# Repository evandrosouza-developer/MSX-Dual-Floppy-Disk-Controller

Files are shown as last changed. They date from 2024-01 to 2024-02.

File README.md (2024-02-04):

<div align="center">

**MSX Dual Disk Drive Controller**

**HB720**

***Based on Memory Mapped I/O Registers***

***Compatible with MSX1 class computers AND MSX2/MSX-DOS2.X***

</div>

**EPCOM/SHARP HB-3600**

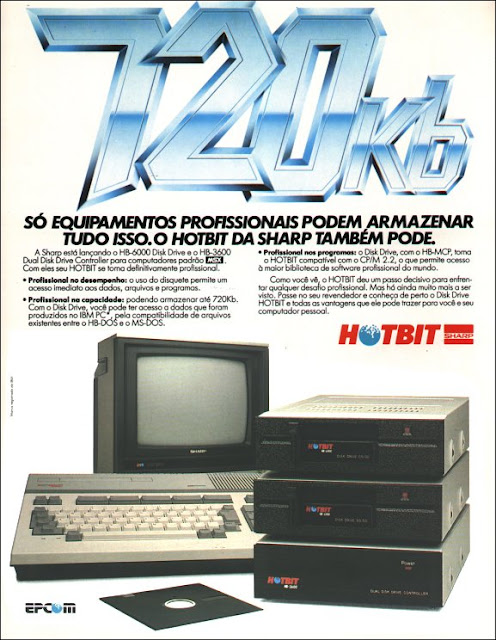
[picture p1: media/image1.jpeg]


**SONY HBD-50**

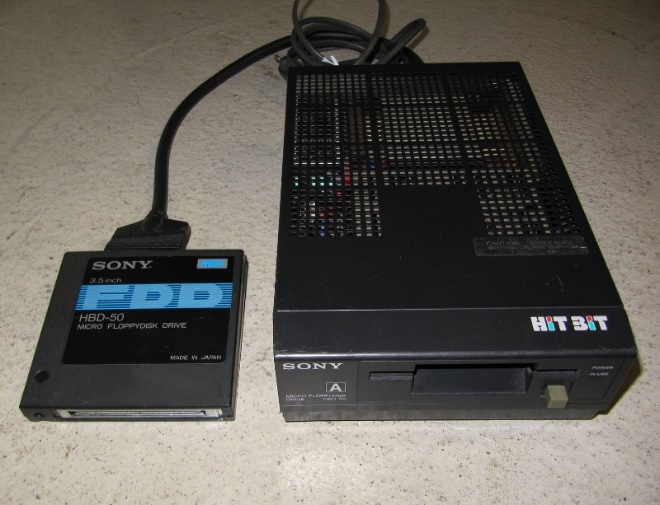
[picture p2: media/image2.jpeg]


***Based on MSXHans, 2001 PDF***

***By Evandro Souza 2024, January.***
  
---

## **THEORY OF OPERATION**

## **2-1. Cartridge Board**

## **2-1-1. MSX-DOS 1.X Version => Compatible with all MSX machines**

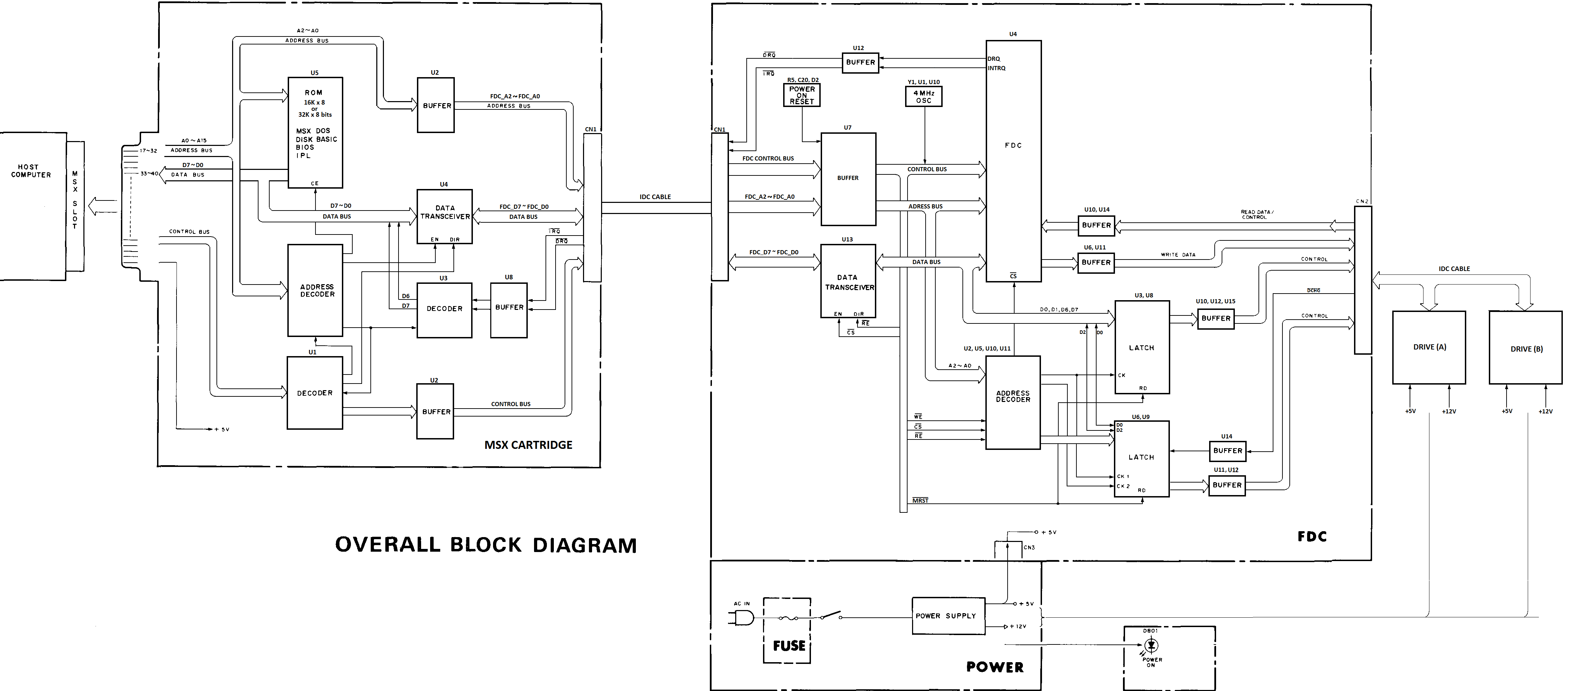
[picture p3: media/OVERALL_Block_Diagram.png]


**2-1-1-1. Memory Map**

This board cartridge uses the MSX computer cartridge slot. 16K ROM addresses 4000H through 7FFFH on the memory map have been allocated to the HB720 cartridge.

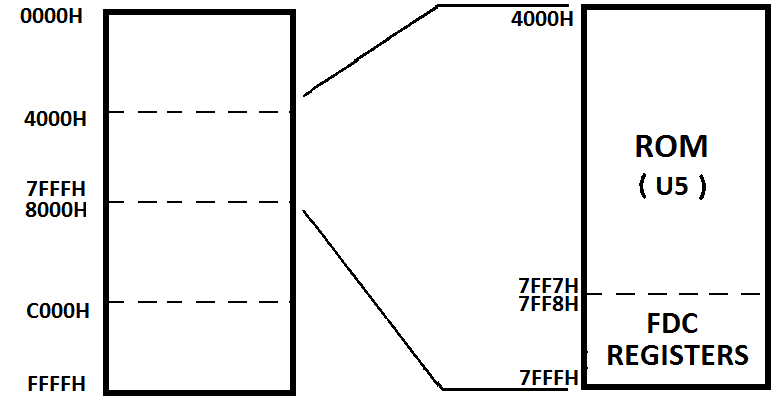
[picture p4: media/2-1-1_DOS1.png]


**2-1-1-2. Selection by HB720 Cartridge**

When the HB720 cartridge has been inserted into the MSX computer cartridge slot, 4000H-7FFFH address space will be selected by the cartridge connector signal CS1. In addition, U1 will AND signal SLTSL and the U2 (address decoder) output that has been inverted by U8, and will provide an output to U5 (ROM) pin CE for selection. All this signals are valid as 0, so the used logic port is an OR.

**2-1-1-3. Selection by FDC Controller**

Individual registers of the FDC board have been allocated to the memory space for addresses 7FF8H-7FFFH, and are selected by address signals A0 through A2 and signal FDC_CS.

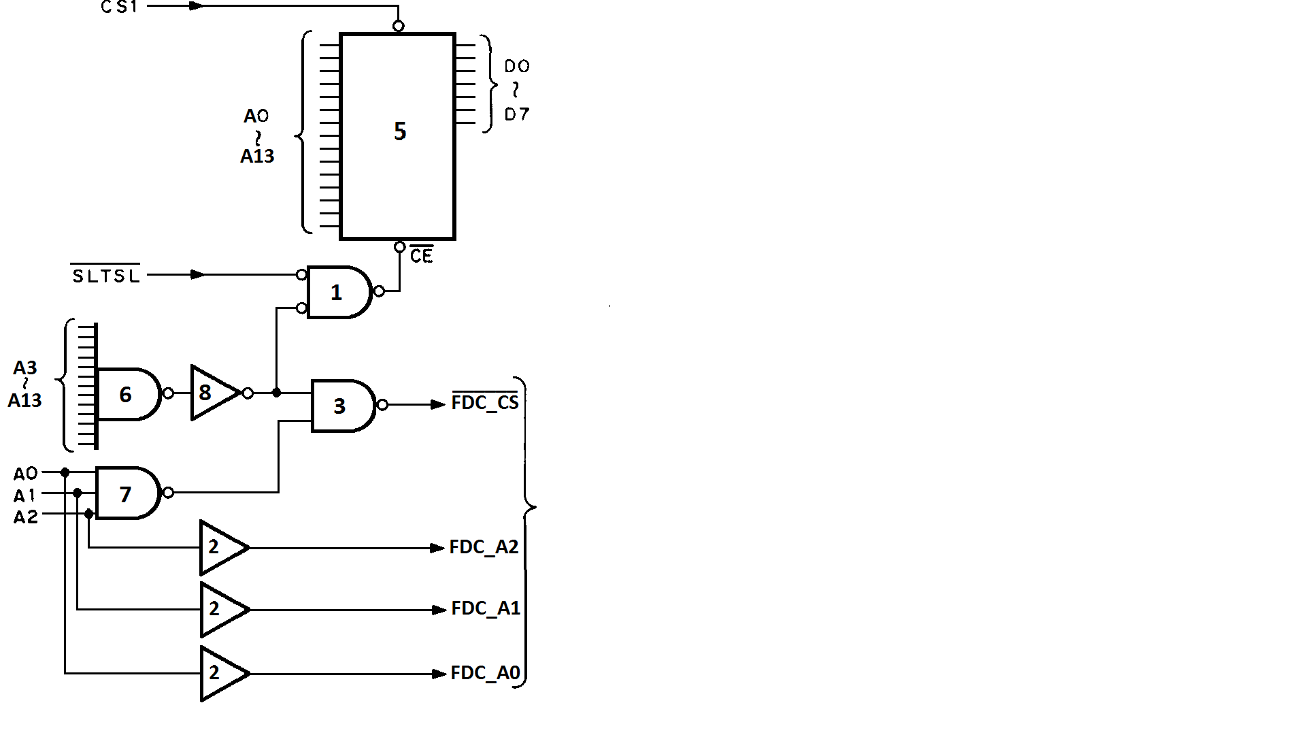
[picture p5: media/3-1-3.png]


**2-1-1-4. Memory Map of Control Ports in detail**

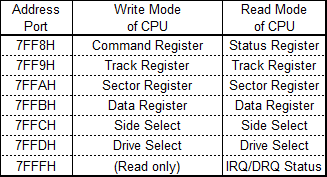
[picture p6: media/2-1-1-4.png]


---

## **2-1-2. MSX-DOS 2.X Version => Compatible with MSX 2.0 and up with Memory Mapper**

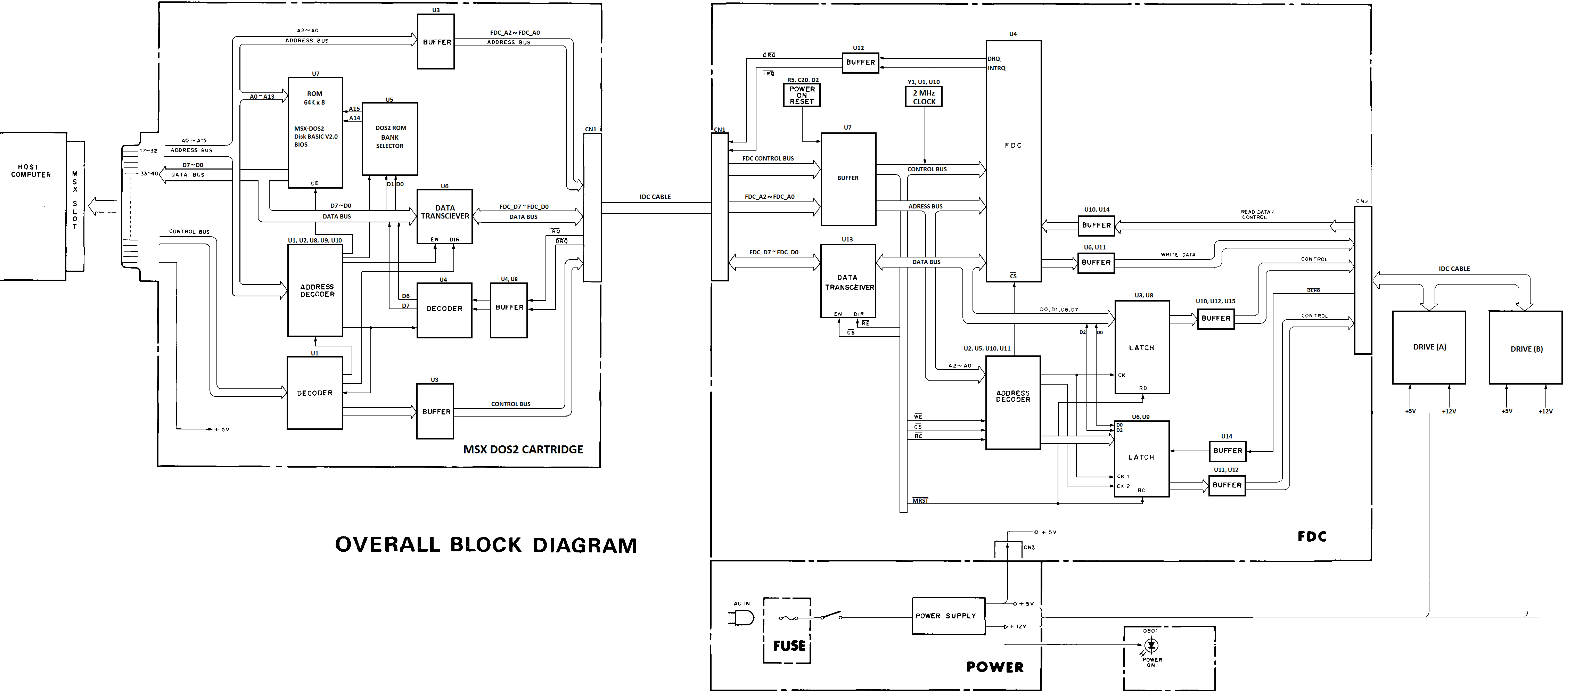
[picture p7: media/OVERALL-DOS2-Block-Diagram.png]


**2-1-2-1. Memory Map**

This board cartridge uses the MSX computer cartridge slot. The 64KB ROM is mapped into banks onto Z80 address space 4000H-7FFFH through U5 (ROM bank selector hardware that sends the A14 and A15 - the high order - bits to U7 ROM) will be selected by the cartridge connector signal CS1. In addition, U1 will AND signal SLTSL and the U2 (address decoder) output that has been inverted by U8, and will provide an output to U7 (ROM) pin CE for selection of the ROM. All this signals are valid as 0 (low), so the used logic port is an OR.

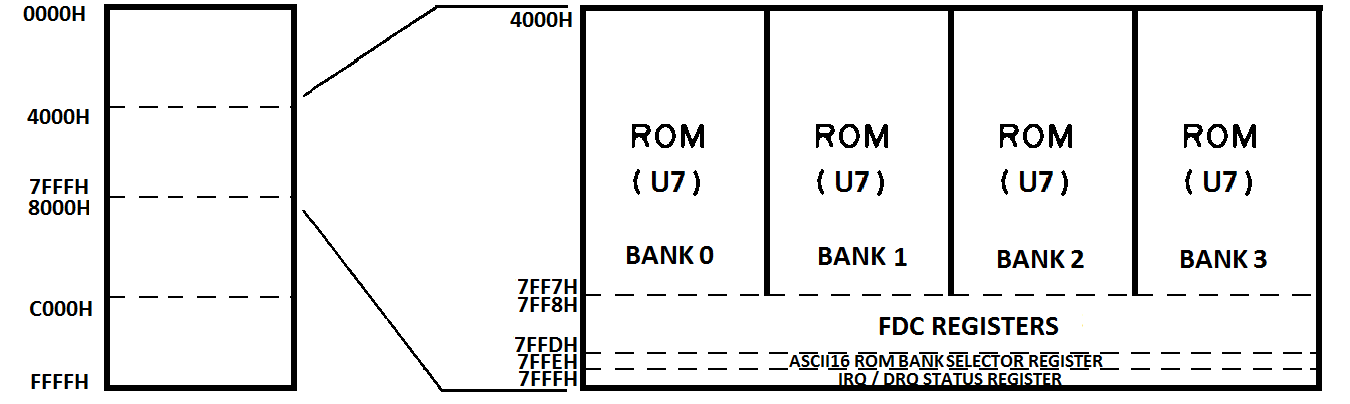
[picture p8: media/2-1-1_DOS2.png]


**2-1-2-2. Selection by HB720 Cartridge**

When the HB720 cartridge has been inserted into the MSX computer cartridge slot, addresses 4000H through 7FFFH will be selected by the cartridge connector signal CS1. U1 will AND signal SLTSL and the U2 (address decoder) output that has been inverted by U8, and will provide an output to U7 (ROM) pin CE for selection of the ROM.

**2-1-2-3. Selection by FDC Controller**

Individual registers of the FDC board have been allocated to the memory space for addresses 7FF8H through 7FFFH, and are selected by address signals A0 through A2 and signal FDC_CS.

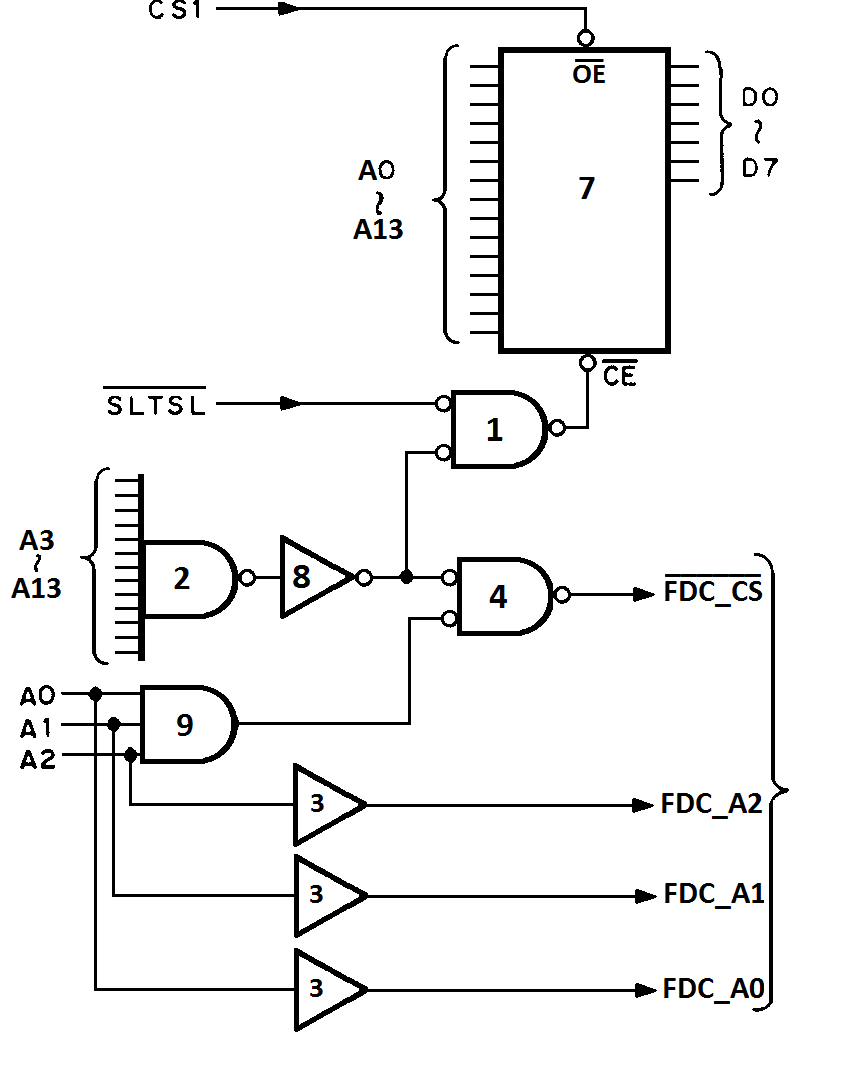
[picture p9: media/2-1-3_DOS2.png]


**2-1-2-4. Memory Map of Control Ports in detail**

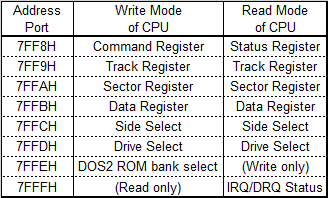
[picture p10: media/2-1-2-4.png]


## **2-2. FDC BOARD - THE COMMON PART**

**2-2-1. Selection of Individual FDC chip Registers**

Individual registers of the FDC (U4) have been allocated to addresses 7FF8H through 7FFBH, and are selected by address signals AO through A2 and signal CS.

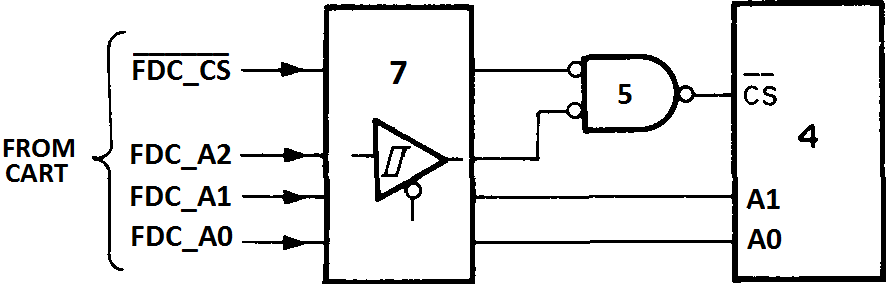
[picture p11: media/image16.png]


CR (COMMAND REGISTER)

DR (DATA REGISTER)

DSR (DATA SHIFT REGISTER)

SCR (SECTOR REGISTER)

TR (TRACK REGISTER)

STR (STATUS REGISTER)

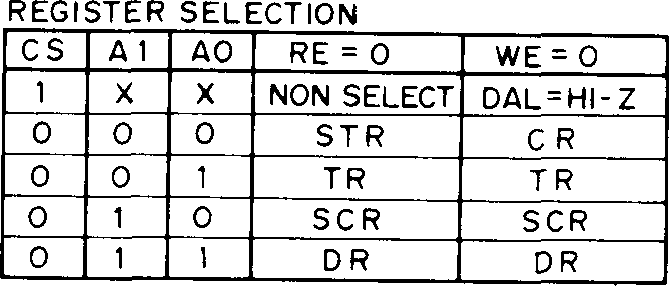
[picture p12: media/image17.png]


0    (LOW LEVEL)

1    (HIGH LEVEL)

HI-Z (HIGH IMPEDANCE)

**2-2-2. Operation of Individual Registers**

-   Command Register (CR) - 7FF8H

This is an 8-bit write register, where the commands that correspond to the WD2793-02 operation will be written from the processor.

With the exception of a forced interrupt command, the command writing operation takes place after completion of the previous WD2793-02 command.

-   Status Register (STR) - 7FF8H

This is an 8-bit read register. This register indicates the WD2793-02 internal status, the command execution processed status, and the disk drive status. The significance of individual bits will vary depending on whether the command is being executed or the command execution has already been concluded.

-   Track Register (TR) - 7FF9H

This is an 8-bit read/write register. The low-high transition of MR (master reset) will set TR at FFH. When TR00 becomes low, TR will be made 00H.

The track number at which the head is located will usually be set in this register. At WD2793-02, this value may either be updated or not, depending on the command. In the case of a read data command or a write data command, the contents of this register will be compared with an ID field track number read of the disk, and when they coincide with each other, the read or write operation will duly be carried out.

-   Sector Register (SCR) - 7FFAH

This is an 8-bit read/write register. In the case of a read data command or a write data command, the contents of this register will be compared with an ID field track number read of the disk, and when they coincide with each other, the read or write operation will duly be carried out.

When under a read address command, the ID field track number will be retained intact.

-   Data Register (DR) - 7FFBH

This is a read/write register. In a disk reading mode, the data read of the disk will be loaded into this register. In a disk writing mode, the data that has been written earlier into this register will be written into the disk. In a seek mode, the target track address will be written this register.

-   Side Select - 7FFCH



At \"0\", side 0 will be selected, and at \"1\", side 1 will be selected

-   Drive Select - 7FFDH

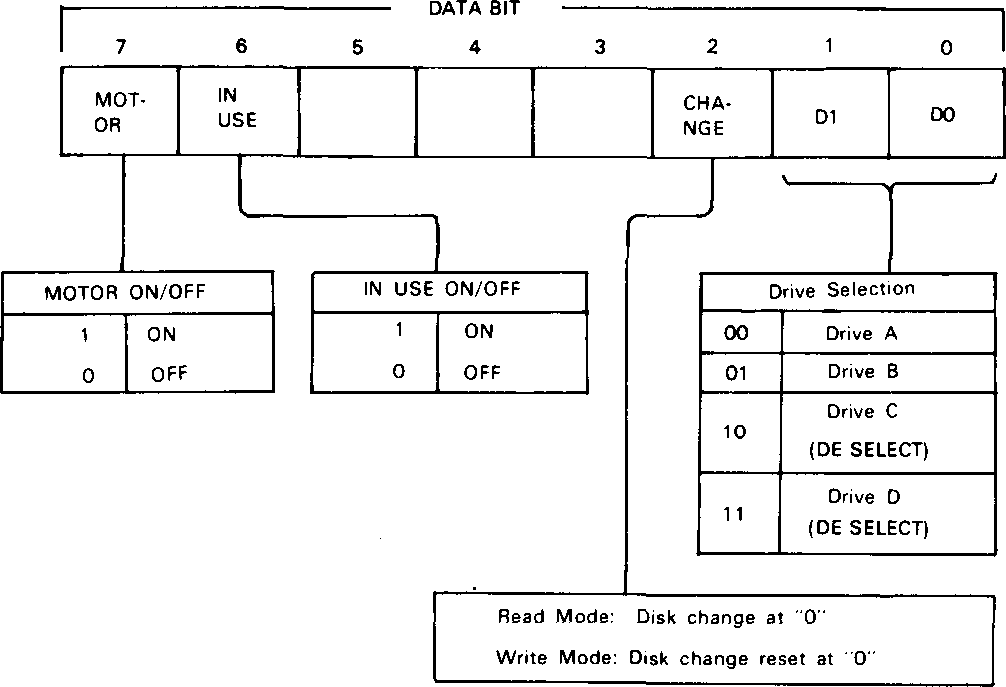
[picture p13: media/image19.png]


-   ASCII16 - DOS2 ROM Bank Selector - 7FFEH (Only DOS 2.X Model)

This is a write only register - and returns a dummy value if read.

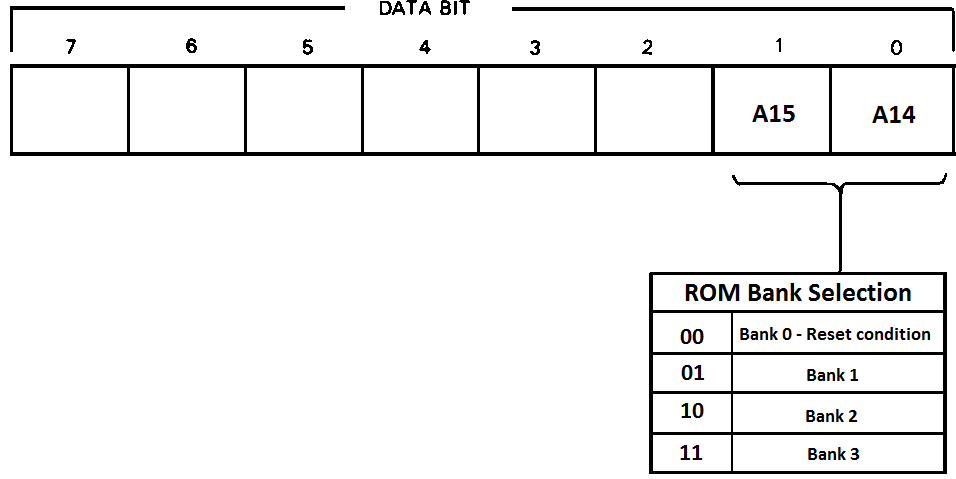
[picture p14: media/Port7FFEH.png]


-   IRQ/DRQ Status - 7FFFH



IRQ will be made \"0\" when the completion of a command has been > either concluded or terminated during process.
DRQ will be made \"0\" when the data write/read are being requested.

---

## **HB720 Boards**

**SCHEMATIC DIAGRAM AND PRINTED CIRCUIT BOARD**

I shared here a full set of Gerber files of the three boards, to allow direct order the PCB's to manufacturers. They are all inside gerber directory.

**CARTRIDGE BOARD DOS1.X VERSION:**

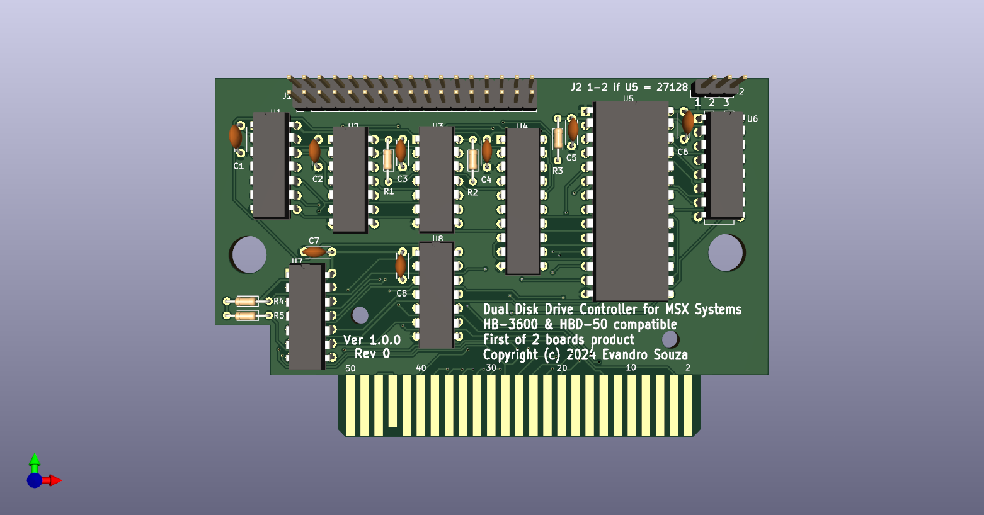
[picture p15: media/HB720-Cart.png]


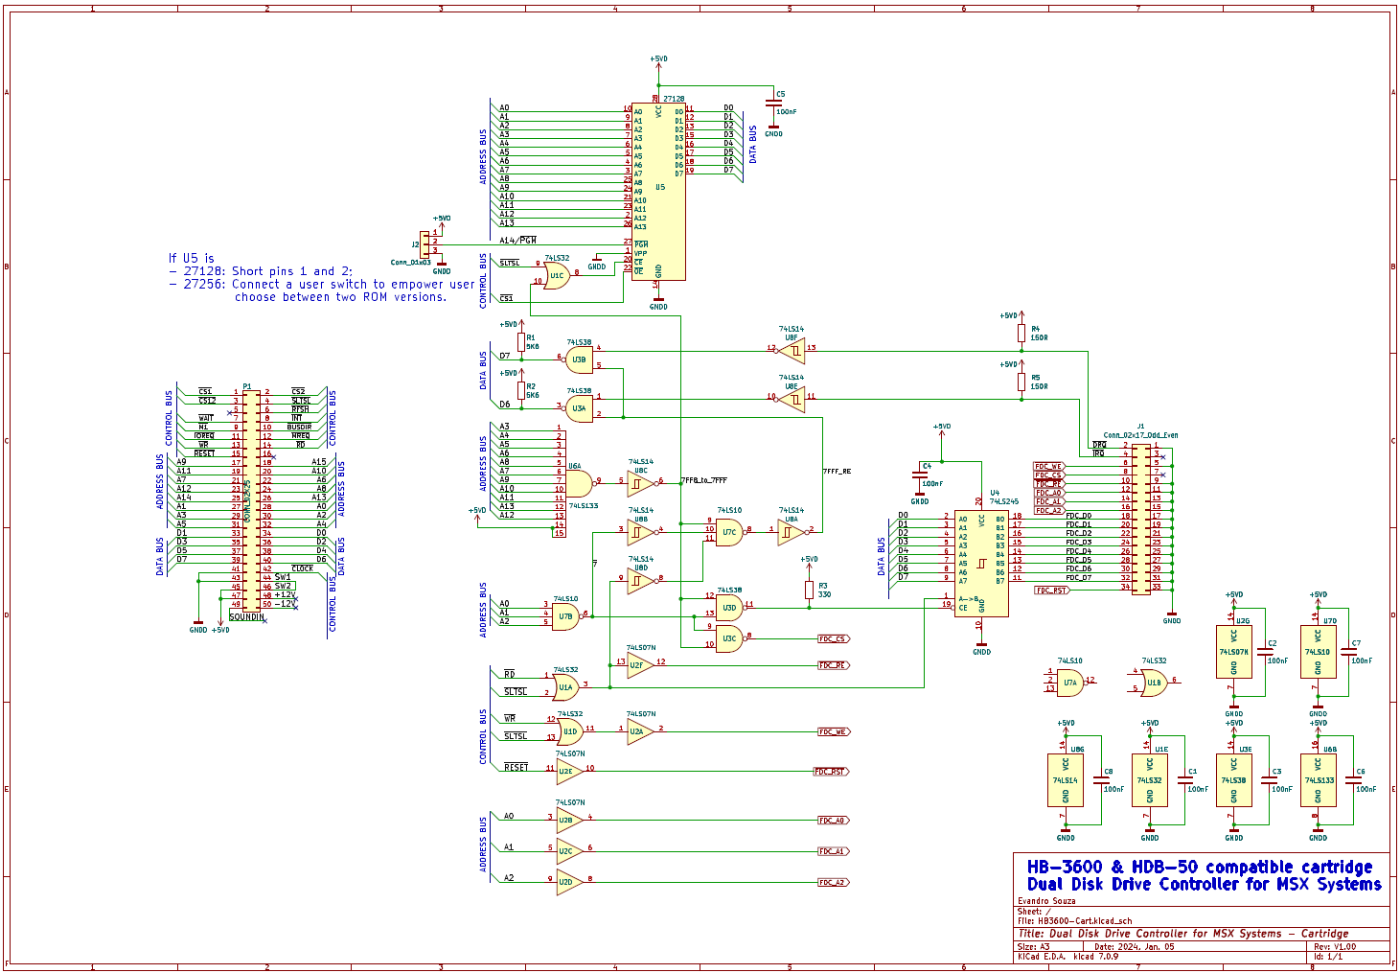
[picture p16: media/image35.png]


**CARTRIDGE BOARD DOS2.X VERSION:**

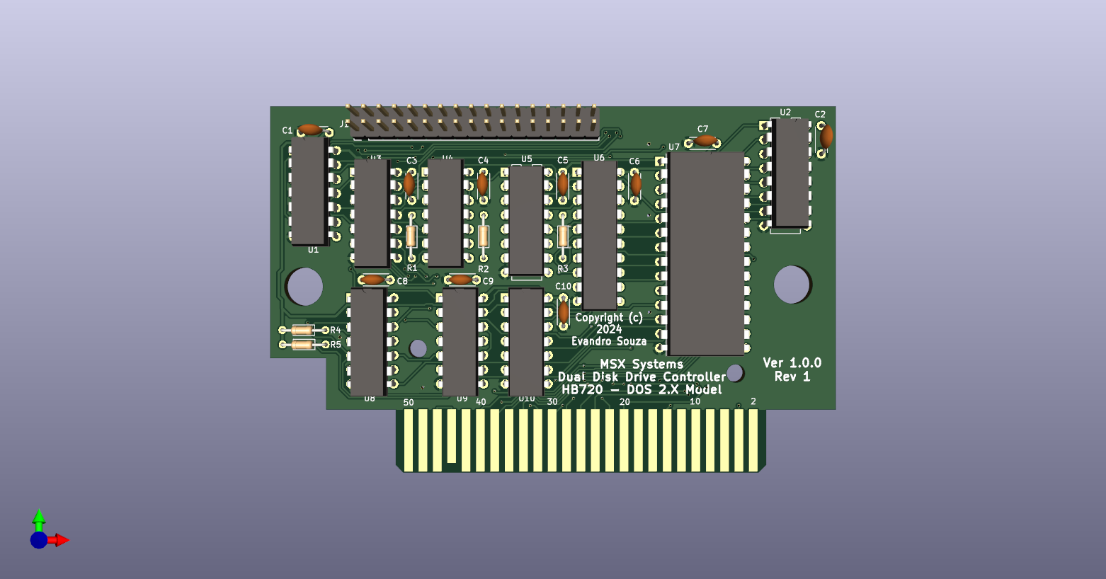
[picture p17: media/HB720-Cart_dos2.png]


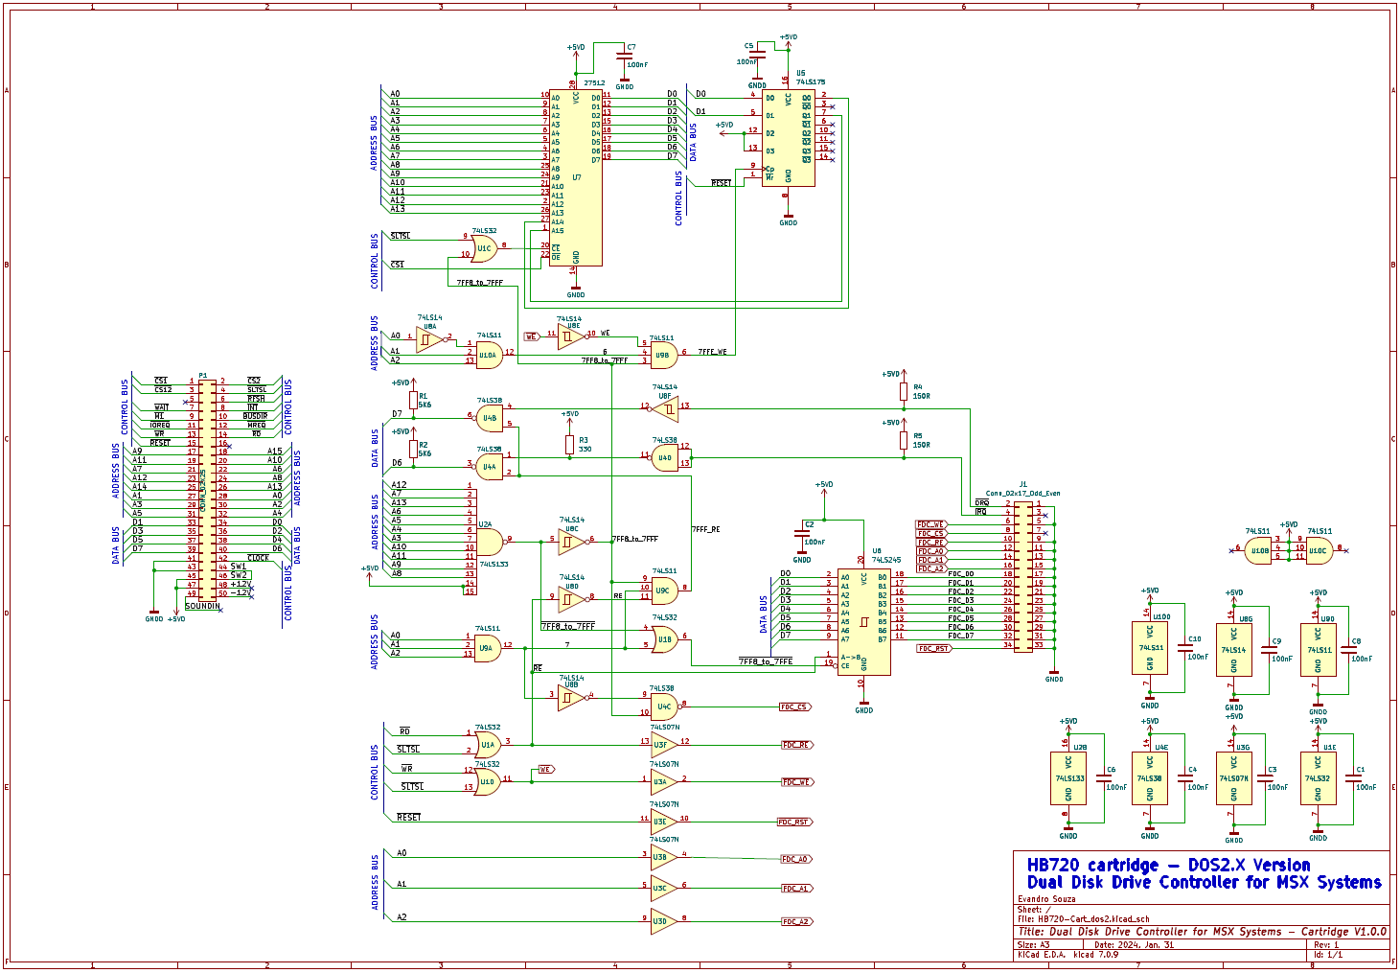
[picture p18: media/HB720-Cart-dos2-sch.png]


**FDC Board - THE COMMON PART:**

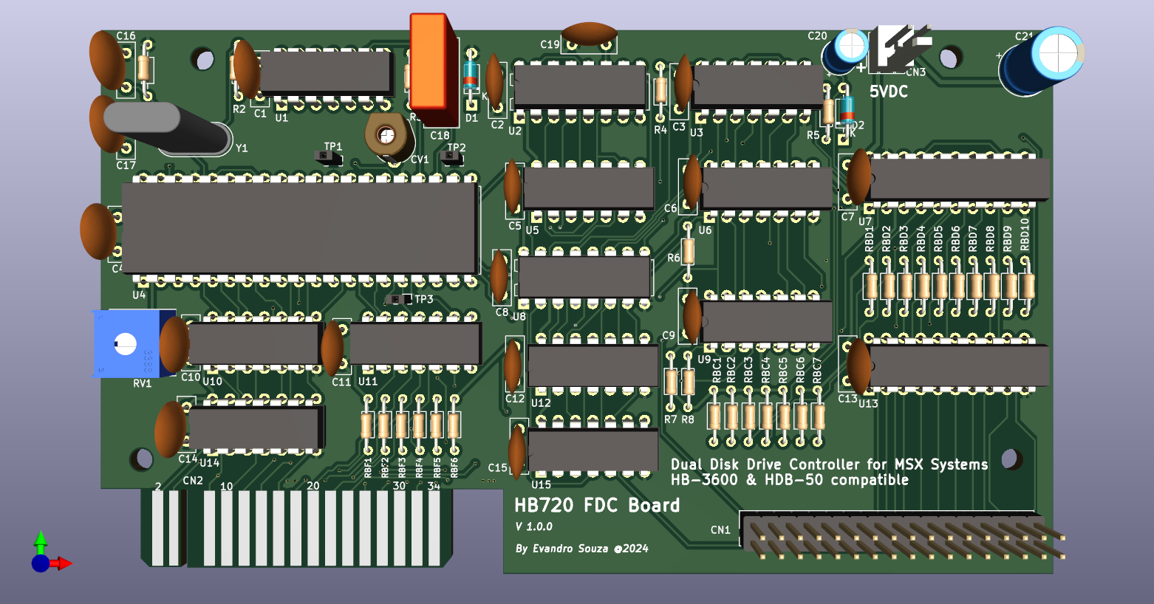
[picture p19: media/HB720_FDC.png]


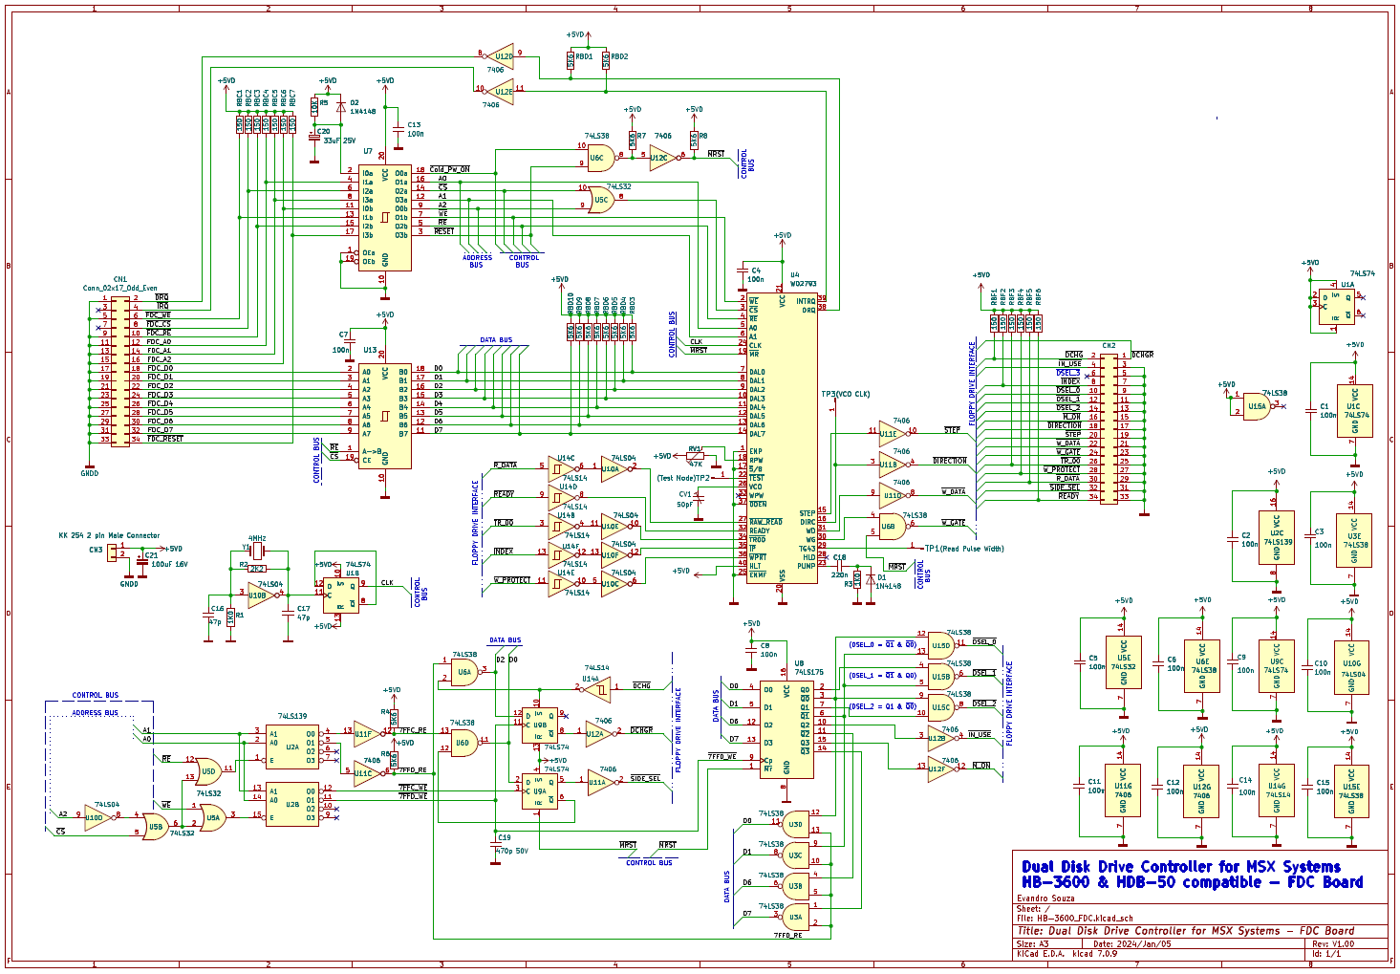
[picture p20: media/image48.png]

---
** PIN ASSIGNMENT OF THE CONNECTORS**
>
> **Pin Assignment of the Connectors**
>
> HB720 CARTRIDGE TO FDC: IDC 34 pins connector (BOTH SIDES)
>

  ```
  ---------------------------------------------------------------------------------
  Pin   Signal       Pin   Signal         Pin   Signal       Pin No. Signal
  No.                No.                  No.                        
  ----- ------------ ----- -------------- ----- ------------ ------- --------------
  1     GNDD         10    FDC_RE         19    GNDD         28      FDC_D5
        (RETURN)                                (RETURN)             

  2     DRQ          11    GNDD (RETURN)  20    FDC_D1       29      GNDD (RETURN)

  3     N.C.         12    FDC_A0         21    GNDD         30      FDC_D6
                                                (RETURN)             

  4     IRQ          13    GNDD (RETURN)  22    FDC_D2       31      GNDD (RETURN)

  5     GNDD         14    FDC_A1         23    GNDD         32      FDC_D7
        (RETURN)                                (RETURN)             

  6     FDC_WE       15    GNDD (RETURN)  24    FDC_D3       33      GNDD (RETURN)

  7     N.C.         16    FDC_A2         25    GNDD         34      RESET
                                                (RETURN)             

  8     FDC_CS       17    GNDD (RETURN)  26    FDC_D4       None    NONE

  9     GNDD         18    FDC_D0         27    GNDD          None   NONE
        (RETURN)                                (RETURN)             
  ---------------------------------------------------------------------------------
  ```

> HB720 FDC TO EXT FLOPPPY DRIVE -- Edge card connector (34 pins)

-   The pinout are the same for 5 ¼" and 3 ½" drives and the cable may
    have both options:

    -   To use with 5 ¼", the connector is a card edge;

    -   To use with 3 ½" the connector is a 34 pin female IDC.
```
  ---------------------------------------------------------------------------------
  Pin   Signal         Pin   Signal       Pin   Signal      Pin    Signal
  No.                  No.                No.               No.    
  ----- -------------- ----- ------------ ----- ----------- ------ ----------------
  1     DISK CHANGE    10    DRIVE SELECT 19    GNDD        28     WRITE PROTECT
        RESET                0                  (RETURN)           

  2     DISK CHANGE    11    GNDD         20    STEP        29     GNDD (RETURN)
                             (RETURN)                              

  3     GNDD (RETURN)  12    DRIVE SELECT 21    GNDD        30     READ DATA
                             1                  (RETURN)           

  4     IN USE         13    GNDD         22    WRITE DATA  31     GNDD (RETURN)
                             (RETURN)                              

  5     GNDD (RETURN)  14    DRIVE SELECT 23    GNDD        32     (HEAD SELECT)
                             2                  (RETURN)           

  6     DRIVE SELECT 3 15    GNDD         24    WRITE GATE  33     GNDD (RETURN)
                             (RETURN)                              

  7     GNDD (RETURN)  16    MOTOR ON     25    GNDD        34     READY
                                                (RETURN)           

  8     INDEX          17    GNDD         26    TRACK 00    None   NONE
                             (RETURN)                              

  9     GNDD (RETURN)  18    DIRECTION    27    GNDD        None   NONE
                                                (RETURN)           
  ---------------------------------------------------------------------------------

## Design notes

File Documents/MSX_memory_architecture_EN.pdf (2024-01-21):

# MSX Memory Architecture

MSX Memory Architecture

Index

5.4. Page2/Page3 slot detection | 83
5.5. Page0/Page3 slot switching | 89
6. Other supplementary matters | 98
6.1. EXPTBL when using version upgrade adapter | 98
6.2. Do not write the expansion slot selection register unconditionally.........99
Appendix | 104
Appendix 1. Various sources used by the sample program | 104

### 1. Introduction

This book is a summary of the ROM/RAM of the MSX. I decided to write this book because there are many different ROM/RAMs in the MSX and I have not seen any material describing them all in one place.

For the MSX alone, there is a wide range of memory space switching between basic and expansion slots, mapper segment switching using memory mapper-compatible RAM, and Panasonic-specific megarom bank switching for MSX2+ and later Panasonic machines. In addition to this, the mega-ROMs installed in the cartridge slots (ASCII-8K, ASCII-16K, Konami-8K, Konami-SCC, Konami-SCC-
I) and Panamusement cartridges are also described. I have tried to cover all the major ones. Minor items are omitted because they are already difficult to obtain or there is no information to control them.

I hope this will be helpful for those who are going to create software for MSX.

Please note that there are some differences from the Zilog mnemonic. ZMA is a free software distributed at the following site:

ZMA distribution site

https://github.com/hra1129/zma

### 1.1. Terminology

MSX memory (slot, memory mapper, megarom) is managed by dividing the physical ROM and RAM address space into 16KB or 8KB units. In the Z80 memory space, these "16KB or 8KB areas" appear and are accessed. The address range in the Z80 memory space where the "16KB unit or 8KB unit area" appears, as well as the name of the "16KB unit or 8KB unit area" itself, is somewhat ambiguous, and may be described with a unique name depending on the document referred to. For example, we have confirmed that there are some documents that describe the "16 KB unit or 8 KB unit area" as a segment and others that describe it as a bank. In Document A, both the "16 KB unit area" of the memory mapper and the "16 KB unit or 8 KB unit area" of the megarom were described as segments. On the other hand, in Document B, the "16 KB unit area" of the memory mapper is a segment and the "16 KB unit or 8 KB unit area" of the megarom is a bank. In Document C, both the "16 KB unit area" of the memory mapper and the "16 KB unit or 8 KB unit area" of the megarom are described as banks. As such, they are not uniquely named.

In order to avoid misunderstandings, the following names are used consistently in this document. When referring to other materials, it may help to avoid confusion if you consider the possibility of other names being used.

Category | Overview | Notation
Slot | Address area in 16 KB units where the specified slot appears | PageN
Slot | Register that specifies the basic slot # appearing in Page0-3 of the memory space visible from the Z80 | Basic slot selection register
Slot | Register to specify the expansion slot # that appears in Page0-3 of the basic slot that is being eyed. | Expansion slot selection register
Memory Mapper | Memory mapper switching unit (16KB) | Segment#N
MegaROM | An address area in which the address of the slot in which the megarom is installed is divided into 8 KB or 16 KB units. | BANKN
MegaROM | A portion of the ROM that appears in the above bank | BANK#N

For example, if it says, "Make BANK#23 appear in BANK0," it is talking about megarom. If it says, "Make Segment#31 appear in Page1," it is talking about a memory mapper.

### 2. Slot

The Z80, the CPU of the MSX, has 64KB of memory space, but if you make the ROMs for the BIOS, internal software, etc. visible at the same time, it quickly becomes too small. Therefore, the MSX introduced the concept of slots, which allows up to 256KB of space to be handled. This "slot concept" is called the basic slot.

One basic slot can be further expanded into "four slots". These four expanded slots are called expansion slots. If all the basic slots are expanded, a total of 1MB of space can be handled. Considering the time when the first MSX was released, it was able to handle a vast amount of space, which was advanced for its time. The details are described below.

### 2.1. Basic Slot

As shown in Figure 2-1, the 64KB space is divided into 16KB areas called Pages.

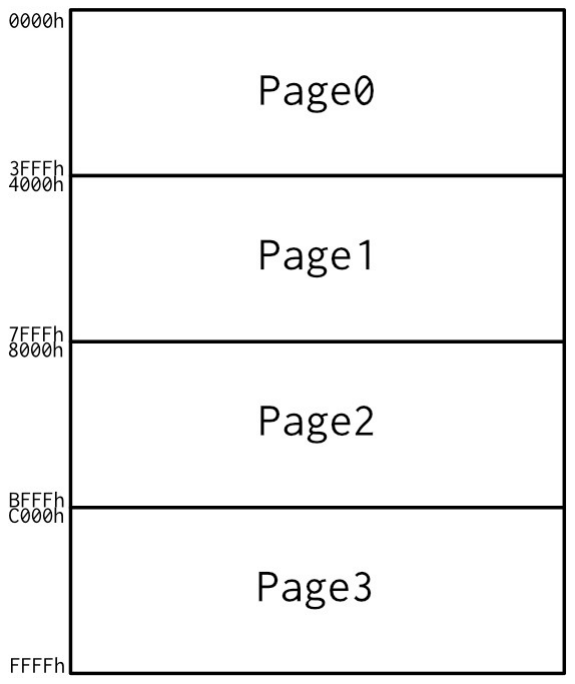
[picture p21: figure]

Figure 2-1: Page area classification visible in the Z80 memory space

Four basic slots exist for each of these pages, and the basic slot selection register is used to select which basic slot should appear for each page. The image is shown in Figure 2-2.

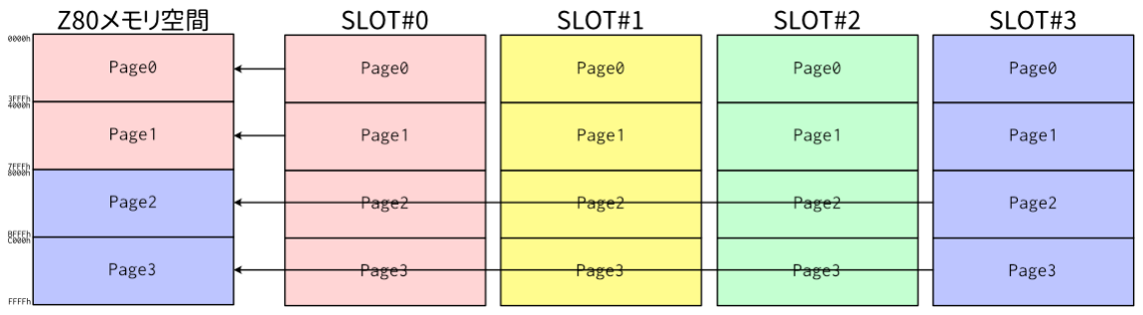
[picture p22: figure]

Figure 2-2: Basic slot selection

Figure 2-2: The arrow in the slot selection register corresponds to the basic slot selection register. This basic slot selection register is connected as a register that can be read and written to A8h in I/O space. The 8-bit value that can be written to I/O A8h corresponds to, as shown in Figure 2-3, slot # where bit1 and bit0 appear in Page0, slot # where bit 3 and bit2 appear in Page1, slot # where bit 5 and bit4 appear in Page2, and slot # where bit 7 and bit6 appear in Page3.

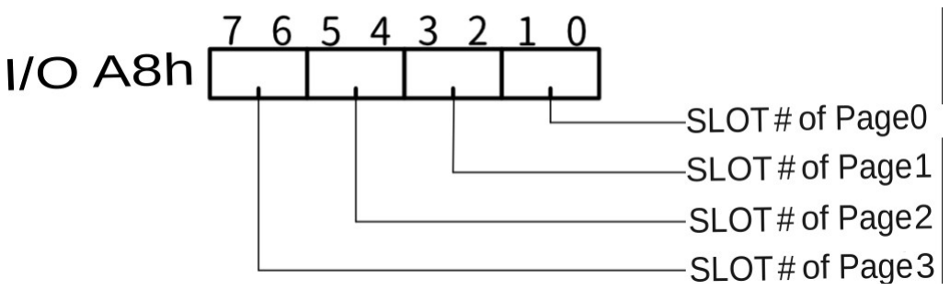
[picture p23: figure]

Figure 2-3: Basic Slot Select Register (I/O A8h)

The basic slot selection register can also be read from MSX-BASIC; Figure 2-4 shows an image of the register read by the FS-A1GT.

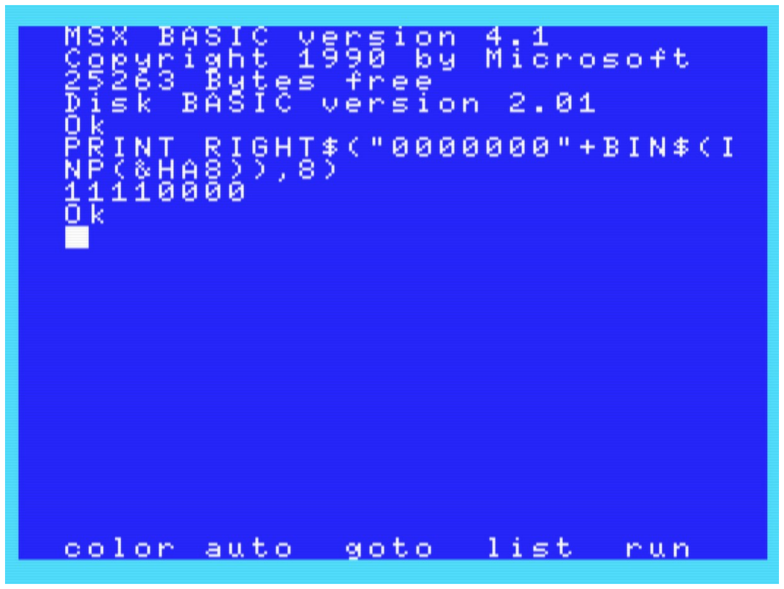
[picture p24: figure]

Figure 2-4: Reading the Basic Slot Selection Register from MSX-BASIC on FS-A1GT

This means that Page0 is "00" and therefore SLOT#0, Page1 is also "00" and therefore SLOT#0, Page2 is "11" and therefore SLOT#3, Page3 is also "11" and therefore SLOT#3.

In general, SLOT#1 will appear as cartridge slot 1, and SLOT#2 will appear as cartridge slot 2. In some cases, the slot # on the program does not match the cartridge slot # stamped on the main unit, or even SLOT#3 appears outside as a cartridge slot.

Although MSX-BASIC can write to A8h using the OUT instruction, switching to another slot may cause MSX-BASIC to run out of control because MSX-BASIC itself resides on MAIN-ROM appearing on Page0 and Page1, BASIC programs are stored in RAM appearing on Page2 and Page3, and MSX-BASIC and BIOS work areas are stored in RAM appearing on Page3. BASIC and BIOS work areas are stored in RAM appearing on Page3, switching to another slot may cause MSX-BASIC to run out of control.

The slot switching is also related to the expansion slot, see also 2.2. Expansion slots.

### 2.2. Expansion slots

2.1. Basic Slot: I explained that each Page selects one of the four slots to appear in the Z80 memory space. Expansion slots refer to a mechanism that further expands this one basic slot to four.

Base slots are not necessarily expanded. Cartridge slots are generally basic slots. Peripheral devices called expansion slot units can be installed in the cartridge slots to increase the number to four, but this expansion slot unit uses the expansion slot mechanism described in this section.

Slots hidden inside the main unit (SLOT#0 and SLOT#3) may be expanded. (It does not mean that something as large as an expansion slot unit is included in the main unit, and it means that the internal logic is equivalent.)

The expansion slot selection register determines which of the four expansion slots is connected to Page 0-3 of the expanded slots. It resides at FFFFh of that slot. The expansion slot selection register is mapped onto memory instead of I/O.

This image is shown in Figure 2-5.

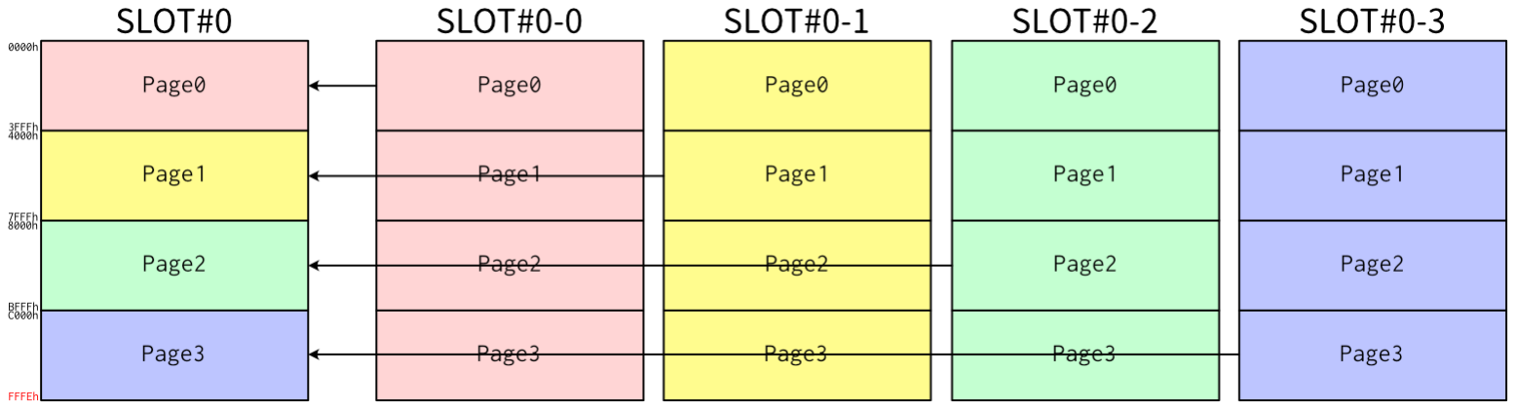
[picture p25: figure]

Figure 2-5: Image of expansion slot

Figure 2-5 shows an example where the basic slot SLOT#0 is expanded. SLOT#0-0, SLOT#0-1, SLOT#0-2, SLOT#0-3 exist as expansion slots of SLOT#0. The concept is almost the same as the basic slot, but the point to note

is that Page3 is up to FFFEh. The expansion slot selection register is connected to FFFFh of SLOT#0, and FFFFh of expansion slots SLOT#0-X cannot be accessed.

A bitmap of the Expansion Slot Select Register FFFFh is shown in Figure 2-6.

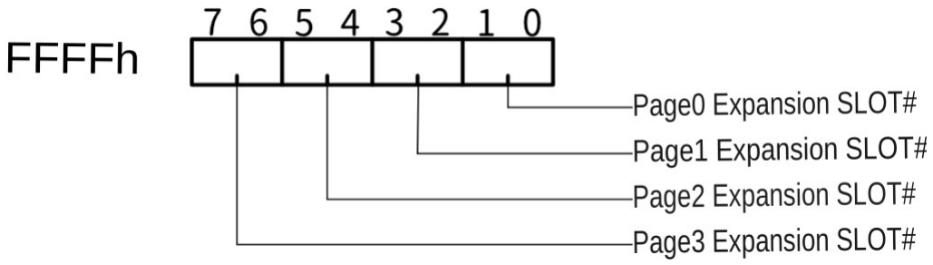
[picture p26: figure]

Figure 2-6:Expansion slot selection register

The value to write is similar to the basic slot selection register. However, when it is read, the value in which all bits are inverted can be read. This seems to be so for the purpose of determining whether this base slot has been expanded.

If SLOT#1 is not extended and a 64KB-RAM cartridge is installed, writing value A to FFFFh and reading it will read value A as is. On the other hand, if SLOT#1 is expanded, even if a 64KB-RAM cartridge is installed in SLOT#1-0, if the value A is written to FFFFh of SLOT#1, it will not be written to the expansion slot selection register, and reading from FFFFh returns the inverse of the expansion slot selection register. In other words, since the value A was written, all bits of the value A are read out. The BIOS checks for the presence of an expansion slot by taking advantage of the inverted value read in the case of this expansion slot selection register.

The results of the investigation are stored in EXPTBL (FCC1h to FCC4h) shown in Figure 2-7.

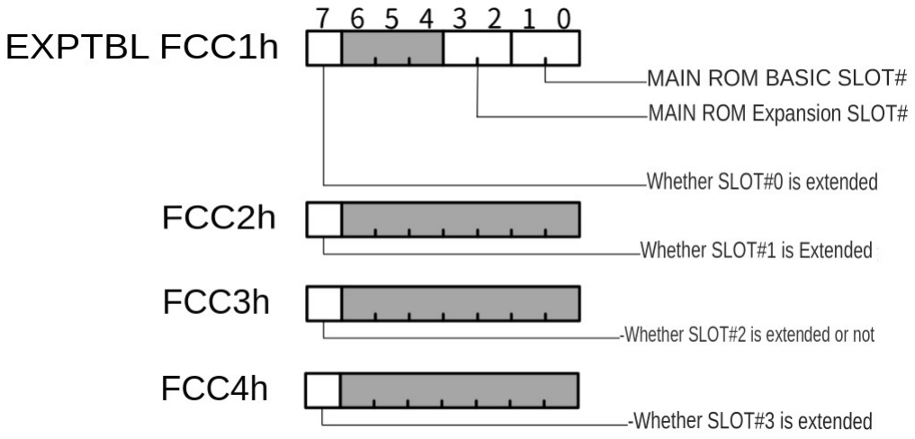
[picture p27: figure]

Figure 2-7. EXPTBL

The contents of EXPTBL are written by the BIOS according to the bit arrangement shown in Figure 2-7 immediately after starting MSX. The MAIN-ROM slot # stored in FCC1h is usually a value that indicates his SLOT#0 or SLOT#0-0, but don't make a decision, read this value and use the MAIN-ROM It is safe to use it as a slot. (For example, when using the MSX version upgrade adapter, the slot value other than SLOT#0 is stored.)

An expansion slot selection register exists for each basic slot to which an expansion slot is connected. For example, if SLOT#0 and SLOT#3 are extended, FFFFh of SLOT#0 contains the expansion slot selection register for slot 0, and FFFFh of SLOT#3 contains the expansion slot selection register for slot 3. I'm here. As some of you may have noticed by reading this, in order to switch the expansion slot, you must switch Page3 to that slot and make the expansion slot selection register appear at his FFFFh in the Z80 memory space. . On the other hand, Page3 usually has stack memory and BIOS work area, so if you switch carelessly, it will run out of control. Therefore, the BIOS provides slot switching routines for easy and safe switching. The next section describes such
2.3. slot-related BIOS routines.

### 2.3. Slot-related BIOS routines

Slot-related BIOS routines are described separately here.

RDSLT (000Ch)

Reads the specified address 1 byte of the specified slot.

Input:

A register: Value indicating "specified slot".

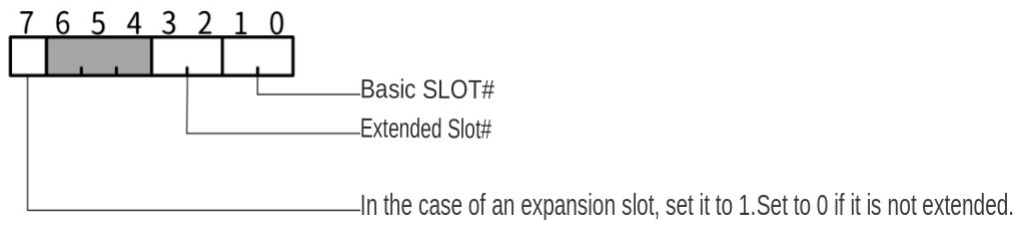
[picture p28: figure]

HL Register: A value that indicates a "designated address".

Output:

A Register: read value.

Detailed:

Calling this routine will destroy the AF, BC and DE registers.

The value of the A register specified before calling specifies whether or not there is an extension slot in bit7. In short, specify bit7 of the value stored in (FCC1h + target basic slot #) as it is. And set the target basic slot # to bit1, bit0. Specify the expansion slot # to bit3, bit2. SLOT#3-2 would be 10001011. 8Bh in hexadecimal notation.

BIOS switches the page corresponding to the upper 2 bits of the HL register to the slot indicated by the A register, then LD A,(HL) and restores the slot.

Use it as follows:

LD | HL, 0x1234
LD | A, 0x8B
CALL | 0x000C
RET
This will read the 1-byte value at address 1234h of SLOT#3-2 and return it to the A register.

WRSLT (0014h)

Writes 1 byte of the specified value to the specified address in the specified slot.

Input:

A register: Value indicating "specified slot".

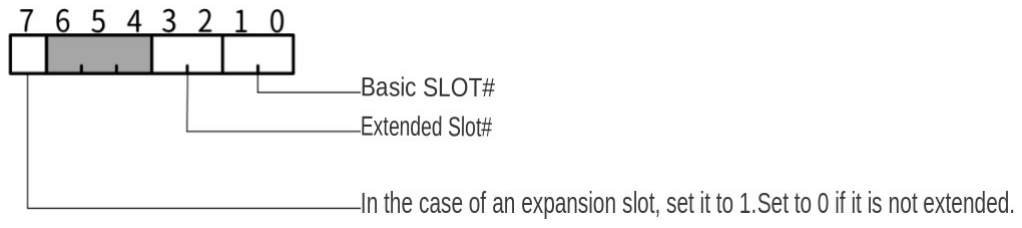
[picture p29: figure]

HL Register: value indicating "specified address".

E Register: A value that indicates a "specified value".

Output:

none

Detailed:

Calling this routine destroys the AF, BC, and D registers.

The method of specifying the slot is the same as RDSLT, so please refer to the explanation there.

The BIOS switches the page corresponding to the upper 2 bits of the HL register to the slot indicated by the A register, then LD (HL),E and then returns the slot.

Use it as follows.

LD | HL, 0x1234
LD | A, 0x8B
LD | E, 0xAB
CALL | 0x0014
RET
With this, ABh is written to 1234h address of SLOT#3-2.

CALSLT (001Ch)

Makes a subroutine call to the specified address of the specified slot (called an inter-slot call).

input:

IY register: Stores the value indicating the "specified slot" in the upper 8 bits. Lower 8 bits are ignored.

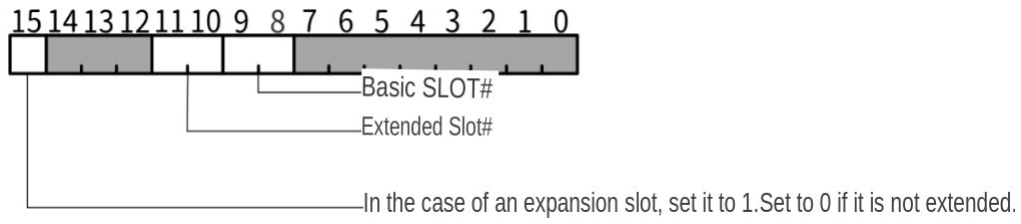
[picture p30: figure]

IX Register: A value that indicates the "specified address (subroutine address)".

Other registers: parameters of the subroutine to call.

output:

By subroutine you call.

detailed:

This routine calls the "specified address (subroutine address)" after switching the page corresponding to the "specified address (subroutine address)" to the "specified slot". Next, it returns the Page corresponding to the "specified address (subroutine address)" to the original slot.

The registers destroyed when calling this routine depend on the subroutine it calls.

For example, when the MSX-DOS application is started, Page0-3 are all in RAM, but you can use it when you want to call the BIOS routine of MAIN-ROM. Page0 during MSX-DOS operation is RAM, but slot-related subroutine calls exist at the same addresses as the BIOS and are available.

You can call BIOS routine CHGMOD (005Fh) to switch SCREEN mode from MSX-DOS application with code like below.

LD | A, 1 | ; switch to SCREEN1
LD | IY, [0xFCC1 - 1] | ; MAIN-ROM Slot to upper 8bit of IY
LD | IX, 0x005F
CALL | 0x001C

ENASLT (0024h)

Disables interrupts and switches the specified Page to the specified slot. Returns with interrupts disabled.

Input:

A register：A value that indicates "specified slot".

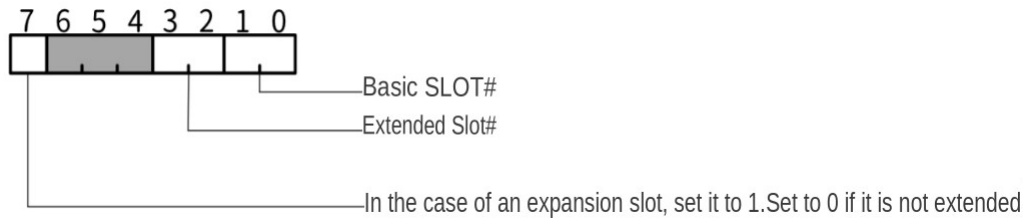
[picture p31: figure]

H Register: Specify the target page with the upper 2 bits.

Output：

none

Detailed：

All registers are destroyed.

If you use an inter-slot call, you can use the subroutine call of another slot, but each time you switch the slot and return again, and so on. It becomes very inefficient in cases where subroutine calls, reads, and writes are frequently performed on the same slot. Therefore, you can reduce the frequency of slot switching by using ENASLT to switch slots, perform the necessary subroutine calls, reading and writing, and then return to the slot with ENASLT.

Slot switching is a process that requires a certain amount of load, so in cases where other slots are called in places that require processing speed, such as the main loop of the game, ENASLT's minimum You should consider switching limits.

ENASLT returns with interrupts disabled. This is a protective measure to avoid a runaway problem due to the interrupt handler routine changing to a different slot configuration than expected. If countermeasures are taken in the interrupt processing itself, EI can be performed immediately after returning from ENASLT.

Of course, when the program that calls ENASLT is in Page1, if you switch the Page1 slot, when you return from ENASLT, it will return to another code and run out of control, so please keep that in mind when using it.

Also, please do not switch Page 3. The body of the slot switching routine is often located on Page3's RAM, and the stack memory is also located on Page3.

By doing the following, the first 8KB of the ROM cartridge installed in SLOT#1 can be copied to Page2 from MSX-DOS.

LD | A, [0xFCC2] | ; Get extension of SLOT#1
AND | A, 0x80
OR | A, 0x01 | ; SLOT#1 or SLOT#1-0
LD | H, 0x40 | ; Page1
CALL | 0x0024 | ; Switch to Page1 of SLOT#1 or SLOT#1-0
LD | DE, 0x8000
LD | HL, 0x4000
LD | BC, 0x2000
LDIR | | ; Copy to Page1 the beginning of 8192byte of
0x8000
LD | A, [0xF342] | ; Get slot with page1 of RAM
LD | H, 0x40 | ; Page1
CALL | 0x0024 | ; switch to page1 of SLOT#1 or SLOT#1-0
EI | | ; interrupt enable

*Some devices have registers mapped onto memory addresses. In such devices, reading the register part may cause some functions to work. For example, some cartridges with an SD card slot have SPI communication functions mapped as registers in memory. Please note that SPI reception will work if read.

CALLF (0030h)

Interslot call.

Input：

Store the value indicating the slot # and the address value immediately after the code calling 0030h.

The value indicating the slot # is the same as the value specified in the A register of CALSLT.

Output：

Depends on caller.

Detailed：

Destruction registers are caller dependent.

The functionality is the same as CALSLT, but IY and IX are not used to specify the slot and address. Also, 0030h can be CALL 0030h, but you can use RST 30h, which is more efficient. Specifically, call it as follows.

LD | A, 1 | ; SCREEN1
RST | 0x30
DB | 0x80 | ; MAIN-ROM SLOT#??
DW | 0x005F | ; CHGMOD
L1:

The return address from the call at 0x0030 is location L1.

In the case of MSX, it is necessary to consider the possibility that the slot # will change, so in general, I think it is better to rewrite the slot # of DB 0x80 with a program that runs on RAM.

LD | A, [0xFCC1] | ; MAIN-ROM SLOT#
LD | [CALL_SLOT_NUM], A
LD | A, 1 | ; SCREEN1
RST | 0x30
CALL_SLOT_NUM:
DB | 0x80
DW | 0x005F | ; CHGMOD
L1:

### 2.4. Relationship between basic slots and expansion slots

There are four basic slots, SLOT#0, SLOT#1, SLOT#2, and SLOT#3, and expansion slots can be added independently to each of them. If an expansion slot is connected to SLOT#0, SLOT#0 increases to four: SLOT#0-0, SLOT#0-1, SLOT#0-2, SLOT#0-3. In this way, since each basic slot has an expansion slot, EXPTBL indicates whether SLOT#0 is expanded, FCC1h indicates whether SLOT#1 is expanded, FCC2h indicates whether SLOT#2 is expanded, and so on. There are four FCC3h and FCC4h that indicate whether or not there is an extension for SLOT#3. Some models have no expansion for all basic slots, and some have expansion for all built-in slots other than the cartridge slot. Of course, there are also intermediate models. Therefore, when switching slots, it is safe to check EXPTBL and switch using the BIOS.

As an example, the slot configuration of FS-A1GT is shown in Figure 2-8.

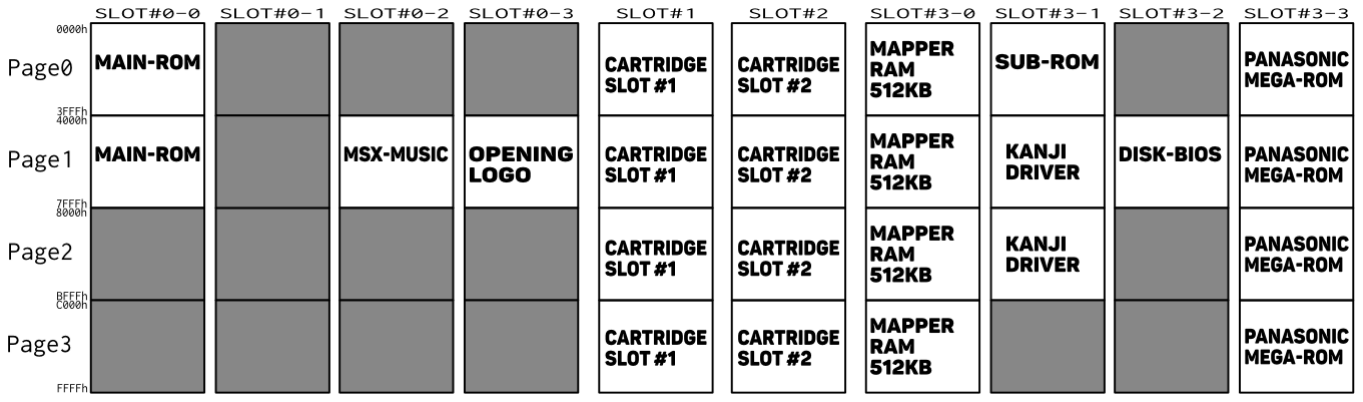
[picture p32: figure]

Figure 2-8. FS-A1GT slot configuration

SLOT#0, SLOT#3 are extended. SLOT#1 and SLOT#2 are exposed as cartridge slots. Therefore, the following three slot selection registers exist in the main unit.

Basic slot selection register I/O A8h

SLOT#0 expansion slot selection register SLOT#0 - FFFFh

SLOT#3 Expansion slot selection register SLOT#3 - FFFFh

The configuration of SLOT#0 is set by the SLOT#0 expansion slot selection register to set "which SLOT#0 expansion slot appears".

The configuration of SLOT#3 sets "which SLOT#3 expansion slot appears" by the SLOT#3 expansion slot selection register,

Furthermore, what appears in the Z80 memory space is determined by the basic slot selection register.

The memory space of MSX is based on the concept of this slot, but there are cases where the memory device connected to each slot has its own expansion. Note that they work independently of slots. From the next chapter, we will pick up and explain particularly major ones among the mechanism of memory space expansion independent of slots.

As an aside, I will briefly explain the contents of each slot that appears in Figure 2-8. MAIN-ROM is the first program to be executed after the power is turned on, and contains BIOS and MSX-BASIC. MSX-MUSIC is a ROM containing MSX-MUSIC and MSX-MIDI processing such as FM-BIOS and CALL MUSIC of MSX-BASIC. OPENING LOGO is a program that displays the MSX logo at startup. MAPPER RAM is a memory mapper compatible RAM described later. SUB-ROM is BIOS ROM added from MSX2. KANJI DRIVER is a ROM that supports CALL KANJI of MSX-BASIC. DISK-BIOS is ROM containing DISK-BASIC and MSX-DOS/DOS2. PANASONIC MEGA-ROM is equipped with MSX-JE, built-in word processing software, built-in software called A1 cockpit, MSX-View, 12-dot kanji ROM for MSX-View, dictionary SRAM for MSX-JE, RAM, MAIN-ROM, etc. Almost all the memory you have can be seen from here.

## 3. Memory mapper compatible RAM

The RAM installed in the MSX main unit is roughly divided into two types: memory mapper compatible RAM and non-compatible RAM. Almost all MSX1 and some MSX2 internal RAMs are non-compatible RAMs, and some MSX2s and MSX2+ RAMs are memory mapper compatible RAMs.

A memory mapper is a RAM partitioned in units of 16KB, and it refers to a mechanism that allows this to appear in any area of Page 0 to 3 (memory can be mapped). RAM that does not support memory mapper is simply connected to RAM, so for example, RAM connected to Page 0 can appear in Page 0 by slot switching, but cannot appear in Pages 1 to 3.

The memory mapper compatible RAM is separated in units of 16KB and is numbered consecutively starting from 0. For example, a 64KB memory mapper compatible RAM has 4 segments, Segment#0 to 3, and a 256KB memory mapper compatible RAM has 16 segments, Segment#0 to 15. At least 64KB (4 segments) exist.

The memory mapper supported RAM has four registers: Page0 mapper segment selection register, Page1 mapper segment selection register, Page2 mapper segment selection register, and Page3 mapper segment selection register. This is a register that specifies the segment # that appears on each Page. The initial value of this register as hardware (value immediately after power-on) is undefined. If the BIOS is compatible with memory mapper compatible RAM after MSX2, it will be initialized to Page0 mapper segment selection register = 3, Page1 mapper segment selection register = 2, Page2 mapper segment selection register = 1, Page3 mapper segment selection register = 0 at startup. be converted. On the other hand, MSX1 is not initialized. For memory mapper-supported RAMs configured with a combination of general-purpose parts, the initial value of all mapper segment selection registers is often 0. In some cases, the memory mapper compatible RAM built into the recently marketed combo cartridge has the same value as the BIOS that supports the memory mapper compatible RAM as the initial value of the hardware. However, it is dangerous to expect such initial values.

The mapper segment selection register is connected to I/O FCh, FDh, FEh, and FFh. The reason will be described later, but it is write-only and cannot be read. The Page0 mapper segment selection register is FCh, the Page3 mapper segment selection register is FFh, and so on. In other words, one mapper segment selection register is 8bit, so the maximum capacity is 256 segments from 0 to 255. 16KB x 256 = 4096KB = 4MB. An image of 128KB is shown in Figure 3-1.

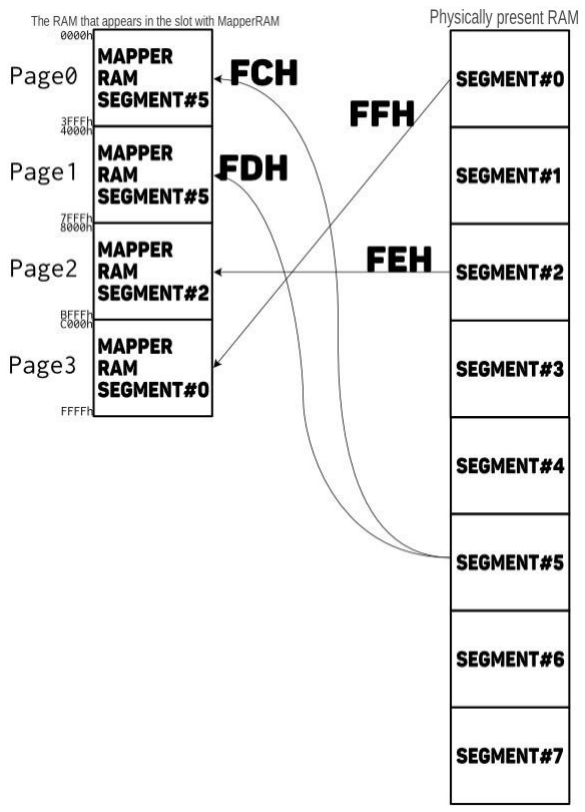
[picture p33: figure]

Figure 3-1. Image of slot appearance RAM of 128KB (8 segments)

The left side in Figure 3-1 corresponds to the slot in which memory mapper compatible RAM is installed. Pages 0 to 3 are all RAM. The right side is the actual installed RAM. Since 128KB = 16KB 8, there are 8 segments of RAM, ✕

which are numbered sequentially from Segment#0 to 7. The left side and the right side are connected by four lines, but this is an image of the mapper segment selection register. Figure 3-1 specifies I/O FCh = 5, FDh = 5, FEh = 2, FFh = 0. In this way, the same segment can appear on different Pages at the same time. Segment#6 can be changed to Page0 at one time, and Segment#6 to Page1 at the next timing. The large-capacity RAM that appears in the 64KB space realized by this is connected to a normal slot, so the memory mapper is connected to the slot that is part of the basic slot and expansion slot.

There is also a cartridge version of memory mapper compatible RAM. You can add RAM by using the cartridge version. Interestingly, the I/O address of the mapper segment selection register is the same for both the built-in memory mapper RAM and the cartridge type memory mapper RAM.

There are cartridge-type memory mapper-compatible RAMs, and there are also built-in memory mapper-compatible RAMs, but they can coexist. If multiple memory mapper-enabled RAMs are present, writing to the memory mapper's mapper segment selection register switches segments in all connected memory mapper-enabled RAMs in the same manner. For example, if SLOT#1 is equipped with a cartridge-type 4MB RAM compatible with memory mapper, and SLOT#3-0 of the main unit is equipped with a 512KB RAM compatible with memory mapper, it will look like Figure 3-2. image.

Figure 3-2. Memory mapper
compatible RAM in two slots, SLOT#1 and SLOT#3-0

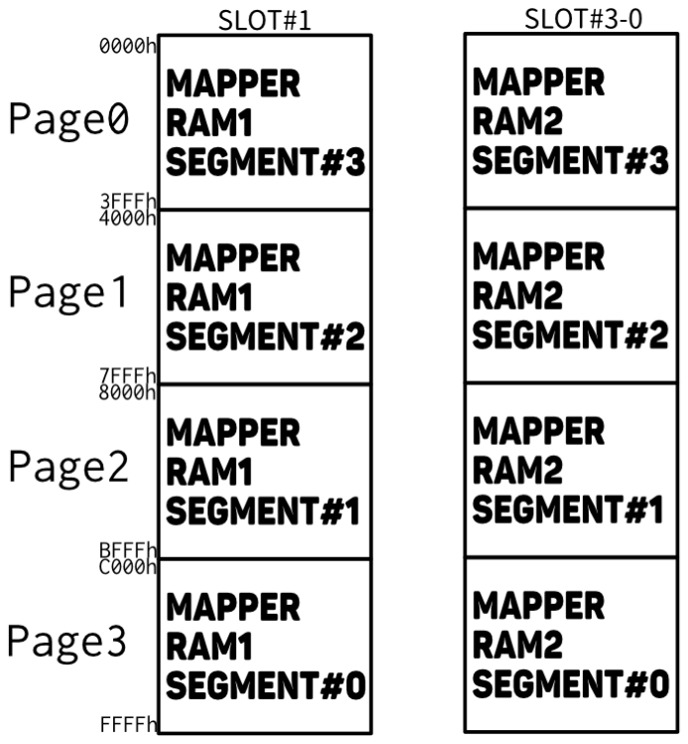
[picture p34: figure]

SLOT#1 contains a 4MB Memory Mapper-enabled RAM cartridge, which we'll call MAPPER RAM1 for purposes of explanation. Similarly, SLOT#3-0 is connected to a 512KB memory mapper compatible RAM inside the main unit,

which is called MAPPER RAM2. Since each is an independent device, for example, SLOT#1 segments cannot appear in SLOT#3-0. 4MB = 256 segments of RAM are available in SLOT#1 and 512KB = 32 segments of RAM are available in SLOT#3-0.

Here, if 15 is written to I/O FCh, the state will be as shown in Figure 3-3

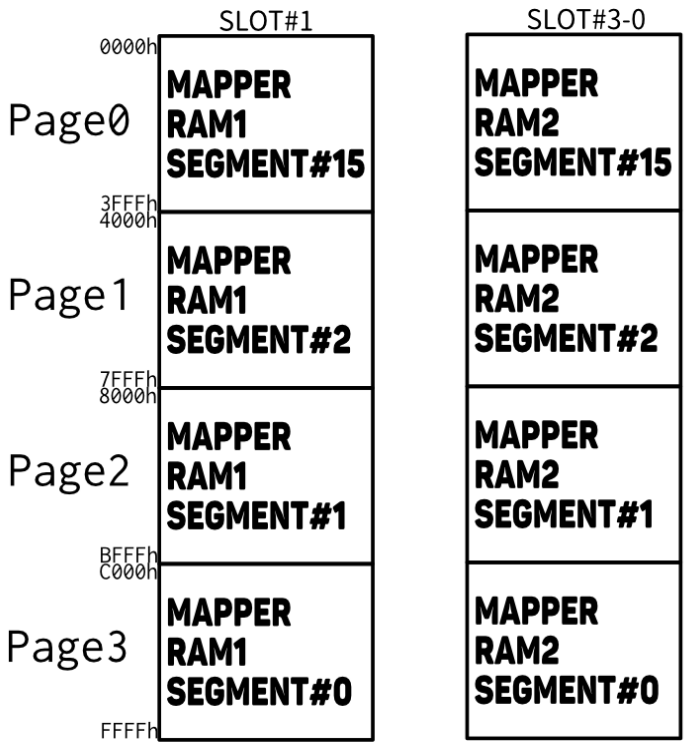
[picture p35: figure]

Figure 3-3. Change Segment of Page0 to 15

Regardless of whether SLOT#1 and SLOT#3-0 appear in the Z80 memory space, both Page0 segments of MAPPER RAM1 and MAPPER RAM2 are switched to Segment#15. So what happens if we write 32 to the I/O FCh? It should look like Figure 3-4.

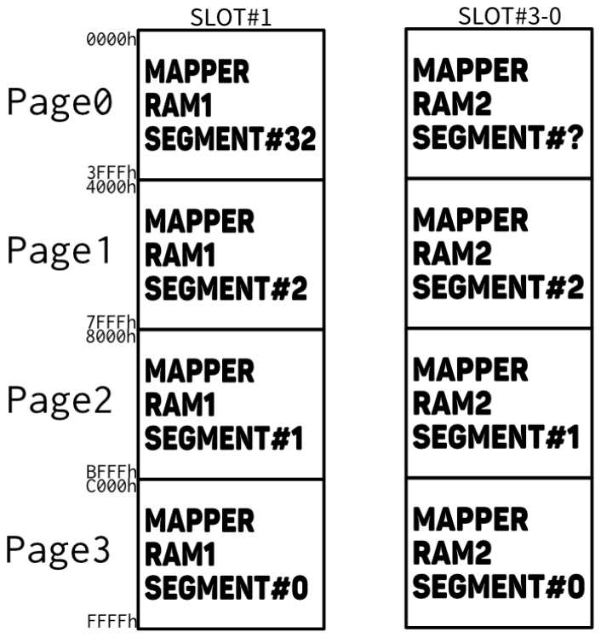
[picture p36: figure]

Figure 3-4. Change Segment # of Page0 to 32

MAPPER RAM1 has 256 segments (0 to 255), but MAPPER RAM2 has only 32 segments (0 to 31). I tried writing the value corresponding to Segment#32 to the mapper segment selection register 0xFC, but MAPPER RAM1 is simply switched to Segment#32. Since MAPPER RAM2 does not have Segment#32, its operation is undefined. In general, the high-order bit of segment # is ignored or ignored, so it often behaves like Segment#32 = Segment#0.

There is a 768KB memory mapper compatible RAM called MEM-768, but the capacity is incomplete. 768KB = 16KB x 48, so there are 48 segments, but if 48 is written to FCh of I/O, how many segments will appear? . Thanks to the cooperation of the person who owns it (*1), I was able to confirm it. The mapper segment selection register is equipped with 6bits, and the upper 2bits are decoded. The MEM-768 has three 256KB RAMs, and one of these three is selected according to the decoding result of the upper 2 bits. Since there are 2 bits, there are 4 combinations, but the value corresponding to 3 seems to be unconnected. Therefore, if you specify Segment #48 to #63, it will be in a state where nothing is connected, it cannot be written, and it seems that FFh is returned when reading. However, just because MEM-768 is designed that way, if you specify a segment # that does not exist, it is safe to interpret that what will appear is undefined.

(*1) Takashi Kobayashi ran the test program and confirmed it.

This address is basically write-only because multiple memory mapper-enabled RAMs are connected to I/O FCh, FDh, FEh, and FFh. Reading is strictly prohibited. Depending on the combination of hardware, the value of the mapper segment selection register may be returned from multiple memory mapper compatible RAMs, causing bus contention and physically destroying the MSX itself. We are unconfirmed whether there is a model that is really broken.

By using memory mapper compatible RAM, it is possible to achieve a large capacity of 4MB per slot, so there is a demand for "multiple applications to use memory separately". To do so, it is necessary to manage a mapper segment selection register that all memory mapper-enabled RAMs switch in tandem. The memory mapper support routine that is installed in the extended BIOS when MSX-DOS2 is installed is provided as a management mechanism. The next section describes how to use the memory mapper support routines.

### 3.1. Memory Mapper Support Routines

In addition to the BIOS installed in the MAIN-ROM and SUB-ROM, MSX has a mechanism called extended BIOS. A device module that is retrofitted in a cartridge or the like exposes the BIOS routines for its control.

Memory mapper support routines are provided using this extended BIOS mechanism. However, the memory mapper compatible RAM is simply RAM, and does not have a "mechanism to set the memory mapper support routine". This is installed in MSX-DOS2 and its successor, Nextor. However, you don't need to check for the presence of MSX-DOS2 or Nextor to check for the presence of memory mapper support routines. Extended BIOS has a common procedure for various routines registered, and the memory mapper support routine follows that rule.

Primary mapper and secondary mapper

Before I explain how to use it, I will explain the types of memory mappers.

If only one slot of memory mapper-enabled RAM exists, it becomes the primary mapper. In that case there is no secondary mapper.

If there are two or more memory mapper-compatible RAM slots, one will be the primary mapper and the rest will be secondary mappers.

In MSX2/2+, the RAM that supports the memory mapper with the largest capacity becomes the primary mapper. In MSXturboR, the memory mapper compatible RAM in SLOT#3-0 built into the main unit becomes the primary mapper. Up to MSX2/2+, there was only a difference in capacity between the built-in cartridge and the expansion cartridge, so it was a specification that the one with the largest capacity was selected as the primary mapper so as to minimize the trouble of switching slots. If multiple memory mapper compatible RAMs with the largest capacity are installed, the memory mapper compatible RAM installed in the slot with the smaller number becomes the primary mapper. In the case of MSXturboR, the built-in RAM can be accessed at high speed for R800, while the expansion cartridge operates at compatible speed with MSX2/2+, so the built-in RAM is largely faster. I'm here. Because of that, I think turboR was changed to use the built-in RAM as the primary mapper.

The memory mapper support routine has a memory mapper supported RAM information table, and there is a routine that returns this table address. By referring to this table, the application can easily know the slot # and number of segments of each memory mapper compatible RAM. At the top of this information table is always the primary mapper information. Secondary mappers are lined up after the second one. The primary mapper is slightly easier to access.

Next, the 64KB RAM space exposed while MSX-DOS2/Nextor is running is called TPA, and this TPA is also allocated to the primary mapper.

Only this primary mapper can be specified as the transfer source/transfer destination buffer when performing file read/write access with the DOS functions of MSX-DOS2/Nextor. I think the big difference between primaries and secondaries is that specifying a region for the secondary mapper doesn't work. Note that if you want to read the contents of a file to a secondary mapper, you will need to load it into the primary mapper first and then block transfer it to the secondary mapper.

As you can see, there is no small difference between the primary mapper and the secondary mapper. Especially in his FS-A1ST, there is less free space because the internal RAM is always primary in turboR and the BIOS occupies some segments in R800-DRAM mode. If there is no problem with the secondary mapper, I think that the environment that can be handled will increase if you actively use the secondary mapper.

Using mapper support routines

According to extended BIOS rules, first check if extended BIOS exists. Next, check to see if the mapper support routines exist. Then, copy the obtained jump table to somewhere on RAM, and then use the entry in the jump table by calling. The first procedure is tedious, but once you have the jump table, the rest is a simple and very fast routine. Below is a detailed explanation of how to use it.

First of all, it is necessary to confirm whether the extended BIOS mechanism itself exists. Specifically, if you read the contents of HOKVLD (FB20h) and bit0 is 0, the extended BIOS itself does not exist. If 1, extended BIOS is present.

Next, check if there is a mapper support routine in the extended BIOS. Set the A register to 0 for judgment, the D register to 4, which indicates the device number of the mapper support routine, and the E register to the function number 1, then call the extended BIOS entry EXTBIO (FFCAh). The A register remains 0 if no mapper support routine exists. If the A register has changed to something other than 0, the mapper support routines are present.

Next, specify 0 in the A register, device number 4 in the D register, function number 2 in the E register, and call EXTBIO. Then, the address of the mapper support routine jump table in the system work area is returned to the HL register. This is a 48-byte area and is a table in which 16 JP xxxx are arranged. If you copy it to a fixed address so that it is easy to use, it will be easier to call.

An example of the mapper support routine confirmation process is shown below.

hokvld := 0xFB20
extbio := 0xFFCA

mmap_init::
ld | a, [hokvld]
and | a, 1
ret | z | ; Error if extended BIOS does not exist
(Zf=1)

; get MapperSupportRoutine's table
xor | a, a
ld | de, 0x0401 ; D=Device ID, E=01h
call | extbio
or | a, a
ret | z | ; The mapper support routines
| | ; Error if not present (Zf=1)
ld | [mmap_table_ptr], hl
; get jump table

xor | a, a
ld | de, 0x0402 ; D=Device ID, E=02h
call | extbio
push | bc
ld | de, mapper_jump_table
ld | bc, 16 * 3
ldir
pop | bc
xor | a, a | ; A=0
inc | a | ; A=1, Zf=0
ret | | ; Successful completion (Zf=0)
mmap_table_ptr::
dw | 0 | ;Address of memory mapper information
table

Calling mmap_init will return A register = 0, Z flag = 1 if the mapper support routine does not exist. If the mapper support routine exists, A register = 1, Z flag = 0 will be returned.

The mapper_jump_table must be placed in RAM and has the following configuration.

mapper_jump_table::
mapper_all_seg:: | ; +00h
db | 0xc9, 0xc9, 0xc9
mapper_fre_seg:: | ; +03h
db | 0xc9, 0xc9, 0xc9
mapper_rd_seg:: | ; +06h
db | 0xc9, 0xc9, 0xc9
mapper_wr_seg:: | ; +09h
db | 0xc9, 0xc9, 0xc9
mapper_cal_seg:: | ; +0Ch
db | 0xc9, 0xc9, 0xc9
mapper_calls:: | ; +0Fh
db | 0xc9, 0xc9, 0xc9
mapper_put_ph:: | ; +12h
db | 0xc9, 0xc9, 0xc9
mapper_get_ph:: | ; +15h
db | 0xc9, 0xc9, 0xc9
mapper_put_p0:: | ; +18h
db | 0xc9, 0xc9, 0xc9
mapper_get_p0:: | ; +1Bh
db | 0xc9, 0xc9, 0xc9
mapper_put_p1:: | ; +1Eh
db | 0xc9, 0xc9, 0xc9
mapper_get_p1:: | ; +21h
db | 0xc9, 0xc9, 0xc9
mapper_put_p2:: | ; +24h
db | 0xc9, 0xc9, 0xc9
mapper_get_p2:: | ; +27h
db | 0xc9, 0xc9, 0xc9
mapper_put_p3:: | ; +2Ah
db | 0xc9, 0xc9, 0xc9
mapper_get_p3:: | ; +2Dh

db | 0xc9, 0xc9, 0xc9

A 48-byte area filled with C9h. C9h is the opcode for RET. If mmap_init is called and A=1 is returned, JP xxxx will be written here. It is a call entry for each function of the mapper support routine.

Each entry in the mapper support routine is named, eg +00h would be named ALL_SEG for him. In the above example, mapper_all_seg is used so that the name is less likely to overlap with others. Just add mapper_ to the beginning and make it lower case. We have labeled 16 entries with this rule. If you want to use ALL_SEG, you can use it by CALL mapper_all_seg.

Now that we are ready to call each entry, we will explain each entry in turn.

ALL_SEG

I think the name stands for allocate segment. It becomes a routine that attempts to allocate one segment.

Input：

A register

0: Secure one segment as a user segment

1: Secure one segment as a system segment

B register

0: Secure from primary mapper

0 Other than: Secure from multiple mappers (see details)

Output：

Cy flag: 0 = successful, 1 = no free segments

A register: allocated mapper memory segment #

B register: allocated mapper memory slot # (0 if called with B=0)

Detail：

The values to be set in the B register are as follows.

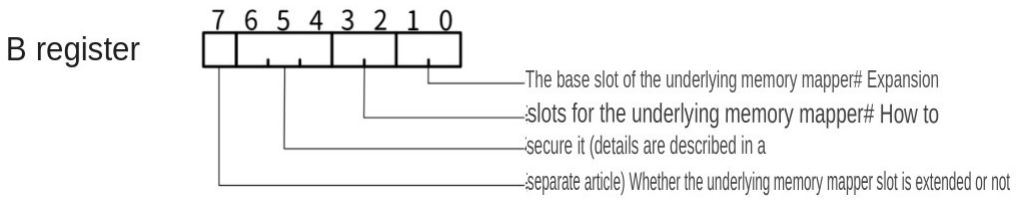
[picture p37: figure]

ENASLT Specify the reference memory mapper slot with the same bitmap as the slot # specification method used in etc. The vacant bits 6, 5 and 4 specify how to reserve for that criterion.

B register: The meanings of the values specified bits 6,5,4are as follows:

000 Allocated from the base memory mapper.

001 Allocate from a memory mapper other than the reference memory mapper.

010 First, try to allocate from the reference memory mapper, and if there is no free space, allocate from other memory mappers.

011 First, attempt to allocate from a memory mapper other than the reference memory mapper, and if there is no free space, allocate from the reference memory mapper.

1?? undefined (do not specify)

The difference between the user segment and the system segment is that the user segment is a segment that is automatically released when the program ends. Normal memory usage uses user segments. System segments are not freed when the program terminates. Use the system segment only in cases such as resident programs that need to be maintained even after termination.

Also, user segments are assigned in ascending order of segment #. System segments are allocated in descending order of segment #. For example, if segments #4, 5, and 6 are free, allocating a user segment will allocate segment #4, and allocating a system segment will allocate segment #6.

The slot # of the secondary memory mapper can be found from the memory mapper information table.

About this Memory mapper information table section.

FRE_SEG

Free the specified segment.

Input：

A register: Segment # to free

B register: memory mapper slot # of the segment to free

Output：

Cy flag： 0 = free successfully, 1 = free unsuccessful

Detail：

The value specified in the B register is not the value of the B register given as input when calling ALL_SEG . Note that you must specify the value of the B register obtained as a result of calling ALL_SEG .

It fails only when specifying a segment that is not secured by anyone. Note that this will free the segment. For example, in MSXturboR, part of the ROM area such as BIOS is copied to the internal RAM, but on the primary memory mapper, that area is reserved as a system segment. Doing so protects the BIOS copy from other applications, but it also frees it.

RD_SEG

Intersegment read. A: Reads and returns the value of the address indicated by HL。

Input：

A register： Segment # to be read

HL register: In-segment address (higher 2 bits are invalid)

Output：

A register: read data

Other registers are preserved.

Detail：

Returns with interrupts disabled.

Since the Page2 segment is switched internally, the stack memory must be placed outside of Page2.

You must have previously switched to the slot of the memory mapper targeting Page2. This routine reads and returns the value at address HL in segment A of the memory mapper appearing on Page2. Therefore, it is necessary to switch to the slot of the memory mapper from which you want to read Page2.

This function is effective when you want to read from a random address that also includes a segment, but if you want to read continuously from the same segment, it is faster to use direct paging (PUT_P2), which will be described later.

Since processing speed is emphasized, error checks such as whether the specified segment has been secured are not performed. Therefore, there is no return value to indicate an error. The segment specified by the A register is assumed to be under its own control.

WR_SEG

It's an intersegment light. A: Write E to the address indicated by HL.

Input：

A register： Segment # to be read

HL register： In-segment address (upper 2 bits are invalid)

E register： Value to write

Output：

A register： Destroyed.

Other registers are preserved.

Detail：

Returns with interrupts disabled.

Since the Page2 segment is switched internally, the stack memory must be placed outside of Page2.

It is necessary to switch to the slot of the memory mapper that targets Page2 in advance. This routine writes the value of the E register to address HL in segment A of the memory mapper appearing on Page2. Therefore, you need to switch to the memory mapper slot where you want to write Page2.

This function is effective when you want to write from a random address that also includes a segment, but if you want to write continuously from the same segment, it is faster to use direct paging (PUT_P2), which will be described later.

Since processing speed is emphasized, error checks such as whether the specified segment has been secured are not performed. Therefore, there is no return value to indicate an error. The segment specified by the A register is assumed to be under its own control.

CAL_SEG

It's an intersegment call. A routine that calls a subroutine in a specified segment with an interface similar to the inter-slot call CALSLT in the BIOS.

Input：

IY register: segment number specified in upper 8 bits (lower 8 bits are ignored)

IX register: Address of subroutine to call

AF, BC, DE, HL registers: parameters passed to subroutines to call

Output：

AF, BC, DE, HL, IY registers: return values from the called subroutine

Other registers: Destroyed.

Detail：

This routine switches the page corresponding to the address of the subroutine to call to the specified segment and calls the address of the subroutine to call. It then returns the Page corresponding to the address of the subroutine to call to the original segment.

This routine does not switch slots. Segment switching only. It is assumed that the Page corresponding to the upper 2 bits of the IX register has already been switched to the slot of the memory mapper that has the target subroutine.

Since slot switching is a process that requires a relatively heavy load, it seems that slot switching is not included in this routine, assuming that the calling side will minimize it. Memory mapper segment switching is much faster than slot switching, so that process is included.

Of course, Page0 has entries for interrupt routines, and Page3 has BIOS work and so on. There is also stack memory somewhere. Pay close attention to these and perform slot switching in advance before using.

Since the inter-segment call itself exists on Page3, Page3's inter-segment call cannot be used. If Page3 is specified (the high-order 2bits of IX are 11), segment switching will not be performed and it will simply be called.

The back registers (AF', BC', DE', HL') are used in the inter-segment call routine. Please note that they cannot be used for subroutine calls that use these as inputs.

CALLS

It's an intersegment call. A routine that calls a subroutine in a specified segment with an interface similar to the inter-slot call CALLF in the BIOS.

Input：

It is a mechanism that embeds parameters in the code as shown below without using registers.

CALL | CALLS
DB | segment #
DW | subroutine address

AF, BC, DE, HL specifies the input parameters to the routine to be called.

Output：

AF, BC, DE, HL, IX, IYRegisters: Return values from called subroutines

Other registers: Destroyed.

Detail：

This routine does not switch slots. Segment switching only. It is assumed that the Page corresponding to the subroutine address has already been switched to the memory mapper slot containing the desired subroutine.

Since slot switching is a process that requires a relatively heavy load, it seems that slot switching is not included in this routine, assuming that the calling side will minimize it. Memory mapper segment switching is much faster than slot switching, so that process is included.

Of course, Page0 has entries for interrupt routines, and Page3 has BIOS work and so on. There is also stack memory somewhere. Pay close attention to these and perform slot switching in advance before using.

Since the inter-segment call itself exists on Page3, Page3's inter-segment call cannot be used. Even if you specify the address of Page3 as the subroutine address, the segment will not be switched and it will simply be called.

The back registers (AF', BC', DE', HL') are used in the inter-segment call routine. Please note that they cannot be used for subroutine calls that use these as inputs.

PUT_PH

Direct paging. Changes the mapper segment of the specified Page to the specified segment.

Input：

H register： Specify the target page number with the upper 2 bits.

A register： Specify the desired segment #.

Output：

None.

All registers are preserved.

Detailed：

Writes to the mapper segment selection register corresponding to the specified page. The specified page of all memory mappers is switched to the specified segment.

This routine only writes to the mapper segment selection register and stores the written value in the work area, and returns immediately. Compared to slot switching routines, it is considerably faster, so it can be used for frequent switching.

It is assumed that the caller of this routine will set the correspondence between the allocated segment number and the corresponding memory mapper slot number without contradiction. Please note that there is no mechanism to check if there is a contradiction because speed is prioritized.

The specified segment # will be the segment # obtained by securing with ALL_SEG. ALL_SEG also returns the corresponding slot #, but note that slot switching is the responsibility of the caller of this routine. The input does not have a value to select which slot among the possible multiple memory mappers, because it switches to all memory mappers indiscriminately. This area is quite peculiar, but as explained earlier, since the I/O addresses are the same, I think you can understand that it is not possible to switch segments for multiple memory mappers individually.

Note that the Page3 segment cannot be switched. If 0b11xxxxxx (where x is optional) is specified in the H register, return without doing anything.

GET_PH

Direct paging. Get the mapper segment # of the specified Page.

Input：

H register： Specify the target page number with the upper 2 bits.

Output：

A register： Retrieved segment #.

All registers are preserved.

Detailed：

It is assumed that the specified page has been switched to the desired memory mapper slot.

This routine reads and returns the "segment # specified last for the specified page" stored in the work area. We will be back instantly. Compared to slot switching routines, it is considerably faster, so it can be used for frequent switching.

It is assumed that the caller of this routine will set the correspondence between the allocated segment number and the corresponding memory mapper slot number without contradiction. Please note that there is no mechanism to check if there is a contradiction because speed is prioritized.

PUT_P0

Direct paging. Change Page0's mapper segment to the specified segment.

Input：

A register： Specify the desired segment #.

Output：

None.

All registers are preserved.

Detailed：

Please think that the target page of PUT_PH is fixed to Page0. If you use it normally, the target page is often statically determined during coding. Please think that is prepared. There is also the advantage that you do not need to destroy the H register just to specify the Page.

GET_P0

Direct paging. Get mapper segment # of Page0.

Input:

None

Output:

A register: Retrieved segment #.

All registers are preserved.

Detailed：

Please assume that the target Page of GET_PH is fixed to Page0. If you use it normally, the target page is often statically determined during coding. Please think that is prepared. There is also the advantage that you do not need to destroy the H register just to specify the Page.

PUT_P1

Direct paging. Change Page1's mapper segment to the specified segment.

Input:

A register: Specify the desired segment #.

Output:

None.

All registers are preserved.

Detailed：

Please think that the target page of PUT_PH is fixed to Page1. If you use it normally, the target page is often statically determined during coding. Please think that is prepared. There is also the advantage that you do not need to destroy the H register just to specify the Page.

GET_P1

Direct paging. Get mapper segment # of Page1.

Input:

None

Output:

A register: Retrieved segment #.

All registers are preserved.

Detailed：

Please assume that the Page targeted by GET_PH is fixed to Page1. If you use it normally, the target page is often statically determined during coding. Please think that is prepared. There is also the advantage that you do not need to destroy the H register just to specify the Page.

PUT_P2

Direct paging. Change Page2's mapper segment to the specified segment.

Input:

A register: Specify the desired segment #.

Output:

None.

All registers are preserved.

Detailed：

Please think that the target page of PUT_PH is fixed to Page2. If you use it normally, the target page is often statically determined during coding. Please think that is prepared. There is also the advantage that you do not need to destroy the H register just to specify the Page.

GET_P2

Direct paging. Get mapper segment # of Page2.

Input:

None

Output:

A register: Retrieved segment #.

All registers are preserved.

Detailed：

Please assume that the Page targeted by GET_PH is fixed to Page2. If you use it normally, the target page is often statically determined during coding. Please think that is prepared. There is also the advantage that you do not need to destroy the H register just to specify the Page.

PUT_P3

Do nothing.

Input:

A register: Specify the desired segment #.

Output:

None.

All registers are preserved.

Detailed：

Please think that the target page of PUT_PH is fixed to Page3. If you use it normally, the target page is often determined statically during coding. Please think that is prepared. There is also the advantage that you do not need to destroy the H register just to specify the Page.

As a matter of fact, Page3 is where the mapper support routine exists, so it cannot be switched. Therefore, it should be noted that this routine returns without doing anything.

GET_P3

Direct paging. Get mapper segment # of Page3.

Input:

None

Output:

A register: Retrieved segment #.

All registers are preserved.

Detailed：

Please assume that the Page targeted by GET_PH is fixed to Page3. If you use it normally, the target page is often determined statically during coding. Please think that is prepared. There is also the advantage that you do not need to destroy the H register just to specify the Page.

Page3 cannot change Segment# with PUT_P3 or PUT_PH due to BIOS work. So GET_P3 always returns 0 in his A register, indicating Segment#0.

Memory mapper information table

When the above initialization sample program (Using mapper support routines) is executed, the address of the memory mapper information table is stored in mmap_table_ptr upon successful initialization.

Information about the memory mapper-compatible RAM currently installed in the MSX system is stored here, and it has an array structure with one entry for each memory mapper-compatible RAM. One entry has the following structure.

Offset
address

Meaning

+0 | Memory mapper enabled RAM slots#

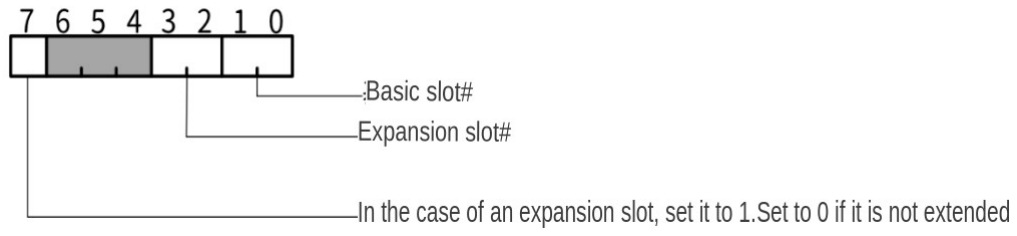
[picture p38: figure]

+1 | Total number of segments (4-255). (8-255 for primary mapper)
+2 | Total number of unused segments
+3 | Total number of segments allocated as system segments (minimum 6 for primary mapper)
+4 | Total number of segments assigned as user segments
+5～+7 | Reserved area

The memory mapper-enabled RAM slot # contains a slot # that can be used for slot control routines in the BIOS, such as ENASLT. In the memory mapper support routine ALL_SEG, the primary mapper can be used with B=0 without specifying the slot #, but in order to actually use the allocated segment, it is necessary to switch to that slot with ENASLT etc. For the slot # that is required at that time, use the value of this "RAM slot # for memory mapper".

The total number of segments value will be at least 8 for the primary mapper. 8 segments x 16 KB = 128 KB, which matches the requirement specification of MSX-DOS2 "minimum 128 KB required".

The total number of segments allocated as system segments will be at least 6 for the primary mapper. This is because MSX-DOS2 itself reserves his 4 segments for his TPA and 2 segments for his DOS2 work area. In the case of MSXturboR, the BIOS copy area for DRAM mode is also this system segment, so the total number of segments already allocated as system segments is 10.

This 8-byte structure is lined up as many times as the number of memory mapper compatible RAMs, and then 0 is stored as a terminator. MSX becomes a MAIN-ROM slot if SLOT#0 is not expanded. Therefore, SLOT#0 does not exist in any model of memory mapper compatible RAM. Taking advantage of this, the memory mapper support routines often treat the value “0” specially where slot

# is specified. The first byte of the memory mapper information table indicates the slot # of the memory mapper compatible RAM, but if 0 is entered here, it indicates the end of the memory mapper information table, which may be arranged continuously. It is treated as a terminator.

The mapper segment selection register has 256 ways from 0 to 255, 16KB x 256 segments = 4096KB, but the maximum total number of segments is 255. Only up to 4080KB can be used because it only supports up to segments.

As an example, the values in the memory mapper information table when a 4MB memory mapper compatible RAM cartridge is installed in SLOT#2 of the FS-A1GT are shown below.

Memory mapper | Offset address | meaning | value
primary | +0 | Memory mapper enabled RAM slots # | 83h (SLOT#3-0)
| +1 | Total number of segments | 32 segment
| +2 | Total number of unused segments | 22 segment
| +3 | Total number of segments allocated as system segments | 10 segment
| +4 | Total number of segments assigned as user segments | 0 segment
| +5～+7 | Reserved area | all 0
Secondary １ | +8 | Memory mapper enabled RAM slots# | 02h (SLOT#2)
| +9 | Total number of segments | 255 segment
| +10 | Total number of unused segments | 255 segment
| +11 | Total number of segments allocated as system segments | 0 segment
| +12 | Total number of segments assigned as user segments | 0 segment
| +13～+15 | Reserved area | all 0
Terminator | +16 | Memory mapper enabled RAM slots# | 0

Figure 3-5 shows a screen that was actually checked using the tool.

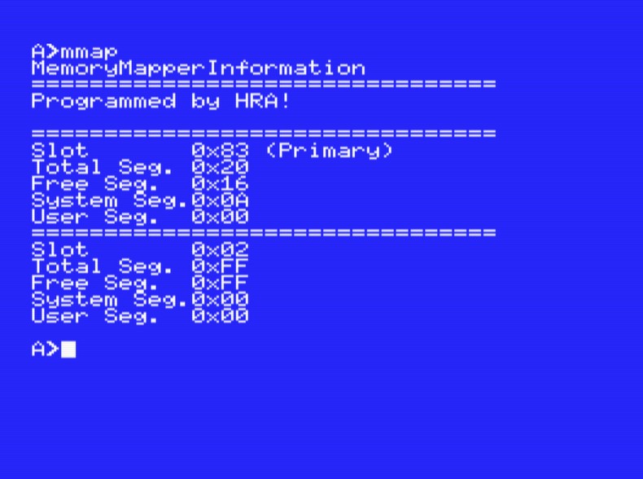
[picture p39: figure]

Figure 3-5. Memory mapper information table dump tool display

Below is the source code of the memory mapper information table dump tool used in Figure 3-5.

Because another source that includes is not an essential part of the

explanation in this section, (Appendix 1. Various sources used by the sample program) I'll post it on.

mmap.asm

; ============================================================================= ; Memory Mapper Program to dump information
; =============================================================================
include | "msxbios.asm"
include | "msxdos1.asm"
include | "msxdos2.asm"
org | 0x100

entry::
; Initialize
ld | sp, [TPA_BOTTOM]
call | mmap_init

; startup message
ld | de, msg_entry
call | puts

; mapper check
ld | ix, [mmap_table_ptr]
xor | a, a
mapper_check_loop::
call | dump_one
jr | c, exit_loop
ld | de, 8
add | ix, de
jr | mapper_check_loop
exit_loop::
ld | b, 0
ld | c, D2F_TERM
jp | bdos

; =============================================================================

; | Dump a mapper information
; | input)
; | ix .... target mapper table
; | a ..... 0: primary mapper, others: not primary mapper
; | break)
; | a ..... a + 1
; =============================================================================
scope | dump_one
dump_one::
; end check
ld | b, [ix + 0]
inc | b
dec | b
scf
ret | z
push | af
ld | de, msg_separator
call | puts
ld | a, [ix + 0] | ; slot number
call | dec2hex
pop | af
push | af
ld | de, msg_primary_mapper_mark
or | a, a
call | z, puts
ld | de, msg_crlf
call | puts
ld | de, msg_total
call | puts
ld | a, [ix + 1] | ; total segments
call | dec2hex
ld | de, msg_crlf
call | puts
ld | de, msg_free
call | puts
ld | a, [ix + 2] | ; free segments
call | dec2hex
ld | de, msg_crlf
call | puts
ld | de, msg_system
call | puts
ld | a, [ix + 3] | ; system segments
call | dec2hex
ld | de, msg_crlf
call | puts
ld | de, msg_user
call | puts
ld | a, [ix + 4] | ; user segments
call | dec2hex
ld | de, msg_crlf
call | puts
pop | af
or | a, a | ; Cy = 0
inc | a
ret
endscope

; =============================================================================
; | Dump A register value by hex
; | input)
; | a ..... target number
; =============================================================================
scope | dec2hex
dec2hex::

ld | b, a
rrca
rrca
rrca
rrca
and | a, 0x0F
add | a, '0'
cp | a, '9' + 1
jr | c, skip1
add | a, 'A' - '0' - 10
skip1:
ld | [hex2byte], a
ld | a, b
and | a, 0x0F
add | a, '0'
cp | a, '9' + 1
jr | c, skip2
add | a, 'A' - '0' - 10
skip2:
ld | [hex2byte + 1], a
ld | de, hex2byte
call | puts
ret
hex2byte::
ds | "00"
db | 0
endscope

; =============================================================================
; | Data area
; ============================================================================= msg_total::
ds | "Total Seg. 0x"
db | 0
msg_free::
ds | "Free Seg. | 0x"
db | 0
msg_system::
ds | "System Seg.0x"
db | 0
msg_user::
ds | "User Seg. | 0x"
db | 0
msg_not_enough_memory::
ds | "Not enough memory!!"
msg_crlf::
db | 0x0D, 0x0A, 0
msg_separator::
ds | "================================"
db | 0x0D, 0x0A
msg_slot::
ds | "SLOT | 0x"
db | 0
msg_primary_mapper_mark::
ds | " (Primary)"
db | 0
msg_entry::
ds | "MemoryMapperInformation"
db | 0x0D, 0x0A
ds | "================================"
db | 0x0D, 0x0A
ds | "Programmed by HRA!"
db | 0x0D, 0x0A
db | 0x0D, 0x0A, 0
include | "stdio.asm"
include | "memmapper.asm"

### 4. Mega ROM

A mega-ROM is a ROM that exceeds 1 Mbit. Since the memory space of Z80 is only 64KB=0.5Mbit, a bank switching mechanism is provided to handle 1Mbit or more.

The part or part group that implements the bank switching mechanism is called a mega ROM controller, or megacon for short. The MSX standard does not specify this content, and there are various types.

ASCII has released several megacon that can be used with MSX, and many software uses this. There are two types of ASCII megacon when roughly classified from the software point of view. There are two types, ASCII-8K type and ASCII-16K type. The types of megacon ICs are LZ93A13 (32pin), M60002-0125SP (42pin), BS6101 (42pin), NEOS MR6401 (28pin), BS6202 (42pin), IREM TAM-S1 (28pin), etc.[*] However, since this document focuses on software control, we will explain two types: ASCII-8K type and ASCII-16K type. No mention of IC differences.

In addition, Konami has its own megacon. This manual describes the three types of SCC-less version, SCC, and SCC-I.

The MSX game cartridge has already become a valuable commodity, so if you were to make your own mega ROM cartridge, it would be more realistic to create a new mega computer using programmable logic devices such as CPLDs and FPGAs. It is possible to create a megacon with your own specifications, and I think it would be good to design such a megacon for copy protection. However, at the stage of developing software such as games to be written to the cartridge, by developing compatible with ASCII or his Konami mega-computer used in conventional commercial products, there is an advantage that you can easily check the operation on the MSX emulator. there is. I think it would be advantageous in terms of development efficiency to make modifications according to the original specification megacon as needed after the software is assembled. Of course, I think that it is possible to make a cartridge with a megacon that is compatible with the conventional megacon.

For that reason, I think it is meaningful to know how to control the megacon, so I would like to explain each type of megacon in this chapter.

Panasonic's MSX2+ and later bodies have their own megacon. I don't think there is anyone who dares to make this compatible, but I would like to explain this megacon as it may be a reference when investigating the behavior of FS-A1GT. There are FS-A1FX/WX/WSX/ST/GT, but there seems to be subtle differences with revisions in this megacon. This document mainly describes the FS-A1GT megacon.

[*] information source: https://gigamix.hatenablog.com/entry/rom/

### 4.1. ASCII-8K type

The ASCII-8K type divides the ROM into 8KB units and assigns consecutive numbers. This is a method to access by making this appear in BANK0 (4000h-5FFFh), BANK1 (6000h-7FFFh), BANK2 (8000h-9FFFh), BANK3 (A000h-BFFFh). The Nth consecutive number assigned is written as BANK#N here.

Page 1 and Page 2 form 4 BANKs, with 2 BANKs inside the Page explained in the slot section. These four are called BANK0 to BANK3 in order from the smallest value address. By making several BANKs (this is the actual ROM) in the mega ROM appear in this BANK0 to BANK3 (this is the address range) while switching, it is possible to access the entire ROM. .

For example, 1Mbit ASCII-8K type mega-ROM is 1[Mbit] = 128[KB] = 8[KB] ✕ 16[BANK], so there are 16 BANKs, so the configuration is as shown in Figure 4.1-1. will be:

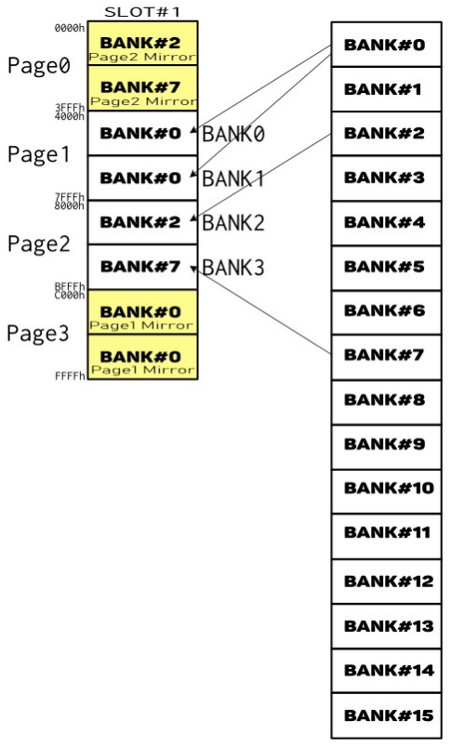
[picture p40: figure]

Figure 4.1-1. Image of ASCII-8K type 1Mbit mega ROM

Figure 4.1-1 is an image of 1Mbit mega ROM installed in SLOT#1. His Page0 in SLOT #1 has a mirror of Page2, and Page3 has a mirror of Page1.

BANK0 and BANK1 exist in Page1, and BANK2 and BANK3 exist in Page2.

BANK#0 to #15, which are 16 lined up on the right side of the figure, will be the ROM. 8KB x 16 = 128KB because there are 16 8KB each.

The four arrows connecting the left side and right side of the figure are the bank selection registers. There is a bank selection register for each of BANK0 to

BANK3, and any BANK# from BANK#0 to #15 can be specified. Therefore, the same BANK# can appear in multiple BANKs at the same time. In the figure, BANK#0 appears in BANK0 and BANK1.

The bank selection register is Memory mapped I/O. Table 4.1-1 summarizes the bank selection register addresses.

Table 4.1-1.ASCII-8K Bank Select Register Address

BANK number | Corresponding bank select register address
BANK0 (4000h-5FFFh) | 6000h-67FFh (initial value BANK#0)
BANK1 (6000h-7FFFh) | 6800h-6FFFh (initial value BANK#0)
BANK2 (8000h-9FFFh) | 7000h-77FFh (initial value BANK#0)
BANK3 (A000h-BFFFh) | 7800h-7FFFh (initial value BANK#0)

The address of the bank selection register indicates a range of 2048 bytes, but the actual size is only 1 byte. So 8KB 256 = 2048KB = 2MB is the ✕ maximum capacity. The reason why it has a range is that only part of the address signal is used for determination in order to simplify the megacon circuit. We'll explain why it's simple in the hardware chapter.

As you can see, all bank selection registers exist on Page1. Since the bank selection registers of BANK2 and BANK3 in Page2 also exist in Page1, for example, when the RAM slot of the main body appears on Page1 and the slot of this mega ROM appears on Page2, when switching BANK2 and BANK3, Please note that it is necessary to temporarily switch Page1 to the MegaROM slot, rewrite the bank selection registers of BANK2 and BANK3, and then return Page1 to the RAM slot of the main unit.

The bank selection register is write-only. When read, the contents of the ROM corresponding to that address are read.

The reason why the bank selection registers are gathered in Page1 may be consideration for the backup SRAM. There is also a mega computer that supports SRAM for backup. This is a structure in which /WE via the mega-con is set to L only when some banks are accessed. If there is a bank selection register when accessing SRAM, it will be a hindrance, so it may be assumed that SRAM appears on Page2 and accessed.

### 4.2. ASCII-16K type

The ASCII-16K type divides the ROM into 16KB units and assigns consecutive numbers. This is a method to access by making this appear in BANK0 (4000h-7FFFh) and BANK1 (8000h-BFFFh). The Nth consecutive number assigned is written as BANK#N here.

The size of the mega-ROM BANK is the same 16KB as explained in the page on the slot. Page1 and Page2 constitute two banks. These two are called BANK0 to BANK1 in order from the smallest value address. In other words, the corresponding relationships are BANK0=Page1 and BANK1=Page2. By making several BANKs (this is the actual ROM) that are installed in the mega ROM appear in this BANK0 to BANK1 (this is the address range) while switching, it is possible to access the entire ROM.

For example, 1Mbit ASCII-16K type mega-ROM is 1[Mbit] = 128[KB] = 16[KB] ✕ 8[BANK], so there are 8 BANKs, so the configuration is as shown in Figure 4.2-1 will be:

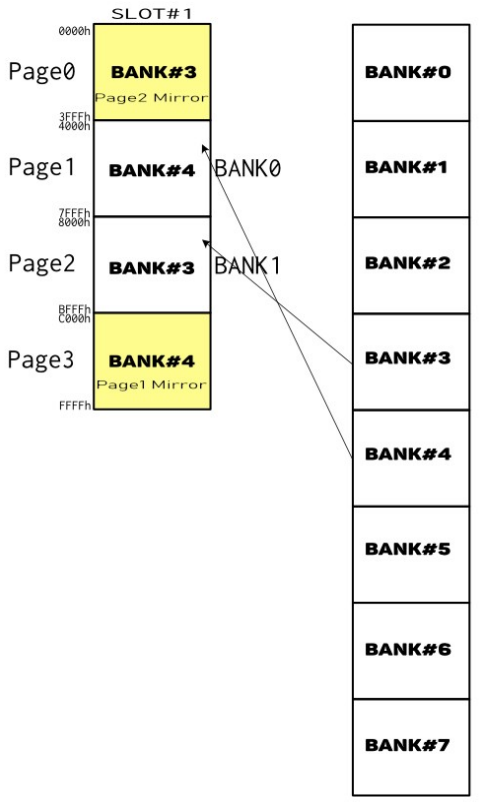
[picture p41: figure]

Figure 4.2-1.Image of ASCII-16K type 1Mbit mega ROM

Figure 4.2-1 is an image of 1Mbit mega ROM installed in SLOT#1. His Page0 in SLOT #1 has a mirror of Page2, and Page3 has a mirror of Page1.

BANK0 exists in Page1 and BANK1 exists in Page2.

BANK#0 to #7, which are 8 lined up on the right side of the figure, will be the ROM. 16KB x 8 = 128KB because there are 8 of them at 16KB each.

The two arrows connecting the left side of the figure and the right side of the figure are the bank selection registers. There is a bank selection register for each of BANK0 to BANK1, and any BANK# from BANK#0 to #7 can be specified. Therefore, the same BANK# can appear in multiple BANKs at the same time.

The bank selection register is Memory mapped I/O. Table 4.2-1 summarizes the bank selection register addresses.

Table 4.2-1.ASCII-16K Bank Select Register Address

BANK number | Corresponding bank select register address
BANK0 (4000h-7FFFh) | 6000h-67FFh (initial value BANK#0)
BANK1 (8000h-BFFFh) | 7000h-77FFh (initial value BANK#0)

The address of the bank selection register indicates a range of 2048 bytes, but the actual size is only 1 byte. So 16KB 256 = 4096KB = 4MB is the ✕ maximum capacity. I think the reason for having a range is to simplify the megacon circuit. We'll explain why it's simple in the hardware chapter.

As you can see, all bank selection registers exist on Page1. Since the bank selection register of BANK1 in Page2 also exists in Page1, for example, when Page1 shows the main RAM slot and Page2 shows this mega ROM slot, when switching BANK1, temporarily please note that it is necessary to switch Page1 to the mega ROM slot, rewrite the bank selection register of BANK1, and then return Page1 to the RAM slot of the main unit.

The bank selection register is write-only. When read, the contents of the ROM corresponding to that address are read.

The reason why the bank selection registers are gathered in Page1 may be consideration for the backup SRAM. There is also a mega computer that supports SRAM for backup. This is a structure in which /WE via the mega-con is set to L only when some banks are accessed. If there is a bank selection register when accessing SRAM, it will be a hindrance, so it may be assumed that SRAM appears on Page2 and accessed.

### 4.3. Konami-8K type

This is the Mega ROM type used in Konami games before the SCC was installed.

The Konami-8K type divides the ROM into 8KB units and assigns consecutive numbers. This is a method to access by making this appear in BANK0 (4000h-5FFFh), BANK1 (6000h-7FFFh), BANK2 (8000h-9FFFh), BANK3 (A000h-BFFFh). The Nth consecutive number assigned is written as BANK#N here.

The BANK switching method is the same as ASCII-8K. However, the address of the bank selection register is different. The Konami-8K type bank selection register addresses are summarized in Table 4.3-1.

Table 4.3-1.Konami-8K Bank Select Register Address

BANK number | Corresponding bank select register address
BANK0 (4000h-5FFFh) | None (BANK#0 fixed)
BANK1 (6000h-7FFFh) | 6000h-7FFFh (initial value BANK#1)
BANK2 (8000h-9FFFh) | 8000h-9FFFh (initial value undefined)
BANK3 (A000h-BFFFh) | A000h-BFFFh (initial value undefined)

Unlike ASCII-8K , BANK0 is fixed at BANK#0 . A different BANK# cannot be specified.

BANKN's bank select register resides within that BANKN address range. If the slot of the BANKN you want to switch to appears in the Z80 memory space, you can specify the BANK#N that appears in that BANKN. For ROM only, I think it's easier to use than ASCII-8K.

The maximum capacity that can be handled is 512KB. In other words, up to 64 [BANK]. N of BANK#N takes the range of 0-63.

BANK0 to BANK3 exist on Page1 and Page2, but Page0 has a mirror of Page2 (BANK2 and BANK3) and Page3 has a mirror of Page1 (BANK0 and BANK1), just like ASCII-8K.

### 4.4. Konami SCC type

Any Konami ROM game that says it supports SCC falls into this category. There are also controllers compatible with this type of MegaROM controller, such as MegaFlashROM SCC, and because SCC sound sources can be used, some people create and release their own games with this type.

The BANK switching method is the same as ASCII-8K. However, the address of the bank selection register is different. Table 4.4-1 summarizes the bank selection register addresses of the Konami-SCC type.

Table 4.4-1.Konami-SCC Bank Select Register Address

BANK number | Corresponding bank select register address
BANK0 (4000h-5FFFh) | 5000h-57FFh (initial value BANK#0)
BANK1 (6000h-7FFFh) | 7000h-77FFh (initial value BANK#1)
BANK2 (8000h-9FFFh) | 9000h-97FFh (initial value BANK#2)

BANK3 (A000h-BFFFh) | B000h-B7FFh (initial value BANK#3)

Unlike ASCII-8K, BANKN's bank selection register resides within its BANKN address range. If the slot of the BANKN you want to switch to appears in the Z80 memory space, you can change the BANK#N that appears in that BANKN. For ROM only, I think it's easier to use than ASCII-8K.

The maximum capacity that can be handled is 512KB, that is, up to 64 [BANK]. N of BANK#N takes the range of 0-63.

BANK0 to BANK3 exist on Page1 and Page2, but Page0 has a mirror of Page2 (BANK2 and BANK3) and Page3 has a mirror of Page1 (BANK0 and BANK1), just like ASCII-8K.

The Konami-SCC type megacon is equipped with an SCC sound source. There is a register for controlling the SCC sound source. The bank selection register only takes a range of 0 to 63, but if you write 63 (3Fh) to the bank selection register of BANK2, the SCC sound source register space will appear in BANK2 as shown in Table 4.4-2. In other words, BANK#63 cannot appear in BANK2. If you want to access BANK#63, please use BANK0/1/3.

Table 4.4-2. Register of SCC sound source (BANK2-BANK#63)

Address | Size (byte) | Meaning
8000h-8FFFh | 4096 | Unused??
9000h-97FFh | 2048 | Bank selection register for BANK2. The entity is 1 byte. Write only.
9800h-981Fh | 32 | wave memory ー 0 (for Ch.A), read/write
9820h-983Fh | 32 | wave memory ー 1 (for Ch.B), read/write
9840h-985Fh | 32 | wave memory ー 2 (for Ch.C), read/write
9860h-987Fh | 32 | wave memory ー 3 (for Ch.D/E ), read/write
9880h-9881h | 2 | Ch.A frequency register(12bit)、Write only.
9882h-9883h | 2 | Ch.B frequency register(12bit)、Write only.
9884h-9885h | 2 | Ch.C frequency register(12bit)、Write only.
9886h-9887h | 2 | Ch.D frequency register(12bit)、Write only.
9888h-9889h | 2 | Ch.E frequency register(12bit)、Write only.
988Ah | 1 | Ch.A Volume (4bit)、Write only.
988Bh | 1 | Ch.B Volume (4bit)、Write only.

988Ch | 1 | Ch.C Volume (4bit), write only.
988Dh | 1 | Ch.D Volume (4bit), write only.
988Eh | 1 | Ch.E Volume (4bit), write only.
988Fh | 1 | output switch, Write only. bit0: Ch.A (0: mute, 1: output) bit1: Ch.B (0: mute, 1: output) bit2: Ch.C (0: mute, 1: output) bit3: Ch.D (0: mute, 1: output) bit4: Ch.E (0: mute, 1: output)
9890h-989Fh | 16 | 9880h-988Fh mirror.
98A0h-98BFh | 32 | Unused. Not read/write.
98C0h-98DFh | 32 | Unused??
98E0h-98FFh | 32 | Mode register.Write only. The substance is 1byte. bit0: frequency register specification of treatment of 1 bit1: frequency register specification of treatment of 2 bit5: frequency register waveform pointer reset on write bit6: All Ch. Waveform Rotate bit7: Ch.D. Waveform Rotate
9900h-9FFFh | 1792 | Unused??

Even if you read a register that is written as write-only, you cannot read a value with meaning.

The explanation of the SCC sound source is outside the scope of this book, so I will omit it.

### 4.5. Konami SCC-I type

So-called Snatcher sound cartridges and SD Snatcher sound cartridges fall into this category. In fact, it has DRAM instead of ROM.

As a mega ROM controller, it is the same as the Konami-SCC type, so please refer to 4.4. Konami SCC type for bank selection registers. On the other hand, there are differences due to the SCC installation, so I would like to explain the differences in this section.

The Snatcher sound cartridge is equipped with 64KB of DRAM as BANK#0 to BANK#7. On the other hand, the SD Snatcher sound cartridge has 64KB of DRAM as BANK#8 to BANK#15.

There is a pattern on the sound cartridge board that allows you to add DRAM,
so you can add two 4-bit | 64K DRAMs. As a board, four 4-bit | 64K DRAMs can ✕ | ✕
be mounted, and the place where the DRAM is installed is different between Snatcher and SD Snatcher. If you add DRAM to the two empty places, it will be a sound cartridge with 128KB of DRAM installed as BANK#0 to BANK#15.

The Konami SCC-I type has operation mode setting registers at BFFEh and BFFFh. BFFEh and BFFFh are the same register, and the actual size is only 1 byte. Figure 4.5-1 shows the bitmap of the operation mode setting register. The initial value seems to be 00h.

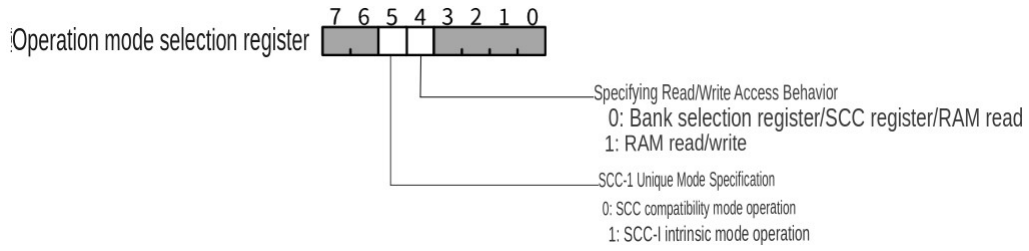
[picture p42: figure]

Fig 4.5-1. SCC-I Operation mode selection register

The operation mode selection register is write-only. Access is always possible regardless of the setting value of the operation mode selection register.

If you want to access the bank selection register or the SCC/SCC-I sound source register, you need to set bit4 to 0. Setting bit4 to 1 enables writing to the RAM in the sound cartridge. For example, when writing to address 9123h, if bit4 of BFFEh is 0, it will be written to the bank selection register of BANK2, but if bit4 of BFFEh is 1, it will be written to the RAM appearing in BANK2.

The SCC-I's SCC sound source section has two types: a mode compatible with the Konami SCC type and a mode expanded with a sound cartridge. Here, the former is called compatibility mode, and the latter is called eigenmode.

The compatibility mode is also slightly different compared to the Konami SCC type. The SCC sound source registers are shown in Table 4.5-1. Differences are shown in red.

Table 4.5-1. Compatibility mode SCC tone generator registers (BANK2-BANK#63)

Address | Size (byte) | meaning
8000h-8FFFh | 4096 | Unused??
9000h-97FFh | 2048 | BANK2 bank select register. The entity is 1 byte. Write only.
9800h-981Fh | 32 | wave memory ー 0 (for Ch.A), readable and writable.
9820h-983Fh | 32 | wave memory ー 1 (for Ch.B), readable and writable.
9840h-985Fh | 32 | wave memory ー 2 (for Ch.C), readable and writable.
9860h-987Fh | 32 | wave memory ー 3 Ch.D/E shared when writing. Ch.D when reading.
9880h-9881h | 2 | Ch.A frequency register(12bit), write only.
9882h-9883h | 2 | Ch.B frequency register(12bit), write only.
9884h-9885h | 2 | Ch.C frequency register(12bit), write only.
9886h-9887h | 2 | Ch.D frequency register(12bit), write only.
9888h-9889h | 2 | Ch.E frequency register(12bit), write only.
988Ah | 1 | Ch.A Volume (4bit), write only.
988Bh | 1 | Ch.B Volume (4bit), write only.
988Ch | 1 | Ch.C Volume (4bit), write only.
988Dh | 1 | Ch.D Volume (4bit), write only.
988Eh | 1 | Ch.E Volume (4bit), write only.
988Fh | 1 | output switch, Write only. bit0: Ch.A (0: mute, 1: output) bit1: Ch.B (0: mute, 1: output) bit2: Ch.C (0: mute, 1: output) bit3: Ch.D (0: mute, 1: output) bit4: Ch.E (0: mute, 1: output)
9890h-989Fh | 16 | 9880h-988Fh mirror.
98A0h-98BFh | 32 | wave memory ー 4 (for Ch.E), read only.
98C0h-98DFh | 32 | Mode register.Write only. The entity is 1 byte. bit0: frequency register specification of treatment of 1 bit1: frequency register specification of treatment of 2

| | bit5: frequency register waveform pointer reset on write bit6: All Ch. Waveform Rotate bit7: Invalid
98E0h-98FFh | 32 | Unused??
98E0h-9FFFh | 1792 | Unused??

Even if you read a register that is written as write-only, you cannot read a value with meaning.

9860h-987Fh writes the same value to both Ch.D wave memory and Ch.E wave memory for compatibility with SCC when writing. Reading 9860h-987Fh returns the value of Ch.D wave memory. If you want to read Ch.E wave memory, you can use 98A0h-98BFh. While only compatible mode is used, reading 9860h-987Fh and reading 98A0h-98BFh will return the same value, but once you switch to unique mode and rewrite the wave memory of Ch.E, then switch to compatible mode If you read it back, it seems that you can read a different waveform properly.

Please note that the Konami-SCC type and the address of the mode register are different.

Next, let's move on to explaining eigenmodes.

The unique mode SCC sound source register appears in BANK3, unlike the compatibility mode. I think this change was made because it is more convenient to use BANK0-2 continuously. The SCC sound source register is BANK#128 (strictly speaking, it is the same even if BANK#128 to BANK#255 are specified because all BANK#s have bit7 = 1 in the bank selection register) . Eigen mode allows you to set different waveforms for Ch.D and Ch.E. Register addresses are summarized in Table 4.5-2.

Tabela 4.5-2. Registros de fonte de som SCC de modo próprio (BANK3-BANK#128)

Address | Size (byte) | meaning
A000h-AFFFh | 4096 | Unused??
B000h-B7FFh | 2048 | Bank selection register. The entity is 1 byte. Write only.
B800h-B81Fh | 32 | wave memory ー 0 (for Ch.A), readable and writable.

B820h-B83Fh | 32 | wave memory ー 1 (for Ch.B), readable and writable.
B840h-B85Fh | 32 | wave memory ー 2 (for Ch.C), readable and writable.
B860h-B87Fh | 32 | wave memory ー 3 (for Ch.D), readable and writable.
B880h-B89Fh | 32 | wave memory ー 4 (for Ch.E), readable and writable.
B8A0h-B8A1h | 2 | Ch.A frequency register(12bit), write only.
B8A2h-B8A3h | 2 | Ch.B frequency register(12bit), write only.
B8A4h-B8A5h | 2 | Ch.C frequency register(12bit), write only.
B8A6h-B8A7h | 2 | Ch.D frequency register(12bit), write only.
B8A8h-B8A9h | 2 | Ch.E frequency register(12bit), write only.
B8AAh | 1 | Ch.A Volume (4bit), write only.
B8ABh | 1 | Ch.B Volume (4bit), write only.
B8ACh | 1 | Ch.C Volume (4bit), write only.
B8ADh | 1 | Ch.D Volume (4bit), write only.
B8AEh | 1 | Ch.E Volume (4bit), write only.
B8AFh | 1 | output switch, Write only. bit0: Ch.A (0: mute, 1: output) bit1: Ch.B (0: mute, 1: output) bit2: Ch.C (0: mute, 1: output) bit3: Ch.D (0: mute, 1: output) bit4: Ch.E (0: mute, 1: output)
B8B0h-B8BFh | 16 | B8A0h-B8AFh mirror.
B8C0h-B8DFh | 32 | Mode register.Write only. The entity is 1 byte. bit0: frequency register specification of treatment of 1 bit1: frequency register specification of treatment of 2 bit5: frequency register waveform pointer reset on write bit6: All Ch. Waveform Rotate bit7: Invalid
B8E0h-BFFDh | 1822 | Unused??
BFFEh-BFFFh | 2 | Operating mode selection register. The entity is 1 byte. Both addresses are the same.

Even if you read a register that is written as write-only, you cannot read a value with meaning.

The explanation of the SCC sound source is outside the scope of this book, so I will omit it.

### 4.6. Panasonic type

This | is | the | mega | ROM | type | installed | in | the | Panasonic | body
(FS-A1FX/WX/WSX/ST/GT). Built-in software, MSX-JE, etc. are stored, and it is connected to SLOT#3-3.

The BANK size is 8KB, which is similar to the ASCII-8K type, but Page0 and Page3 are not mirrors, and they also have independent bank selection registers. The bank selection register also has 9 bits per BANK, and can be selected within the range of BANK#0 to BANK#511. 8[KB] 512[BANK] = ✕ 4096[KB] = 4[MB] space can be handled.

He probably has the most memory attached to his FS-A1GT, but even with his FS-A1GT he doesn't use the full 4MB space. It seems that ROM-2MB, DRAM-512KB, and SRAM-32KB are connected in the form of part of his 4MB space (SRAM is battery-backed RAM for MSX-JE's learning dictionary).

The image seen from the slot is shown in Figure 4.6-1.

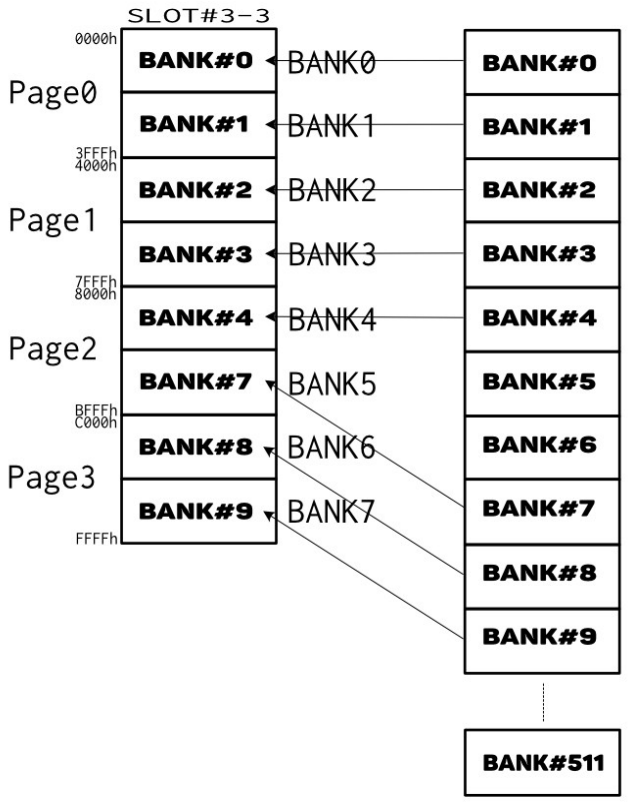
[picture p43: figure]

Figure 4.6-1. Image of Panasonic type Mega ROM

Address of bank register is shown in Table 4.6-1.

Table 4.6-1. Panasonic type Mega ROM bank register

Address | Size (byte) | meaning
6000h-63FFh | 1024 | The entity is 1 byte. Write only. Lower 8 bits of bank selection register of BANK0
6400h-67FFh | 1024 | The entity is 1 byte. Write only. Lower 8 bits of bank selection register of BANK1
6800h-6BFFh | 1024 | The entity is 1 byte. Write only. Lower 8 bits of bank selection register of BANK2
6C00h-6FFFh | 1024 | The entity is 1 byte. Write only. Lower 8 bits of bank selection register of BANK3

7000h-73FFh | 1024 | The entity is 1 byte. Write only. Lower 8 bits of bank selection register of BANK4
7400h-77FFh | 1024 | The substance is 1byte. Write only. BANK6 lower 8 bits of bank selection register
7800h-7BFFh | 1024 | The substance is 1byte. Write only. BANK5 lower 8 bits of bank selection register
7C00h-7FEFh | 1008 | The substance is 1byte. Write only. BANK7 lower 8 bits of bank selection register
7FF0h | 1 | Read-only. BANK0 cannot be read unless bit2 of is set to 1. 7FF9h cannot be read unless bit2 of is set to 1.
7FF1h | 1 | Read-only. BANK1 cannot be read unless bit2 of is set to 1. 7FF9h cannot be read unless bit2 of is set to 1.
7FF2h | 1 | Read-only. BANK2 cannot be read unless bit2 of is set to 1. 7FF9h cannot be read unless bit2 of is set to 1.
7FF3h | 1 | Read-only. BANK3 cannot be read unless bit2 of is set to 1. 7FF9h cannot be read unless bit2 of is set to 1.
7FF4h | 1 | Read-only. BANK4 cannot be read unless bit2 of is set to 1. 7FF9h cannot be read unless bit2 of is set to 1.
7FF5h | 1 | Read-only. BANK5 cannot be read unless bit2 of is set to 1. 7FF9h cannot be read unless bit2 of is set to 1.
7FF6h | 1 | Read-only. BANK6 cannot be read unless bit2 of is set to 1. 7FF9h cannot be read unless bit2 of is set to 1.
7FF7h | 1 | Read-only. BANK7 cannot be read unless bit2 of is set to 1. 7FF9h cannot be read unless bit2 of is set to 1.
7FF8h | 1 | Readable and writable. Upper 1bit of bank selection register. bit0: BANK0 high-order 1bit of bank selection register. bit1: BANK1 high-order 1bit of bank selection register. bit2: BANK2 high-order 1bit of bank selection register. bit3: BANK3 high-order 1bit of bank selection register.

| | bit4: BANK4 high-order 1bit of bank selection register. bit5: BANK5 high-order 1bit of bank selection register. bit6: BANK6 high-order 1bit of bank selection register. bit7: BANK7 high-order 1bit of bank selection register. 7FF9h cannot be read or written unless bit4 of is set to 1.
7FF9h | 1 | Mode register. Readable and writable. bit0: Invalid bit1: Invalid bit2: 7FF0h-7FF7h activation bit3: 7FF9h reading activation bit4: 7FF8h activation bit5: Invalid bit6: Invalid bit7: Invalid To read this register, you must first write 1 to bit3 of this register.

According to the reference material, FS-A1WX/WSX does not seem to have 7FF8h. Bit4 of 7FF9h is also Invalid. FS-A1FX is unknown.

Although it is an area to write the lower 8 bits of the bank selection register, it is not in a clean order. Please note that the order of BANK5 and BANK6 has been reversed, as shown in red in the table.

"Then, what are you connecting with this megacon?" The case of FS-A1GT is summarized below.

FS-A1GT is equipped with a total of 2MB of ROM, but this megacon is connected so that almost all of the installed ROM can be accessed (only the 16-dot Kanji ROM seems to be not included). Not only that, it seems that the built-in RAM can also be accessed via this megacon.

I will summarize below as far as I can understand.

<<Currently under investigation>>

BANK# | Content
BANK#0-#39 | Built-in software 320KB (40BANK) Each 16KB (2BANK) has a signature of WSXSEGxxPx
BANK#40-#43 | MAIN-ROM 32KB(4BANK)

BANK#44-#47 | Built-in software 32KB (4BANK) Each 16KB (2BANK) has a signature of WSXSEGxxPx
BANK#48-#55 | DiskBIOS 64KB (8BANK)
BANK#56-#57 | SUB-ROM 16KB (2BANK)
BANK#58-#61 | Chinese character Driver 32KB (4BANK)
BANK#62-#63 | MSX-MUSIC 16KB (2BANK)
BANK#64-#127 | MSX-JE conversion dictionary 512KB (64BANK)
BANK#128-#131 | MSX-JE for conversion dictionaries SRAM 32KB (4BANK)
BANK#132-#159 | Disconnected 224KB (28BANK)
BANK#160-#191 | ROM Disk Latter half?? 256KB (32BANK)
BANK#192-#255 | Disconnected 512KB (64BANK)
BANK#256-#319 | ROM Disk first half 512KB (64BANK)
BANK#320-#383 | Disconnected 512KB (64BANK)
BANK#384-#447 | MAIN-RAM 512KB (64BANK)
BANK#448-#511 | MAIN-RAM 512KB (64BANK)、BANK#384-#447mirror

In turboR's primary mapper RAM, 4 segments are reserved as the BIOS copy area in order from the larger segment # value. For the primary mapper slot of SLOT#3-0, there is a feature that its 4 segments are write-protected in R800-DRAM mode. This probably protects the ROM cartridge software or memory mapper applications for MSX-DOS1 from accidentally overwriting the BIOS copy.

However, "BANK# where the contents of the primary mapper RAM appear" appearing in SLOT#3-3 has the feature that the entire area including the BIOS copy area can be written.

### 4.7. Pana amusement cartridge

Two types of PAC and FM-PAC released by Panasonic were on sale. Equipped with an 8KB battery-backed SRAM for saving game data, but it is disabled by default, and the SRAM appears when the prescribed processing shown in Table 4.7-1 is performed. I'm here.

Table 4.7-1. PAC SRAM switching

Prescribed processing | Effect
Write 5FFEh To 4Dh Write 5FFFh To 69h | Appear 4000h-5FFFh To SRAM
To 5FFEh or 5FFFh other than above | Disconnect SRAM at 4000h-5FFFh

8 KB is divided into 1 KB units To 8 areas To, and icons indicating which of these 8 areas are used are printed on the boxes of PAC compatible game software. There is no management information for these eight areas To, and each game maker uses them freely, so there is no way to determine which area is in use from the program. It was up to the user to overwrite the same area.

In the case of FM-PAC, the MSX-MUSIC ROM appears when the SRAM is disconnected, so its existence can be confirmed by detecting the signature "PAC2OPLL" from 4018h to To.

In the case of PAC, if the SRAM is disconnected, it behaves like an unconnected state, so even if it is read, a value with meaning cannot be obtained. FFh is generally returned no matter where you read it. When detecting, after confirming that there is no 4000h, 4001h To 41h, 42h and that it is not RAM, try writing 5FFEh, 5FFFh To 4Dh, 69h, and confirm that 4000h-5FFDh has changed to RAMTo is OK. You can check whether it is RAM or not with the following code, assuming that the address you want to check is set to HL To.

LD A, [HL]
CPL
LD | [HL], A
CP | A, [HL]
CPL
LD [HL], A

The original value is read from the A register To, all bits are reversed, and then To is written back. If it matches the written value, it is RAM, and if it does not match, it is not RAM (ROM, unconnected, etc.). In the case of RAM, it would be a problem to destroy Tovalue, so at the end To is reversed all bits to restore the original valueTo and write it back. Since the CPL and LD instructions do not change the Z flag, you can see the value of the Z flag determined by the CP instruction To. If the To Z flag is set after executing this process, it means that it is RAM, and if it is not set, it is not RAM.

### 5. ROM cartridge operation

When the power is turned on, MSX first boots from MAIN-ROM in SLOT#0 or SLOT#0-0. The BIOS program on the MAIN-ROM first checks the RAM installation status of Page2 and Page3, and searches for ROM for all slots with RAM appearing on Page2 and Page3. ROM search is performed in order of
SLOT#0 SLOT#1 SLOT#2 SLOT#3. The expansion slots are SLOT#X-0 → | → | → | →
SLOT#X-1 | SLOT#X-2 | SLOT#X-3. → | →

In MSX, it is a rule to write the ROM header at the beginning of the ROM cartridge. If you write the appropriate ROM headers, the BIOS that interprets them will call the necessary programs in the ROM cartridge. The ROM header is supposed to be placed at the beginning of Page1 (4000h~) or at the beginning of Page2 (8000h~). It is better to use the beginning of Page1 (4000h~) for all machine language programs, and the beginning of Page2 (8000h~) to ROMize programs created in MSX-BASIC. Page1 Page2 is searched in order. ROM → headers are summarized in Table 5.1.

Table 5.1. ROM header

Address | Size (byte) | Name
+0000h | 2 | ID
+0002h | 2 | INIT
+0004h | 2 | STATEMENT
+0006h | 2 | DEVICE
+0008h | 2 | TEXT
+000Ah | 6 | RESERVED

The ID is a signature that indicates that the ROM is out. Write 41h, 42h ( "AB" ).

INIT writes the address of the initialization routine. If you do not initialize, please set 0000h To. On the other hand, for game cartridges, etc., please write the Address here, which is the entry point of the To game.

STATEMENT writes the address of the extended routine when extending the CALL instruction of MSX-BASIC. If you do not want to extend the CALL instruction, please set it to 0000h.

DEVICE writes the Address of the device extension routine. If you don't need it, please set it to 0000h.

TEXT specifies the storage address of the program written in MSX-BASIC that is in the cartridge. If the cartridge does not have MSX-BASIC program written, set to 0000h.

RESERVED is an area reserved for future expansion. Please fill it with 0.

### 5.1. Create a 16KB ROM cartridge program

Game software that does not use a disk generally starts from the address written in INIT. An example of a simple ROM program is shown below.

ROM_sample001.ASM

; =============================================================================
; | ROM_sample001.ASM
; -----------------------------------------------------------------------------
; | Jan./31/2020 HRA!
; =============================================================================
chput | = 0x00A2
himem | = 0xfc4a
org | 0x4000
; ==============================================================================
; | ROM Header
; ============================================================================== rom_header_id:
ds | "AB"
rom_header_init:
dw | entry_point
rom_header_statement:
dw | 0
rom_header_device:
dw | 0
rom_header_text:
dw | 0
rom_header_reserved:
space | 0x0010 - 0x000A, 0

; ==============================================================================
; | Program entry point
; ============================================================================== entry_point:
; Initialize Stack Pointer
ld | sp, [himem]

main_loop:
; Put message
ld | hl, display_message

call | puts
jp | main_loop

; ==============================================================================
; | puts
; | input)
; | HL .... address of target string (ASCII-Z)
; ============================================================================== puts:
ld | a, [hl]
inc | hl
or | a, a
ret | z
call | chput
jp | puts

display_message:
ds | "Hello, world!! "
db | 0
align | 16384

Pass it to the assembler ZMA and assemble it with the following command.

zma ROM_sample001.ASM ROM_sample001.ROM

After assembling, a 16KB ROM image file named ROM_sample001.ROM will be created. You can start it with an emulator, so please try it. If it is displayed as shown in Figure 5.1, it works as expected.

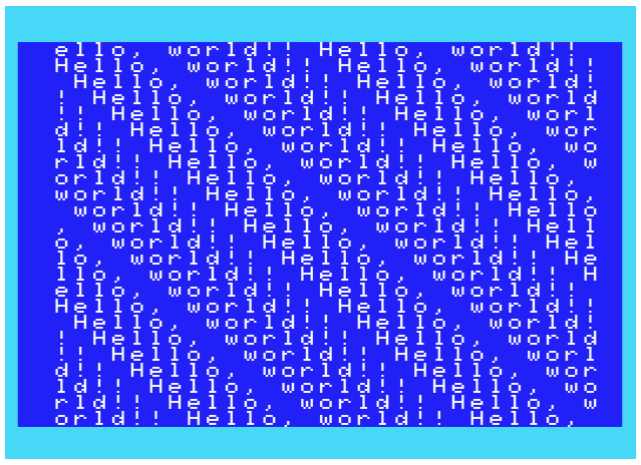
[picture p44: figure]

Figure 5.1. Execution image of ROM_sapmle001.ROM

Figure 5.1. Execution image of ROM_sapmle001.ROM

org | 0x4000

ZMA assembles the source code from top to bottom and writes it to the output file. At that time, it is assembled while internally calculating "what address the Z80 recognizes as the code." for calculating the absolute address of the label. org 0x4000 tells ZMA that this next line is at 0x4000.

A 16KB ROM should have 14-bit signals from A13 to A0 as address signal lines. Connect this to A13 to A0 of the cartridge slot as it is, A15 and A14 are not connected, /SLTSL of the cartridge slot is connected to /CS of the ROM, /RD of the cartridge slot is connected to /OE of the ROM. When making a Z80, the contents of this ROM appear in all of Page0, Page1, Page2, and Page3. Among these, Page1 is the one that the BIOS checks first, so place it in Page1. Make the program assuming it is written. Since the beginning of Page1 is 0x4000, it is set to org 0x4000.

rom_header_id:
ds | "AB"
rom_header_init:
dw | entry_point
rom_header_statement:
dw | 0
rom_header_device:
dw | 0
rom_header_text:
dw | 0
rom_header_reserved:
space | 0x0010 - 0x000A, 0

I mentioned earlier that the ROM header must be written to 0x4000~0x400F. This is its ROM header.

Rom_header_id corresponds to the ID in Table 5.1. This is always the case with any ROM cartridge.

It is "AB". It's a mark to tell the BIOS "here's the ROM header".

Rom_header_init corresponds to INIT in Table 5.1. Enter the entry point address here enter. It's labeled entry_point in this program.

Others are not used this time, so fill them with 0.

entry_point:
; Initialize Stack Pointer
ld | sp, [himem]

Label entry_point is the entry point for this program. Stackpoint first and foremost initialize data. For normal programs, the value stored in himem should be used. himem contains the lowest address of the BIOS work area.

main_loop:
; Put message
ld | hl, display_message
call | puts
jp | main_loop

The subroutine puts will appear next, but if you specify the start address of the character string in HL and call it, a routine that displays that string (like her PRINT statement in MSX-BASIC). This time, as shown in Figure 5.1, so the label display_message is "Hello, world!!" is stored.

puts:
ld | a, [hl]
inc | hl
or | a, a
ret | z
call | chput
jp | puts

This is the contents of puts. The BIOS has a routine called CHPUT that controls the operation that, when written in MSX-BASIC, it works like PRINT CHR$( A ); A here is the A register hey. With puts, the contents of the address indicated by the HL register are read into the A register, checked for 0, and if so, return, if not 0, use CHPUT to print one character, and repeat.

CHPUT preserves the contents of all registers, so the HL register is preserved.

display_message:
ds | "Hello, world!! "
db | 0

The label display_message assigned to HL at main_loop is here.

In ZMA, the ds directive is "Define String". ASCII code for each letter in Hello, world!! is placed as is. The db pseudo-instruction uses 0 as a terminator. The terminator is what the subroutine puts from earlier interprets.

The terminator is what the subroutine puts from earlier interprets.

align | 16384

Finally there is the align instruction. ROM_sample001.ASM is a small program less than 16KB. This is a pseudo-instruction that adds padding to make it 16KB.

Just as CHPUT could be used earlier, when ROM INIT is called, Page0 is MAIN-ROM (BIOS), Page 1 is the ROM of the ROM cartridge, Page 3 is the BIOS work area, etc.

You can see that it is a RAM that Page2 differs depending on the model. For models with 16KB of RAM, this is SLOT#0 or SLOT#0-0 of SLOT#0/#0-0. The information placed on Page2 also differs depending on the model, so it may be unconnected or some built-in software. It could be ROM or whatever. It's not RAM anyway.

On models with 32KB or more of RAM, this is the RAM slot for Page2.

It is possible to determine whether the RAM is 32KB or more or the RAM is 16KB or less depending on whether Page2 is RAM or not. I don't think there are many software that bother to check it, but it works with 16KB, and it's different with 32KB. I think that it is necessary to judge when it behaves in a different way.

Furthermore, models with 8KB of RAM, such as the CASIO PV-7, have RAM only in E000h-FFFFh for Page3 does not exist. C000h-DFFFh cannot be written.

As a method to check whether it is RAM or not, read the value from the address you want to check and save it in a register. Same write the inverted value to the address, read it again, and if the inverted value can be read, the RAM is read. If not, it is not RAM (such as ROM or unconnected), and if it is RAM, it writes back the saved value. There is a way to The BIOS seems to do the same when checking for the presence of RAM. Note that the RAM SLOT#s for Page2 and Page3 are not necessarily the same. A program that assumes that is dangerous.

Memory Mapper compatible RAM must have RAM in all Pages 0 to 3 of that slot. For models with memory mapper compatible RAM, the RAM that appears on Page2 and Page3 is the same. It is SLOT#. The MSX1 and some MSX2 do not have RAM that supports memory mapper. Please be careful. If it is a cartridge for MSX2+ or later, it appears on Page2 and Page3 so it may not be a problem to assume that the RAM is the same SLOT#.

Stores RAM SLOT#s corresponding to Page0 to Page3 as a work area for the disk BIOS. There are areas from RAMAD0 to RAMAD3. However, when the ROM cartridge starts so this value is not stored yet. The disk BIOS itself has the same implementation as the ROM cartridge. Yes, most models with a built-in disc are equipped with SLOT#3-X. Disk BIOS initialization since it is before the routine is called, it is not stored. On the other hand, put the external drive in SLOT#1, it may be stored if the ROM cartridge you made is installed in SLOT#2. for that reason, SP initialization refers to HIMEM and other modules that may be present, such as disk BIOS it's safe to avoid destroying your work area. Remove unnecessary devices when playing games, etc. The promise of "please" is a preventive measure to prevent unexpected accidents due to such special cases.
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

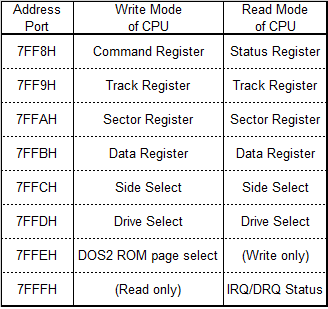
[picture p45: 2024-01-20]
media/3-2-1_DOS2.png

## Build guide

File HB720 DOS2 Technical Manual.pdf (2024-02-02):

# MSX Dual Disk Drive Controller HB720 DOS 2.X Version

# Based on Memory Mapped I/O Registers

# Super exceeds compatibility from:

# EPCOM/SHARP HB-3600

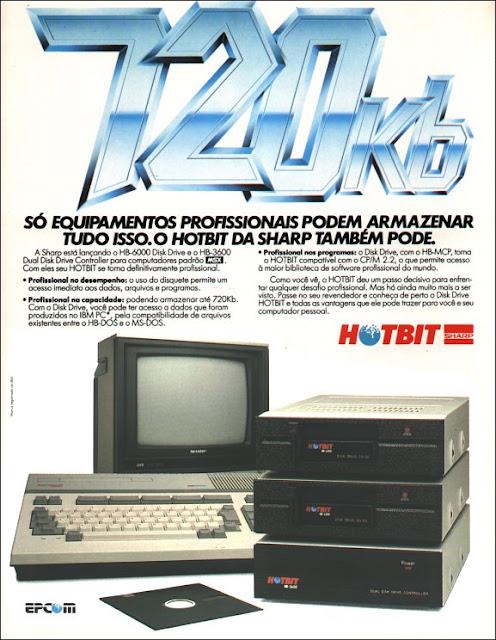
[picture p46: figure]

# SONY HBD-50

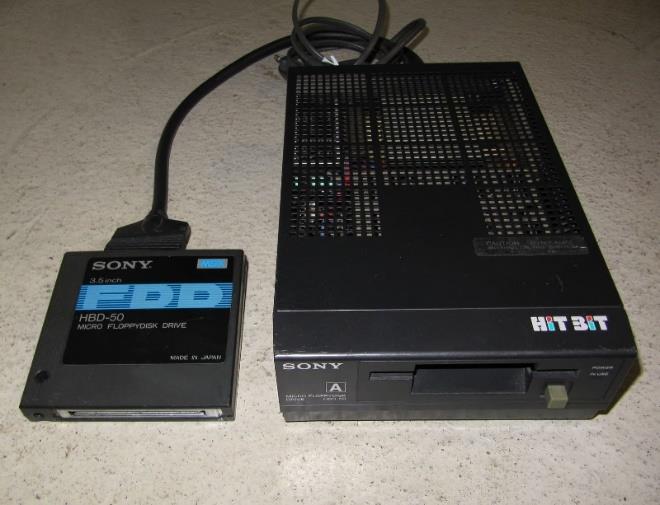
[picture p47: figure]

## Based on MSXHans, 2001 PDF

By Evandro Souza 2024, January.

### 1. OPERATION

1-1.FEATURES | 1-1
1-2.SPECIFICATIONS | 1-1
1-3.PARTS IDENTIFICATION | 1-1
1-3-1Drive Unit | 1-1
1-3-2. Interface Cartridge | 1-1
1-4. CONNECTING THE UNIT | 1-2
1-5. INSERTING A DISK | 1-2
1-6. STARTING UP MSX-DISK BASIC | 1-2
1-7.FORMATTING A BLANK DISK | 1-3
1-8.PIN ASSIGNMENT OF THE CONNECTORS | 1-3

## TABLE OF CONTENTS

### 2. BLOCK DIAGRAM

OVERALL BLOCK DIAGRAM | 2-1

### 3. THEORY OF OPERATION

3-1. HB720 CARTRIDGE |
3-1-1. Memory Map | …
3-1-2. Selection by Cartridge | …
3-1-3. Selection by FDC Controller |
3-2. FDC |
3-2-1. Memory Map of Control Ports in detail | …
3-2-2. Selection of Individual FDC Registers . |
3-2-3. Operation of Individual Registers | …

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
### 4. SCHEMATIC DIAGRAM AND PRINTED

CIRCUIT BOARD

HB720 BOARDS | | 4-1
CARTRIDGE BOARD PCB | 4-1
CARTRIDGE BOARD Schematics. | 4-2
FDC BOARD PCB.. | 4-3
FDC BOARD SCHEMATICS | 4-4

SEMICONDUCTOR PIN
ASSIGNMENTS | 5-1

5.

## CHAPTER 1

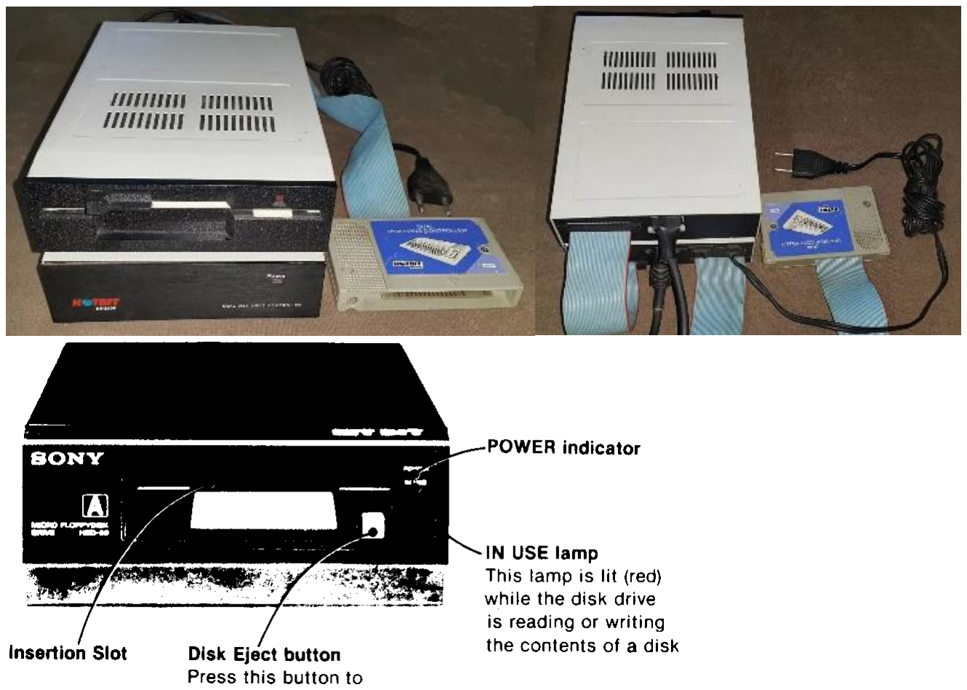
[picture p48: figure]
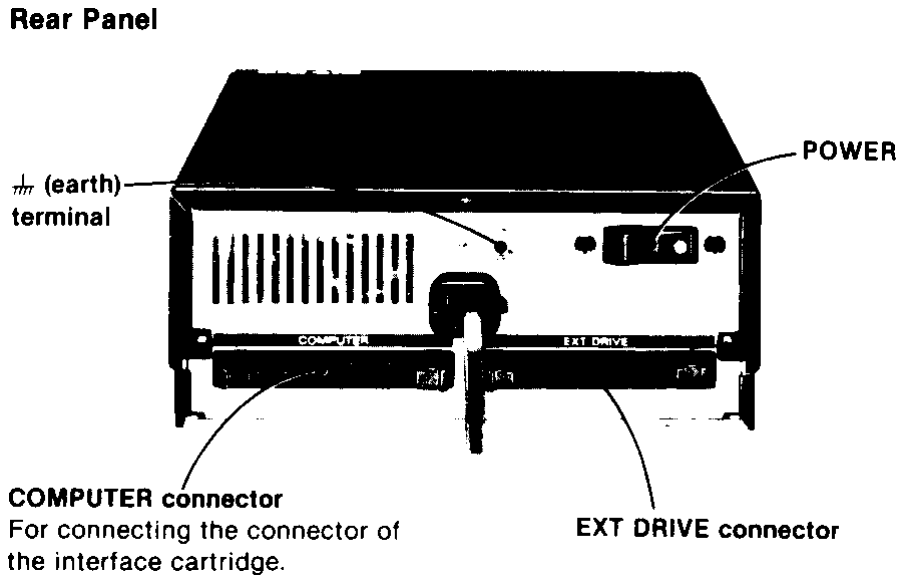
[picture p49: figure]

HB720 Dual Disk Drive Controller | 1-1

# OPERATION

1-3. PARTS IDENTIFICATION

United kingdom model 240V ac, 50Hz
European model 220 V ac, 50 Hz
Brazilian model 127/220V ac (switch selected) 60 Hz United Kingdom model 25W
European model 24 W
Brazilian model 16W
10oC-35°C (50oF-95°F) 160 x 67 x 260 mm (w/h/d) For the drive unit only, including the projecting parts Interface cartridge : 240 g
Drive unit: 2.7 kg (excludes the disk)
Blank disk (1)
Disk labels (3)

The HBD-50 floppy disk drive unit allows 3 1/2-inch micro floppy disks to be used with an MSX standard computer.
The 3 1/2-inch micro floppy disk is packaged in a hard case provided with a metal disk guard. 360K bytes of data can be recorded on a single disk and the contents can be easily retrieved and rewritten. This floppy disk drive unit will greatly extend the information-handling capabilities of your MSX computer.

1-3-1. Drive Unit

1-2. SPECIFICATIONS

Interface Section
Interface specifications
Internal ROM

Power consumption

Fits to MSX slots
64K bytes
Standard I/O routines
Enhanced DOS routines
MSX-Disk BASIC 2 Utility routines

+ 5 V, 300 mA or less

Drive Section
Disk used
Disk type
Recording capacity

5¼” and 3

1
/2" floppy disk
Single and Double-sided
Formatted: 360K / 720K bytes Bytes/sector: 512
Sectors/track: 9
Tracks/cylinder: 2
Tracks/disk: 80
Bytes/disk: 360K / 720K
40 / 80 cylinders
40 / 80 / 160 tracks
MFM (Modified-Frequency Modulation) 300 rpm
250 K bits/sec
100 msec
Average: 350 msec
Between tracks: 12 msec
Settling time: 30 msec
WD2793-02

Total no. of cylinders
Total no. of tracks
Recording method
Disk rotation speed
Data transfer rate
Average latency time
Access time

Controller

1-1. FEATURES

General
Power requirements

Power consumption

1-3-2. Interface Cartridge

Interface cartridge

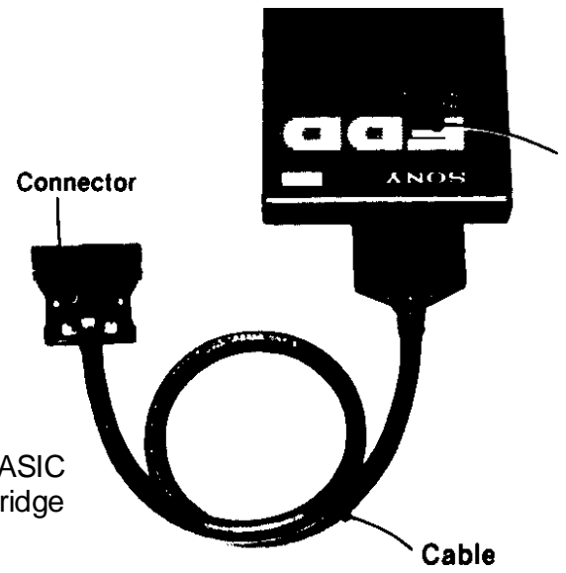
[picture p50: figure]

This cartridge contains MSX-Disk BASIC on ROM and is inserted into the cartridge slot of the computer.

Operating temperature
Dimensions
Weight

Accessories

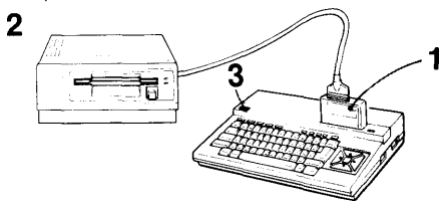
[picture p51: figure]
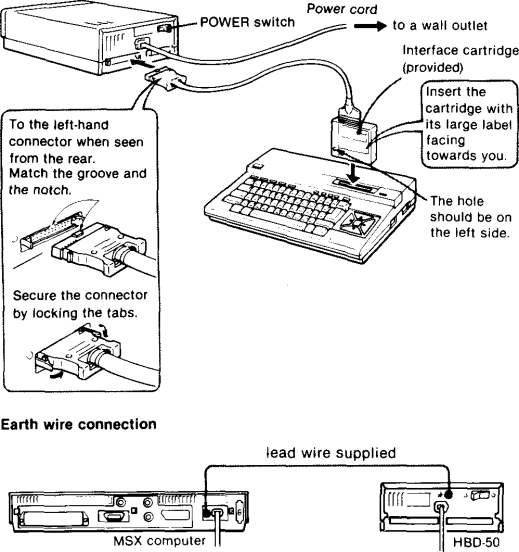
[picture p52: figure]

1-2 | HB720 Dual Disk Drive Controller

1-6. STARTING UP MSX-DISK BASIC

Notes on connection
Set the POWER switch of the device to be connected to OFF. Connecting the device while its power is ON may damage the internal circuitry. eWhen disconnecting the connector or cartridge, be sure to take hold of the plug or the cartridge. Pulling on the cord may break the wires.
•As a safety precaution, do not connect the power cord until all other connections have been completed.

MSX-Disk BASIC is stored in ROM (read-only memory) within the interface cartridge of HBD-50.
When the interface cartridge is inserted into the cartridge slot of the computer, Disk BASIC is started up by simply switching on the power of the disk drive unit and the computer.
1 | Insert the interface cartridge.
2 | Set the POWER switch of HBD-50 to ON.
3 | Set the POWER switch of the computer to ON.
| When Disk-BASIC begins operating, the following message is displayed
| on the screen :
4 | Enter the year, month, and date using two digits per entry (and connecting each entry by a hyphen) or simply press the [RETURN| key¹ ). When the [RETURN] key is pressed, the screen will display the following message which indicates the Disk-BASIC has “signed on”.

Precautions
Be sure to switch on the power of the drive unit before that of the computer. If the computer has been turned on first, either press the RESET button of the computer or set the POWER switch of the computer to OFF, then to ON.
1-5. INSERTING A DISK

Without opening the metal disk guard, insert the floppydisk and gently push it in until you hear a click.

1) With MSX Disk-BASIC, date data set in this situation is not used.

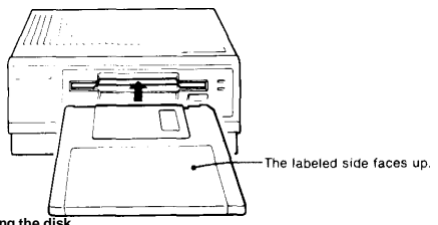
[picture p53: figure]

Removing the disk

Press this button.

1-4. CONNECTING THE UNIT

HB720 Dual Disk Drive Controller | 1-3

## 1-7. PIN ASSIGNMENT OF THE CONNECTORS

Pin Assignment of the Connectors

HB720 CARTRIDGE TO FDC: IDC 34 pins connector (BOTH SIDES)

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

34 32 30 28 26 24 22 20 18 16 14 12 10 8 6 4 2

HB720 FDC TO EXT FLOPPPY DRIVE – Edge card connector (34 pins)
The pinout are the same for 5 ¼” and 3 ½” drives and the cable may have both options: To use with 5 ¼”, the connector is a card edge;
To use with 3 ½” the connector is a 34 pin female IDC.

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

34 32 30 28 26 24 22 20 18 16 14 12 10 8 6 4 2

Pi n No. | Si gnal | Pi n No. | Si gnal | Pi n No. | Si gnal | Pi n No. | Si gnal
1 | GNDD (RET URN) | 10 | FDC_RE | 19 | GNDD (RET URN) | 28 | FDC_D5
2 | DRQ | 11 | GNDD (RET URN) | 20 | FDC_D1 | 29 | GNDD (RET URN)
3 | N.C. | 12 | FDC_A0 | 21 | GNDD (RET URN) | 30 | FDC_D6
4 | IRQ | 13 | GNDD (RET URN) | 22 | FDC_D2 | 31 | GNDD (RET URN)
5 | GNDD (RET URN) | 14 | FDC_A1 | 23 | GNDD (RET URN) | 32 | FDC_D7
6 | FDC_WE | 15 | GNDD (RET URN) | 24 | FDC_D3 | 33 | GNDD (RET URN)
7 | N.C. | 16 | FDC_A2 | 25 | GNDD (RET URN) | 34 | RESET
8 | FDC_CS | 17 | GNDD (RET URN) | 26 | FDC_D4
9 | GNDD (RET URN) | 18 | FDC_D0 | 27 | GNDD (RET URN)
Pi n No. | Si gnal | Pi n No. | Si gnal | Pi n No. | Si gnal | Pi n No. | Si gnal
1 | DISK CHANGE RESET | 10 | DRIVE SELECT 0 | 19 | GNDD (RET URN) | 28 | WRIT E PROT ECT
2 | DISK CHANGE | 11 | GNDD (RET URN) | 20 | ST EP | 29 | GNDD (RET URN)
3 | GNDD (RET URN) | 12 | DRIVE SELECT 1 | 21 | GNDD (RET URN) | 30 | READ DAT A
4 | IN USE | 13 | GNDD (RET URN) | 22 | WRIT E DAT A | 31 | GNDD (RET URN)
5 | GNDD (RET URN) | 14 | DRIVE SELECT 2 | 23 | GNDD (RET URN) | 32 | (HEAD SELECT )
6 | DRIVE SELECT 3 | 15 | GNDD (RET URN) | 24 | WRIT E GAT E | 33 | GNDD (RET URN)
7 | GNDD (RET URN) | 16 | M OT OR ON | 25 | GNDD (RET URN) | 34 | READY
8 | INDEX | 17 | GNDD (RET URN) | 26 | T RACK 00 | None | NONE
9 | GNDD (RET URN) | 18 | DIRECT ION | 27 | GNDD (RET URN) | None | NONE

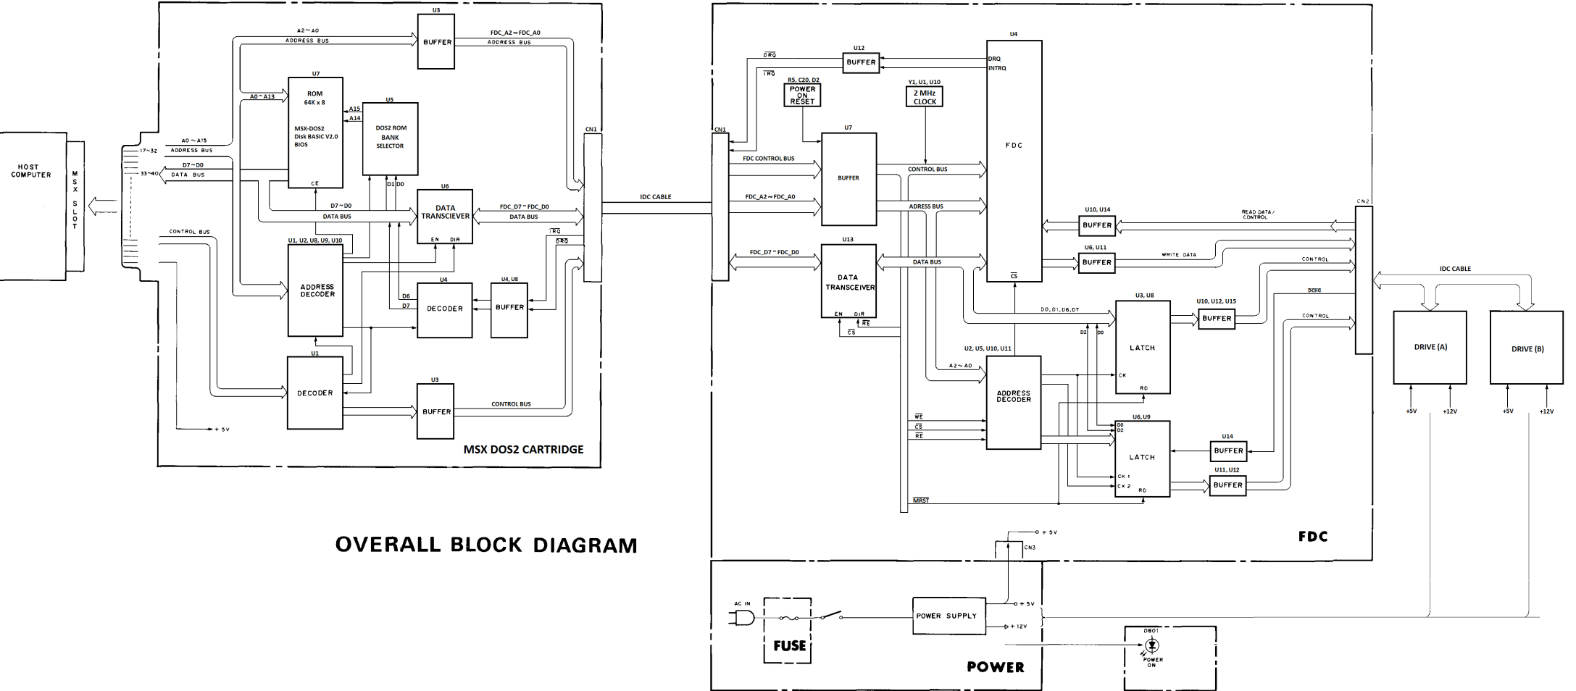
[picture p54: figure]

2-1 | HB720 Dual Disk Drive Controller

## CHAPTER 3

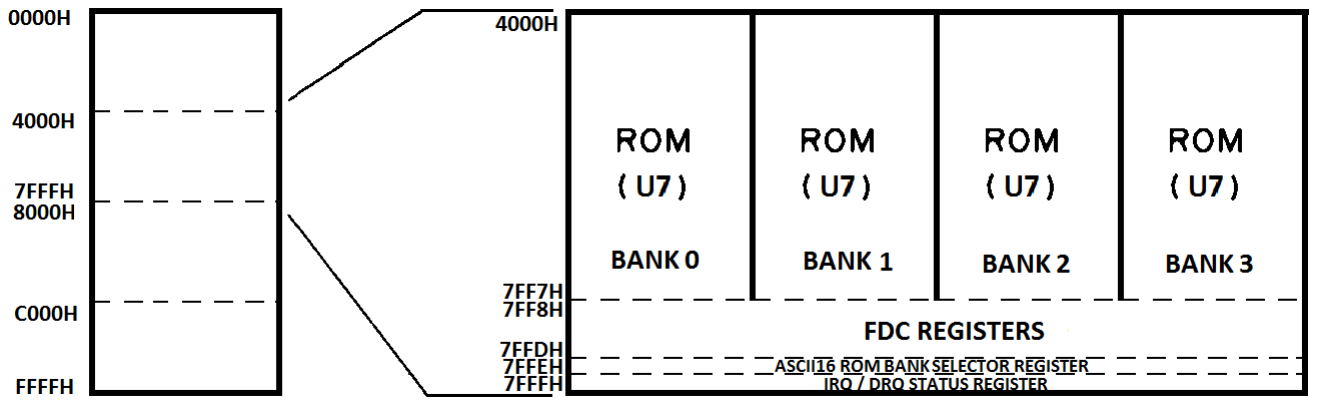
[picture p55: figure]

3-1 | HB720 Dual Disk Drive Controller

# 3. THEORY OF OPERATION

## 3-1. Cartridge Board

3-1-1. Memory Map

This board cartridge uses the MSX computer cartridge slot. Addresses 4000H through 7FFFH on the memory map have been allocated to the HB720 cartridge.

3-1-2. Selection by HB720 Cartridge

When the HB720 cartridge has been inserted into the MSX computer cartridge slot, addresses 4000H through 7FFFH will be selected by the cartridge connector signal CS1. In addition, U1 will AND signal SLTSL and the U2 (address decoder) output that has been inverted by U8, and will provide an output to U7 (ROM) pin CE for selection of the ROM.

3-1-3. Selection by FDC Controller

Individual registers of the FDC board have been allocated to the memory space for addresses 7FF8H through 7FFDH, and are selected by address signals A0 through A2 and signal FDC_CS.

## CHAPTER 3

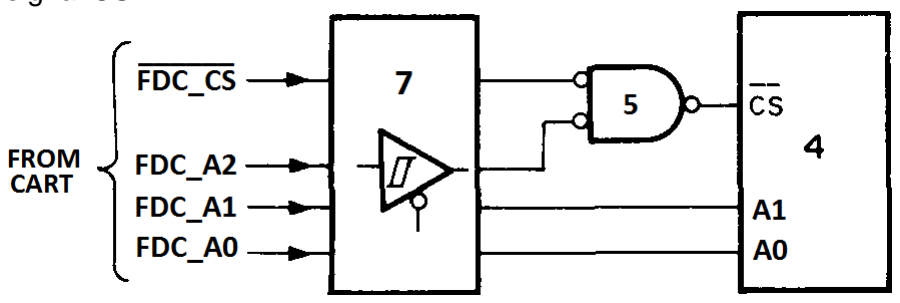
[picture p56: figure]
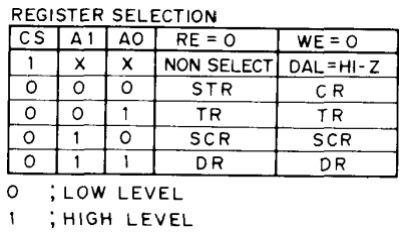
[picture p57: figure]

3-2 | HB720 Dual Disk Drive Controller

## 3-2. FDC Board

3-2-1. Memory Map of Control Ports in detail

3-2-2. Selection of Individual FDC chip Registers

Individual registers of the FDC (U4) have been allocated to addresses 7FF8H through 7FFBH, and are selected by address signals AO through A2 and signal CS.

CR (COMMAND REGISTER
DR (DATA REGISTER
DSR (DATA SHIFT REGISTER
SCR (SECTOR REGISTER
TR (TRACK REGISTER
STR (STATUS REGISTER

Hl-Z (HIGH IMPEDANCE)

3-2-3. Operation of Individual Registers

- Command Register (CR) - 7FF8H

This is an 8-bit write register, where the commands that correspond to the WD2793-02 operation will be written from the processor.
With the exception of a forced interrupt command, the command writing operation takes place after completion of the previous WD2793-02 command.
- Status Register (STR) - 7FF8H

This is an 8-bit read register. This register indicates the WD2793-02 internal status, the command execution processed status, and the disk drive status. The significance of individual bits will vary depending on whether the command is being executed or the command execution has already been concluded.

- Track Register (TR) - 7FF9H

This is an 8-bit read/write register. The low-high transition of MR (master reset) will set TR at FFH. When TR00 becomes low, TR will be made 00H.
The track number at which the head is located will usually be set in this register. At WD2793-02, this value may either be updated or not, depending on the command. In the case of a read data command or a write data command, the contents of this register will be compared with an ID field track number read of the disk, and when they coincide with each other, the read or write operation will duly be carried out.
- Sector Register (SCR) - 7FFAH

This is an 8-bit read/write register. In the case of a read data command or a write data command, the contents of this register will be compared with an ID field track number read of the disk, and when they coincide with each other, the read or write operation will duly be carried out.
When under a read address command, the ID field track number will be retained intact.
Address Port | Write Mode of CPU | Read Mode of CPU
7FF8H | Command Register | Status Register
7FF9H | Track Register | Track Register
7FFAH | Sector Register | Sector Register
7FFBH | Data Register | Data Register
7FFCH | Side Select | Side Select
7FFDH | Drive Select | Drive Select
7FFEH | DOS2 ROM bank select | (Write only)
7FFFH | (Read only) | IRQ/DRQ Status

## CHAPTER 3

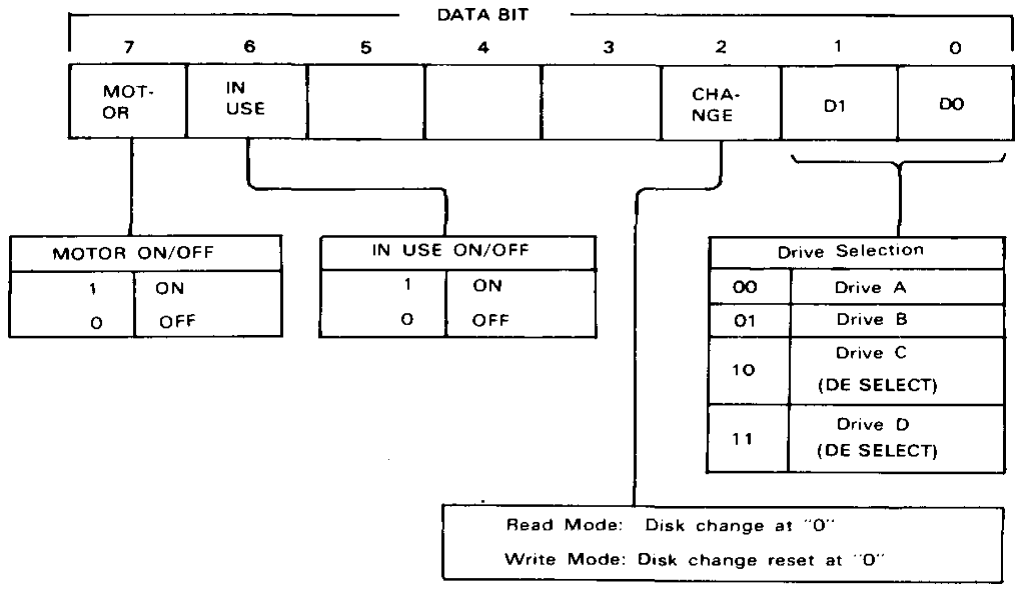
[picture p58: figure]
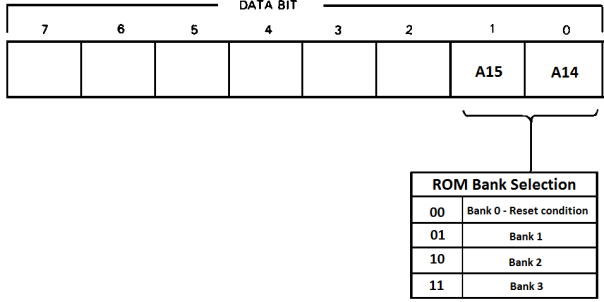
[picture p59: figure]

3-3 | HB720 Dual Disk Drive Controller
- Data Register (DR) - 7FFBH

This is a read/write register. In a disk reading mode, the data read of the disk will be loaded into this register. In a disk writing mode, the data that has been written earlier into this register will be written into the disk. In a seek mode, the target track address will be written this register

- Side Select - 7FFCH

At "0", side 0 will be selected, and at "", side 1 will be selected

- Drive Select -7FFDH
- ASCII16 - DOS2 ROM Bank Selector - 7FFEH

This is a write-only register.
It works as an ASCII16 mapper and selects each 16K bytes bank of ROM to be addressable by CPU in 4000H to 7FFFH CPU address range.
Obs.: Programming technics of ASCII16 switching control are out of scope of this hardware explanation document.
- IRQ/DRQ Status - 7FFFH

IRQ will be made "0" when the completion of a command has been either concluded or terminated during process. DRQ will be made "0" when the data write/read are being requested

## CHAPTER 4

# 4. HB720 Boards

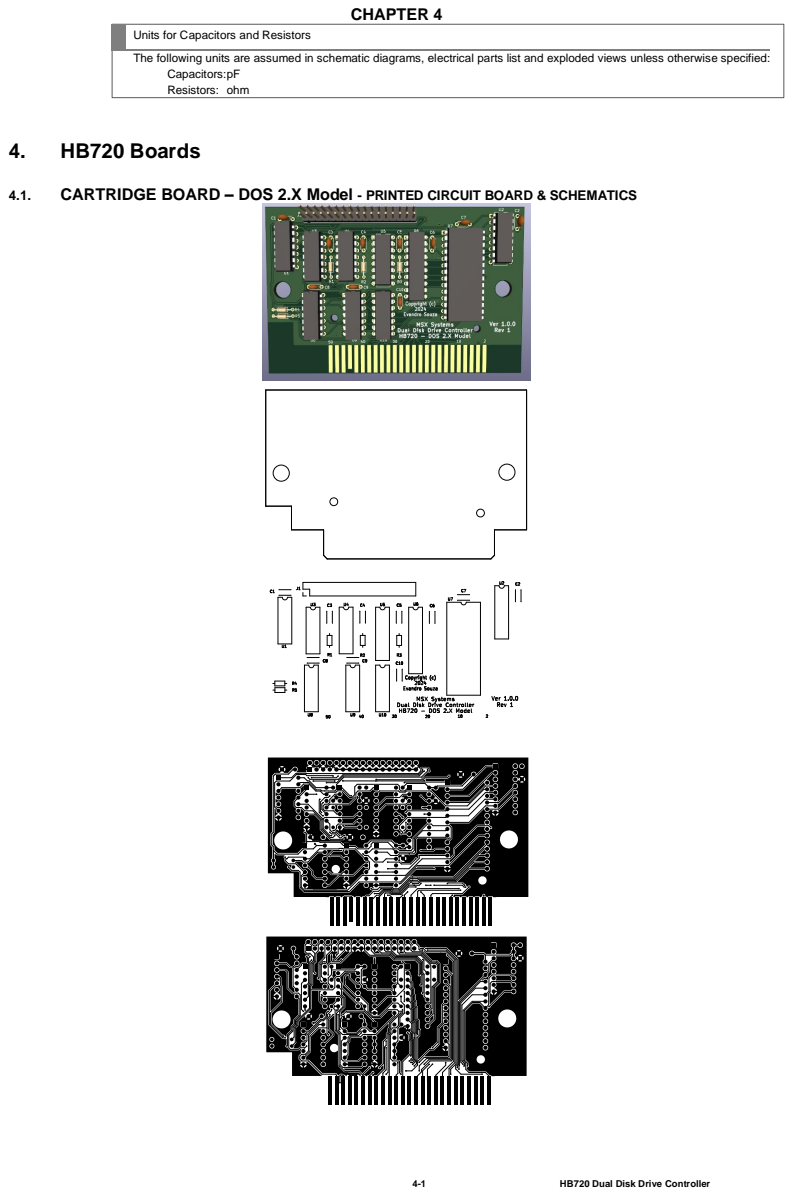
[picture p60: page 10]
HB720 Dual Disk Drive Controller; Capacitors:pF Resistors: ohm

Units for Capacitors and Resistors

The following units are assumed in schematic diagrams, electrical parts list and exploded views unless otherwise specified:

4.1. CARTRIDGE BOARD – DOS 2.X Model - PRINTED CIRCUIT BOARD & SCHEMATICS

## CHAPTER 4

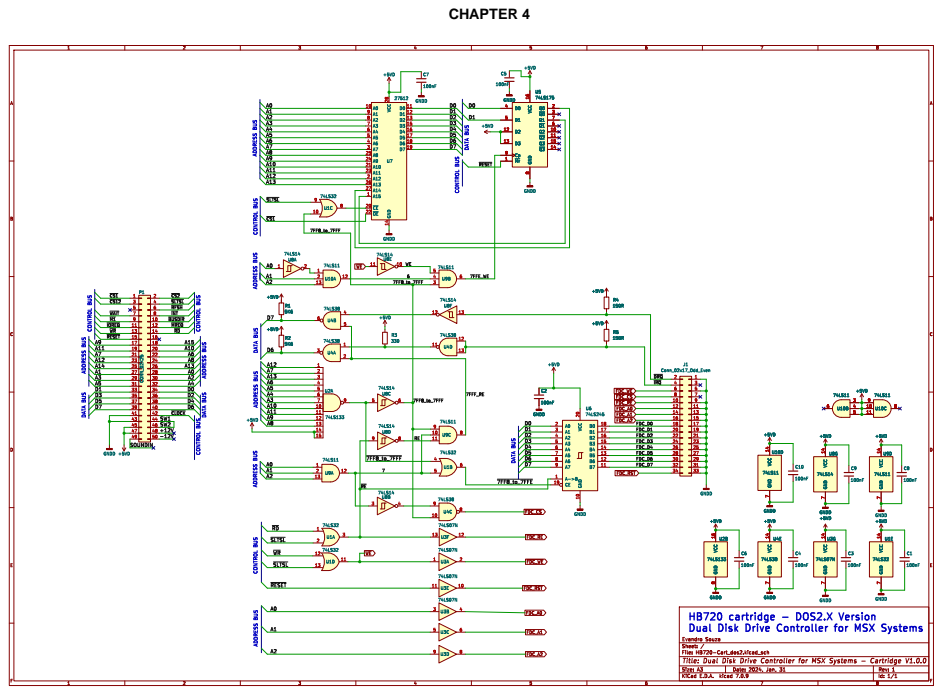
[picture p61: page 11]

## CHAPTER 4

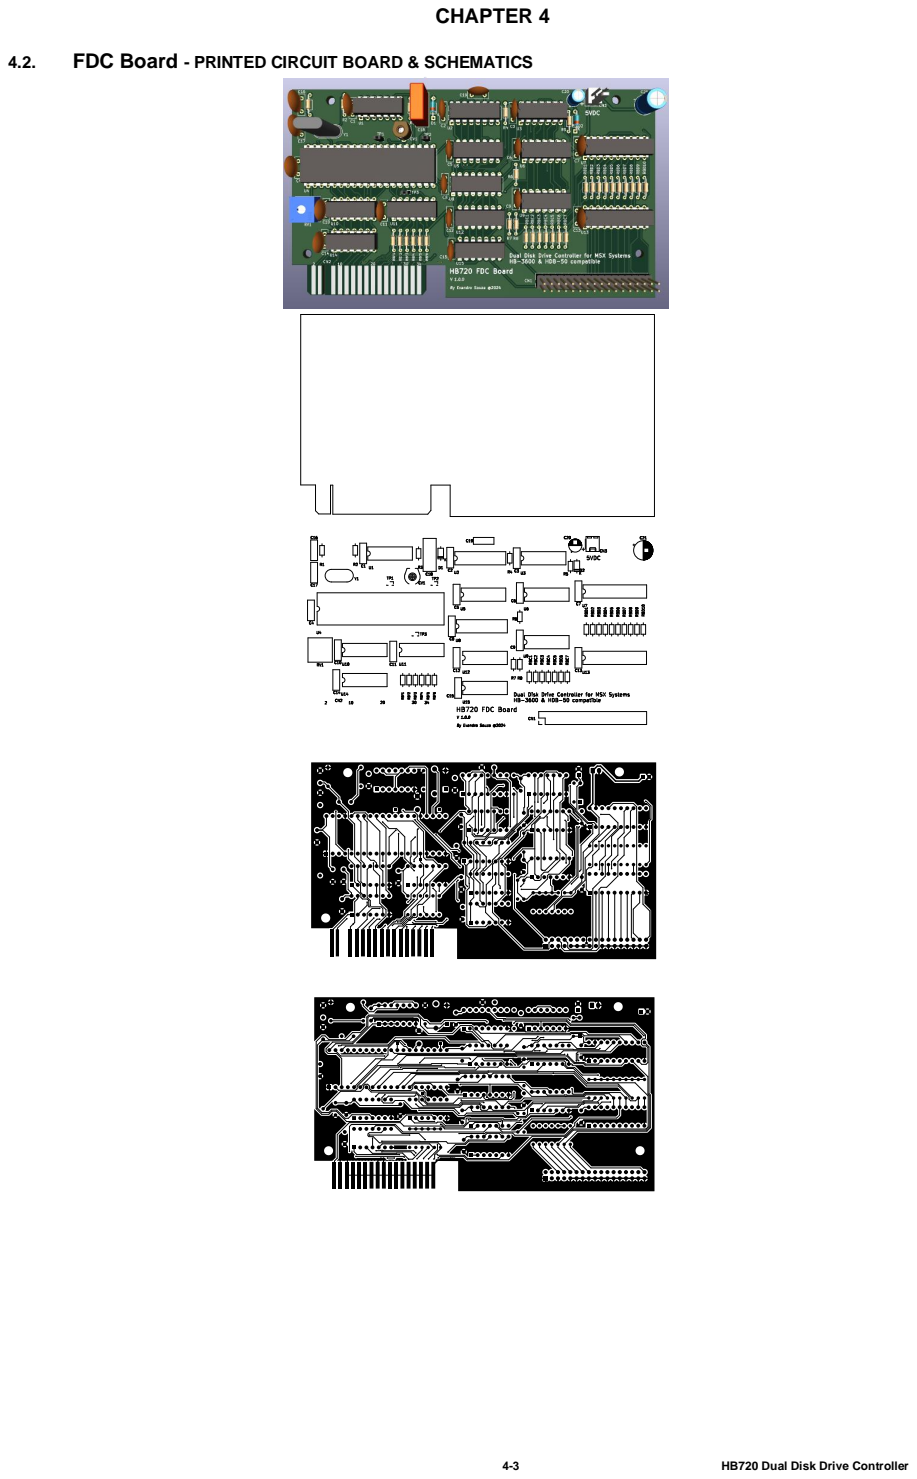
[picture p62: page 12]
HB720 Dual Disk Drive Controller

4.2. FDC Board - PRINTED CIRCUIT BOARD & SCHEMATICS

## CHAPTER 4

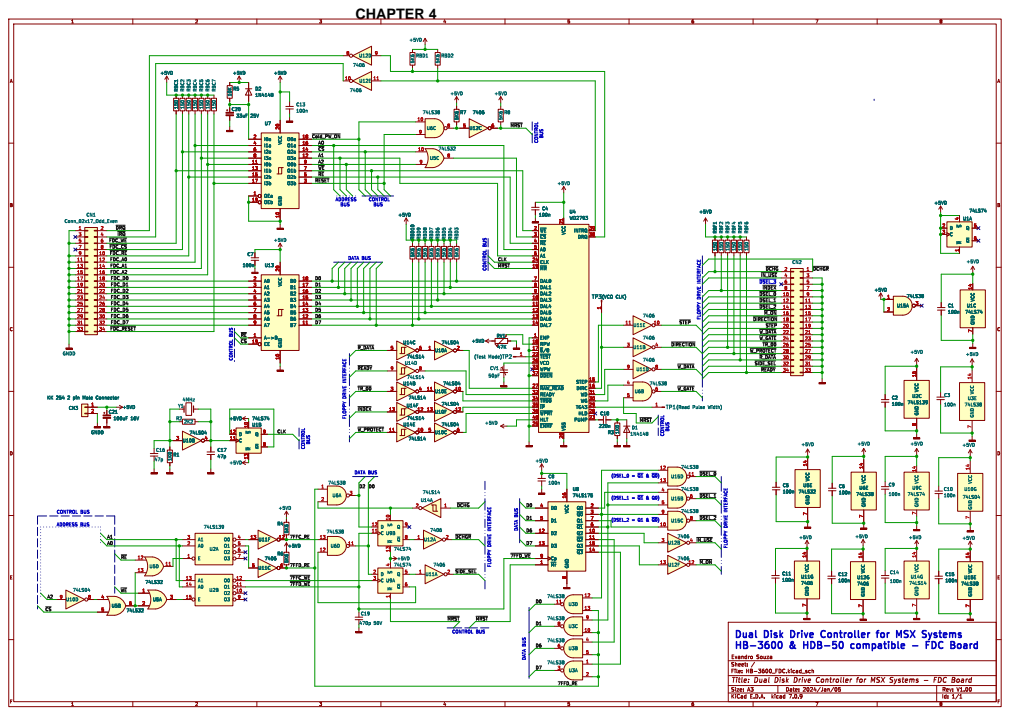
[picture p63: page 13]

5-1 | HB720 Dual Disk Drive Controller

# 5. SEMICONDUCTOR PIN ASSIGNMENTS

MB74LS04 (FUJITSU)
SN74LS04N ^Tl) TTL
INVERTER — TOP VIEW
—

MB74LS14 (FUJITSU)
SN74LS14N (Tl)
TTL SCHMITT TRIGGER INVERTER — TOP VIEW —

M532O6P (MITSUBISHI)
SN74O6N (Tl)
TTL INVERTER BUFFER/DRIVER WITH OPEN-COLLECTOR — TOP VIEW —

SN74O7N (Tl)
TTL BUFFER/DRIVER WITH OPEN-COLLECTOR — TOP VIEW —

SN74LS10N (Tl)
TTL 3-INPUT POSITIVE NAND GATE — TOP VIEW —

0; LOW LEVEL
UHIGH LEVEL

Y = A

HO;LOW LEVEL

1 ; HIGH LEVEL
*;OPEN COLLECTOR

Y = A

0 LOW LEVEL
1 ; HIGH LEVEL
* ; OPEN COLLECTOR

MB74LS32 (FUJITSU)
SN74LS32N (Tl)

TTL 2-INPUT POSITIVE-OR GATE — TOP VIEW —

MB74LS38 (FUJITSU)
SN7438N (Tl)
SN74LS38N (Tl)
TTL 2-INPUT POSITIVE-NAND GATE BUFFER WITH OPEN-COLLECTOR — TOP VIEW —

MB74LS74A (FUJITSU)
SN74LS74AN (Tl)
TTL D-TYPE FLIP FLOP WITH DIRECT SET/RESET — TOP VIEW —

[w] F?] [7;] H [ipl M lei

------- | »V IN
SN7414N ......0.9 1.7 V
SN74LS14N--0.8 1.6V

Y=AB=A+B

A _B Y.

0; LOW LEVEL
_L£ ± 1 ; HIGH LEVEL
1 H l°l * ; OPEN COLLECTOR

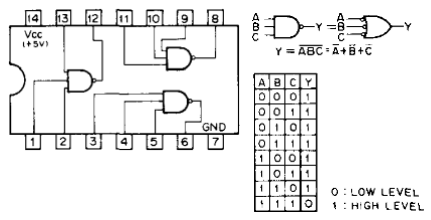
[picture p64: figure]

INPUTS | OUTPUTS
S | RolC | D | Qn+1 | Qn+1
0 | 1 | x | x | 1 | 0
1 | 0 | X | X | 0 | 1
0 | 0 | X | X | 1 * | 1 *
1 | 1 | | 1 | 1 | 0
1 | 1 | J - | 0 | 0
1 | 1 | 0 | X | On | On
0;L0W LEVEL 1 ;
HIGH LEVEL X;
DON’T CARE 1*;
NONSTABLE

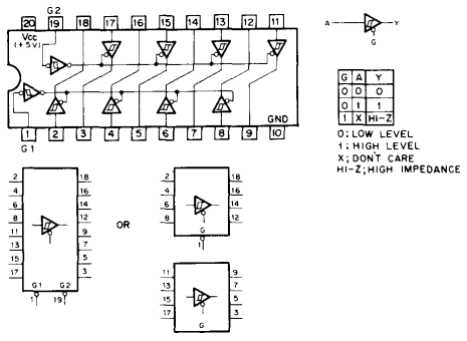
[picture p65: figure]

5-2 | HB720 Dual Disk Drive Controller

SN74ALS133N (Tl)

MB74LS139 (FUJITSU)
SN74LS139N (Tl)
TTL 2-T0-4-LINE DECOOER/DEMULTIPLEXER

— TOP VIEW —

MB74LS1 75 (FUJITSU)
SN74LS175N (Tl)
TTL O-TYPE FLIP-FLOP WITH CLEAR — TOP

VIEW —
MB74LS244 (FUJITSU)
SN74LS244N (Tl)
TTL | 3-STATE | SCHMITT | TRIGGER
BUFFER/DRIVER — TOP VIEW —

MB74LS245 (FUJITSU)
SN74LS245N (Tl)
TTL BILATERAL SCHMITT TRIGGER BUS TRANSCEIVERS WITH 3-STATE OUTPUT — TOP VIEW —

0;LOW LEVEL
1 ; HIGH LEVEL x;
DON’T CARE. Hl-Z,
HIGH IMPEDANCE

TTL 13-INPUT NAND GATE

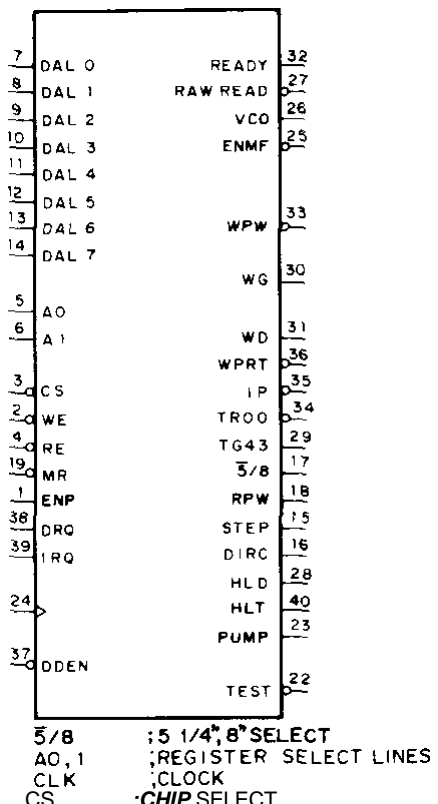
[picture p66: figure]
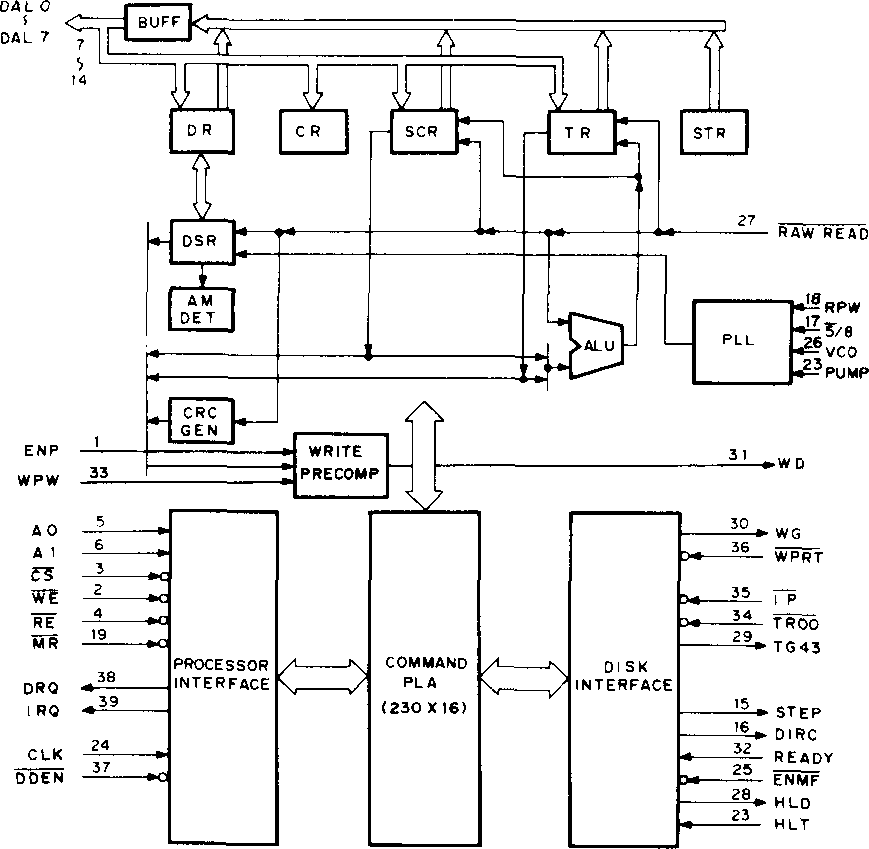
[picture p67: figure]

5-3 | HB720 Dual Disk Drive Controller

HN48271 28G-25 (HITACHI) (ACCESS TIME = 250nS) HN4827128G-30 (HITACHI) (ACCESS TIME = 300nS) HN4827128G-45 (HITACHI) (ACCESS TIME = 450nS) N-MOS ERASABLE AND PROGRAMMABLE ROM 128K-BIT <16384x8) — TOP VIEW —

WD2793-02 (WESTERN DIGITAL)
N CHANNEL E/D MOS FLOPPY DISK FORMATTER/CONTROLLER — TOP VIEW —

E

VPP
VO
D
Al 2 E | PGM
A7 | U | | A13
A6 | [5 | | A 8
AS | | | A 9
A4 | | | Al 1
A3 | E | | OE
A2 | | 21] | A10
Al | [I | g | CE

AO E
| | g | D7
DO Ei | 06
DI | 1 | 13 | D5
D2 | E | 13 | D4
E
GNO | <3 | 03

o ;LOW LEVEL
1 ;HIGH LEVEL x
;DON’T CARE

ENP £

'o'
HLT
WE | E | IRQ
CS | E | 38| DRQ
RE | E | 53 ODEN
AO | E | E) WP RT
Al | E | 35| 7P

DAL
O | □ | TROO
DALI E | WPW
0AL2 E | 3 | READY
DAL3 E | 53 WD
DAL4 E | WG
DALS E | 29] TG43
DAL6 E | 28] HLD
DAL7 E | RAW READ

STEP E
g | VCO
DIRC E | g | ENMF
5/8 | E | 24] CLK

RPW E

g | PUMP
MR | E | 22] TEST
E
GND | Vcc | 23
CS | ;CHIP SELECT
DALO-7 JDATA ACCESS LINES DDEN
| iDOUBLE DENSITY
DIRC | ‘.DIRECTION
DRO | ;DATA REQUEST
ENMF | iENABLE MINI-FLOPPY
ENP | J ENABLE PRECOMP
HLD | » HEAD LOAD
HLT | i HEAD LOAD TIMING
IP | ;INDEX PULSE
IRQ | '.'INTERRUPT REQUEST
MR | i MASTER RESET
RE | । READ ENABLE
RPW | ! READ PULSE WIDTH
TG43 | I TRACK GREATER THAN43
TROO | : TRACK 00
VCO | : VOLTAGE-CONTROLLED OSC
WD | t WRITE DATA
WE | i WRITE ENABLE
WG | ’WRITE GATE
WPRT | 1 WRITE PROTECT
WPW | t WRITE PRECOMP WIDTH

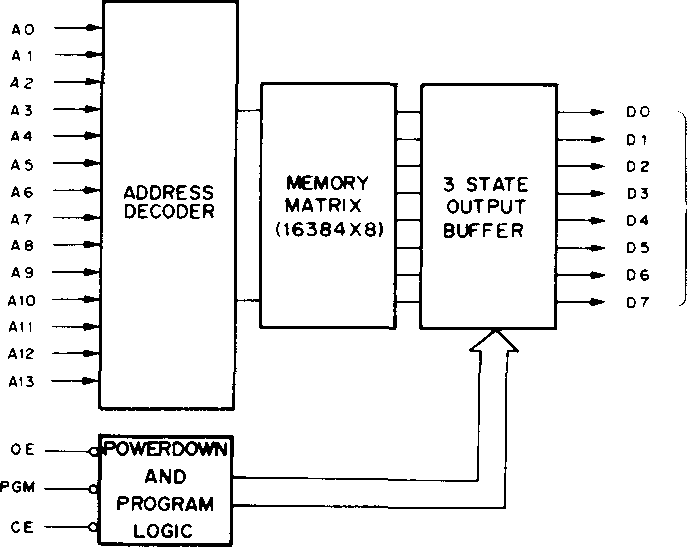
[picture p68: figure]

AO-13 ; ADDRESS INPUT
CE ; CHIP ENABLE DO-7 ;
DATA
OE I OUTPUT ENABLE PGM
; PROGRAM

CR COMMAND REGISTER
DR ;DATA REGISTER DSR
iOATA SHIFT REGISTER SCR
SECTOR REGISTER TR '.TRACK REGISTER STR '.STATUS
REGISTER
CS | A 1 | AO | RE = 0 | WE = 0
1 | X | X | NON | OAL = HI-Z
0 | 0 | 0 | STR | C R
0 | 0 | 1 | TR | TR
0 | 1 | 0 | SCR | SCR
0 | 1 | 1 | DR | OR

REGISTER SELECTION

0 ;LOW LEVEL
1 I HIGH LEVEL X ; DON’T
CARE Hl-Z; HIGH
HB720 | IMPEDANCE

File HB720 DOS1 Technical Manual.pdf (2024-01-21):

# MSX Dual Disk Drive Controller

HB720

# Based on Memory Mapped I/O Registers

# Compatible with:

# EPCOM/SHARP HB-3600


# SONY HBD-50


# Based on MSXHans, 2001 PDF

By Evandro Souza 2024, January.

## 1. OPERATION

1-1.FEATURES | 1-1
1-2.SPECIFICATIONS | 1-1
1-3.PARTS IDENTIFICATION | 1-1
1-3-1Drive Unit | 1-1
1-3-2. Interface Cartridge | 1-1
1-4. CONNECTING THE UNIT | 1-2
1-5. INSERTING A DISK | 1-2
1-6. STARTING UP MSX-DISK BASIC | 1-2
1-7. PIN ASSIGNMENT OF THE CONNECTORS | 1-3

# TABLE OF CONTENTS

## 2. BLOCK DIAGRAM

OVERALL BLOCK DIAGRAM | 2-1

## 3. THEORY OF OPERATION

3-1. HB720 CARTRIDGE |
3-1-1. Memory Map | …
3-1-2. Selection by Cartridge | …
3-1-3. Selection by FDC Controller |
3-2. FDC |
3-2-1. Memory Map Detailed | …
3-2-2. Selection of Individual FDC Registers . |
3-2-3. Operation of Individual Registers | …

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
## 4. SCHEMATIC DIAGRAM AND PRINTED CIRCUIT BOARD

HB720 BOARDS | | 4-1
CARTRIDGE BOARD PCB | 4-1
CARTRIDGE BOARD Schematics. | 4-2
FDC BOARD PCB.. | 4-3
FDC BOARD SCHEMATICS | 4-4

## SEMICONDUCTOR PIN

ASSIGNMENTS | 5-1

5.

# CHAPTER 1


HB720 Dual Disk Drive Controller | 1-1

# OPERATION

## 1-3. PARTS IDENTIFICATION

United kingdom model 240V ac, 50Hz
European model 220 V ac, 50 Hz
Brazilian model 127/220V ac (switch selected) 60 Hz United Kingdom model 25W
European model 24 W
Brazilian model 16W
10oC-35°C (50oF-95°F) 160 x 67 x 260 mm (w/h/d) For the drive unit only, including the projecting parts Interface cartridge : 240 g
Drive unit: 2.7 kg (excludes the disk)
Blank disk (1)
Disk labels (3)

The HBD-50 floppy disk drive unit allows 3 1/2-inch micro floppy disks to be used with an MSX standard computer.
The 3 1/2-inch micro floppy disk is packaged in a hard case provided with a metal disk guard. 360K bytes of data can be recorded on a single disk and the contents can be easily retrieved and rewritten. This floppy disk drive unit will greatly extend the information-handling capabilities of your MSX computer.

### 1-3-1. Drive Unit

## 1-2. SPECIFICATIONS

Interface Section
Interface specifications
Internal ROM

Power consumption

Fits to MSX slots
16K bytes
Standard I/O routines
Standard DOS routines
MSX-Disk BASIC Utility routines

+ 5 V, 300 mA or less

Drive Section
Disk used
Disk type
Recording capacity

5¼” and 3

1
/2" floppy disk
Single and Double-sided
Formatted : 360K / 720K bytes Bytes/sector: 512
Sectors/track : 9
Tracks/cylinder: 2
Tracks/disk: 80
Bytes/disk : 360K / 720K
40 / 80 cylinders
40 / 80 / 160 tracks
MFM (Modified-Frequency Modulation) 300 rpm
250 K bits/sec
100 msec
Average : 350 msec
Between tracks : 12 msec
Settling time : 30 msec
WD2793-02

Total no. of cylinders
Total no. of tracks
Recording method
Disk rotation speed
Data transfer rate
Average latency time
Access time

Controller

## 1-1. FEATURES

General
Power requirements

Power consumption

### 1-3-2. Interface Cartridge

Interface cartridge

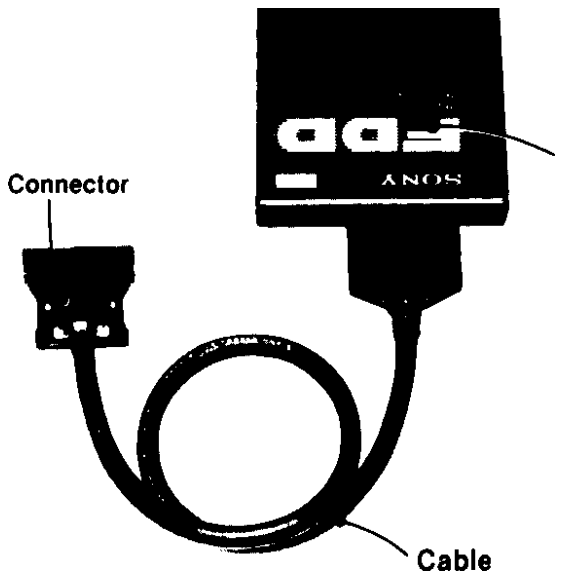
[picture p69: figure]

This cartridge contains MSX-Disk BASIC on ROM and is inserted into the cartridge slot of the computer.

Operating temperature
Dimensions
Weight

Accessories


1-2 | HB720 Dual Disk Drive Controller

## 1-6. STARTING UP MSX-DISK BASIC

Notes on connection
Set the POWER switch of the device to be connected to OFF. Connecting the device while its power is ON may damage the internal circuitry. eWhen disconnecting the connector or cartridge, be sure to take hold of the plug or the cartridge. Pulling on the cord may break the wires.
•As a safety precaution, do not connect the power cord until all other connections have been completed.

MSX-Disk BASIC is stored in ROM (read-only memory) within the interface cartridge of HBD-50.
When the interface cartridge is inserted into the cartridge slot of the computer, Disk BASIC is started up by simply switching on the power of the disk drive unit and the computer.
1 | Insert the interface cartridge.
2 | Set the POWER switch of HBD-50 to ON.
3 | Set the POWER switch of the computer to ON.
| When Disk-BASIC begins operating, the following message is displayed
| on the screen :
4 | Enter the year, month, and date using two digits per entry (and connecting each entry by a hyphen) or simply press the [RETURN| key¹ ). When the [RETURN] key is pressed, the screen will display the following message which indicates the Disk-BASIC has “signed on”.

Precautions
Be sure to switch on the power of the drive unit before that of the computer. If the computer has been turned on first, either press the RESET button of the computer or set the POWER switch of the computer to OFF, then to ON.

## 1-5. INSERTING A DISK

Without opening the metal disk guard, insert the floppydisk and gently push it in until you hear a click.

1) With MSX Disk-BASIC, date data set in this situation is not used.


Removing the disk

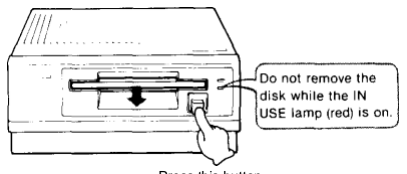
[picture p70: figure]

Press this button.

## 1-4. CONNECTING THE UNIT

HB720 Dual Disk Drive Controller | 1-3

# 1-7. PIN ASSIGNMENT OF THE CONNECTORS

Pin Assignment of the Connectors

HB720 CARTRIDGE TO FDC: IDC 34 pins connector (BOTH SIDES)

33 31 29 27 25 23 21 19 17 15 13 11 9 7 5 3 1

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

34 32 30 28 26 24 22 20 18 16 14 12 10 8 6 4 2

HB720 FDC TO EXT FLOPPPY DRIVE – Edge card connector (34 pins)
- The pinout are the same for 5 ¼” and 3 ½” drives and the cable may have both options:
- To use with 5 ¼”, the connector is a card edge;
- To use with 3 ½” the connector is a 34 pin female IDC.

33 31 29 27 25 23 21 19 17 15 13 11 9 7 5 3 1

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

34 32 30 28 26 24 22 20 18 16 14 12 10 8 6 4 2

Pi n No. | Si gnal | Pi n No. | Si gnal | Pi n No. | Si gnal | Pi n No. | Si gnal
1 | GNDD (RET URN) | 10 | FDC_RE | 19 | GNDD (RET URN) | 28 | FDC_D5
2 | DRQ | 11 | GNDD (RET URN) | 20 | FDC_D1 | 29 | GNDD (RET URN)
3 | N.C. | 12 | FDC_A0 | 21 | GNDD (RET URN) | 30 | FDC_D6
4 | IRQ | 13 | GNDD (RET URN) | 22 | FDC_D2 | 31 | GNDD (RET URN)
5 | GNDD (RET URN) | 14 | FDC_A1 | 23 | GNDD (RET URN) | 32 | FDC_D7
6 | FDC_WE | 15 | GNDD (RET URN) | 24 | FDC_D3 | 33 | GNDD (RET URN)
7 | N.C. | 16 | FDC_A2 | 25 | GNDD (RET URN) | 34 | RESET
8 | FDC_CS | 17 | GNDD (RET URN) | 26 | FDC_D4
9 | GNDD (RET URN) | 18 | FDC_D0 | 27 | GNDD (RET URN)
Pi n No. | Si gnal | Pi n No. | Si gnal | Pi n No. | Si gnal | Pi n No. | Si gnal
1 | DISK CHANGE RESET | 10 | DRIVE SELECT 0 | 19 | GNDD (RET URN) | 28 | WRIT E PROT ECT
2 | DISK CHANGE | 11 | GNDD (RET URN) | 20 | ST EP | 29 | GNDD (RET URN)
3 | GNDD (RET URN) | 12 | DRIVE SELECT 1 | 21 | GNDD (RET URN) | 30 | READ DAT A
4 | IN USE | 13 | GNDD (RET URN) | 22 | WRIT E DAT A | 31 | GNDD (RET URN)
5 | GNDD (RET URN) | 14 | DRIVE SELECT 2 | 23 | GNDD (RET URN) | 32 | (HEAD SELECT )
6 | DRIVE SELECT 3 | 15 | GNDD (RET URN) | 24 | WRIT E GAT E | 33 | GNDD (RET URN)
7 | GNDD (RET URN) | 16 | M OT OR ON | 25 | GNDD (RET URN) | 34 | READY
8 | INDEX | 17 | GNDD (RET URN) | 26 | T RACK 00 | None | NONE
9 | GNDD (RET URN) | 18 | DIRECT ION | 27 | GNDD (RET URN) | None | NONE

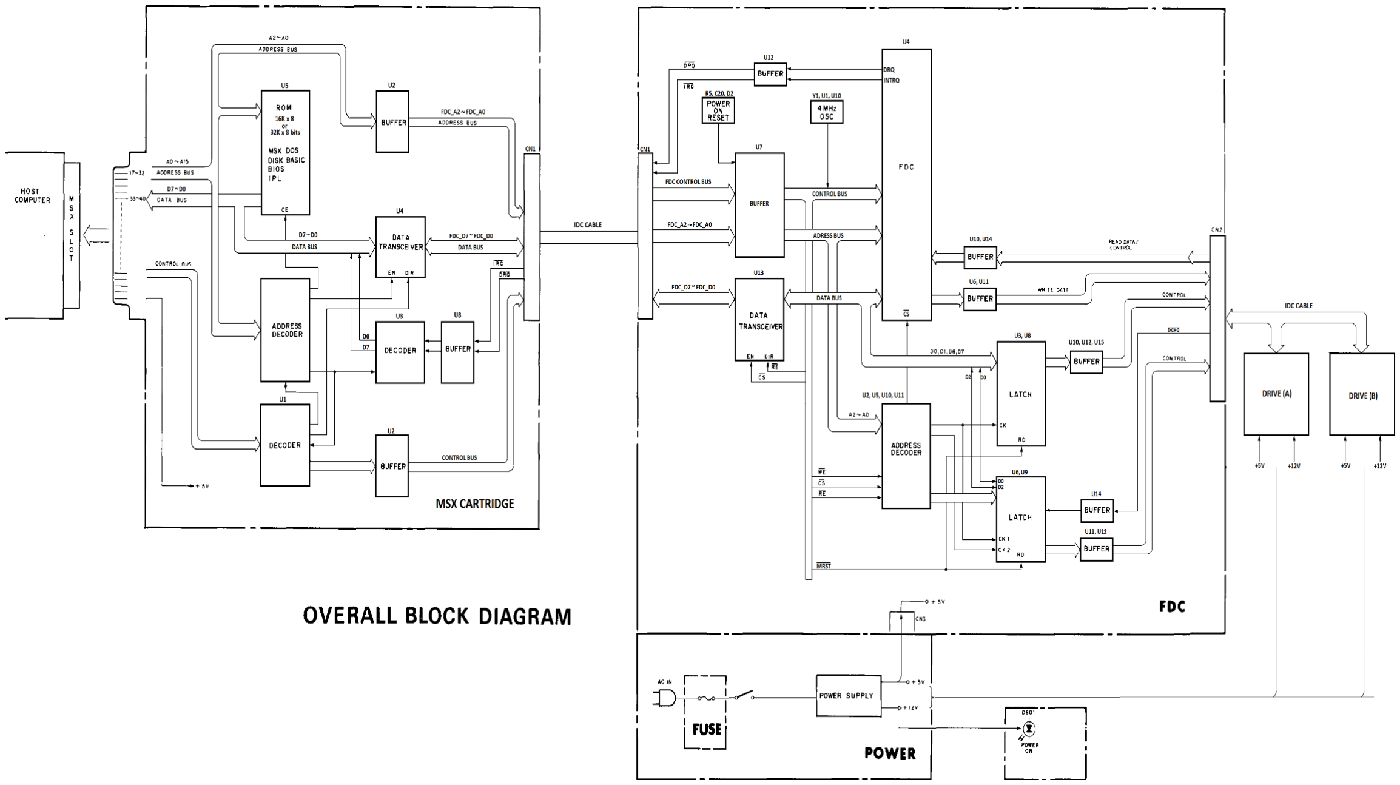
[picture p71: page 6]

# THEORY OF OPERATION

# 2-1. Cartridge Board

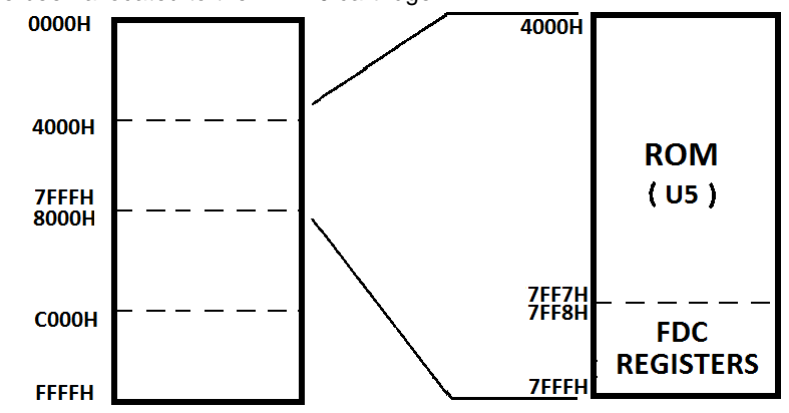
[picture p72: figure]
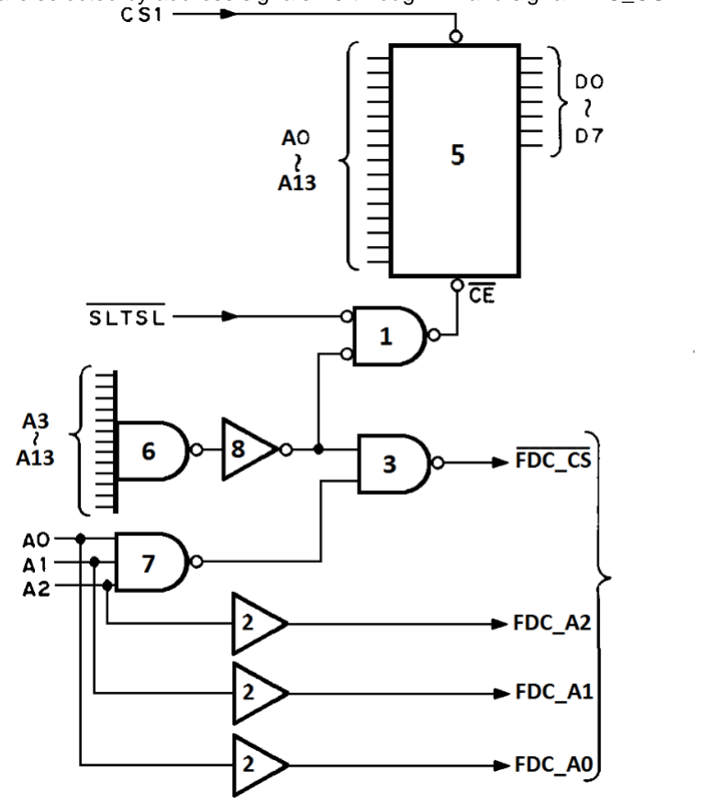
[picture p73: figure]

3-1 | HB720

# 3. THEORY OF OPERATION

# 3-1-1. Memory Map

This board cartridge uses the MSX computer cartridge slot. Addresses 4000H through 7FFFH on the memory map have been allocated to the HB720 cartridge.

# 3-1-2. Selection by HB720 Cartridge

When the HB720 cartridge has been inserted into the MSX computer cartridge slot, addresses 4000H through 7FFFH will be selected by the cartridge connector signal CS1. In addition, U1 will AND signal SLTSL and the U6 (address decoder) output that has been inverted by U8, and will provide an output to U5 (ROM) pin CE for selection of the ROM.

# 3-1-3. Selection by FDC Controller

Individual registers of the FDC board have been allocated to the memory space for addresses 7FF8H through 7FFFH, and are selected by address signals A0 through A2 and signal FDC_CS.

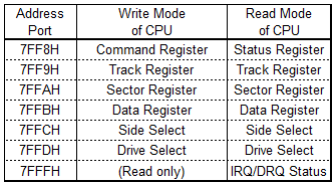
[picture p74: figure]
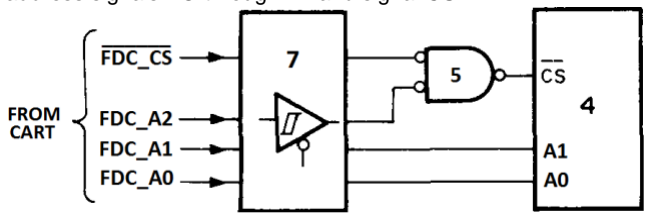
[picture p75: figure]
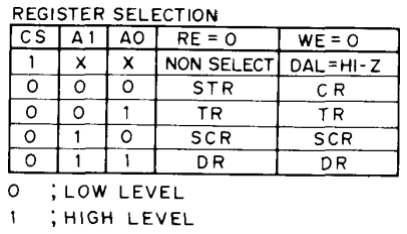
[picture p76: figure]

3-2 | HB720

# 3-2. FDC Board

# 3-2-1. Memory Map of Control Ports in detail

# 3-2-2. Selection of Individual FDC chip Registers

Individual registers of the FDC (U4) have been allocated to addresses 7FF8H through 7FFBH, and are selected by address signals AO through A2 and signal CS.

### CR (COMMAND REGISTER DR (DATA REGISTER DSR (DATA SHIFT REGISTER SCR (SECTOR REGISTER TR (TRACK REGISTER STR (STATUS REGISTER

## Hl-Z (HIGH IMPEDANCE)

# 3-2-3. Operation of Individual Registers

# - Command Register (CR) - 7FF8H

This is an 8-bit write register, where the commands that correspond to the WD2793-02 operation will be written from the processor.
With the exception of a forced interrupt command, the command writing operation takes place after completion of the previous WD2793-02 command.

# - Status Register (STR) - 7FF8H

This is an 8-bit read register. This register indicates the WD2793-02 internal status, the command execution processed status, and the disk drive status. The significance of individual bits will vary depending on whether the command is being executed or the command execution has already been concluded.

# - Track Register (TR) - 7FF9H

This is an 8-bit read/write register. The low-high transition of MR (master reset) will set TR at FFH. When TR00 becomes low, TR will be made 00H.
The track number at which the head is located will usually be set in this register. At WD2793-02, this

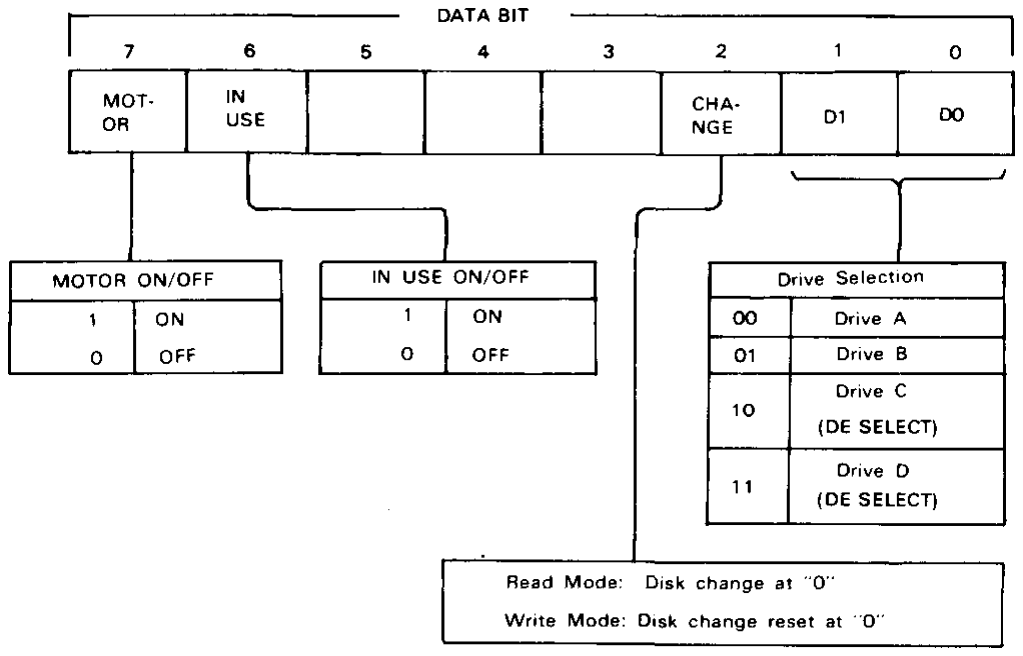
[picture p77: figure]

3-3 | HB720

value may either be updated or not, depending on the command. In the case of a read data command or a write data command, the contents of this register will be compared with an ID field track number read of the disk, and when they coincide with each other, the read or write operation will duly be carried out.

# - Sector Register (SCR) - 7FFAH

This is an 8-bit read/write register. In the case of a read data command or a write data command, the contents of this register will be compared with an ID field track number read of the disk, and when they coincide with each other, the read or write operation will duly be carried out.
When under a read address command, the ID field track number will be retained intact.

# - Data Register (DR) - 7FFBH

This is a read/write register. In a disk reading mode, the data read of the disk will be loaded into this register. In a disk writing mode, the data that has been written earlier into this register will be written into the disk. In a seek mode, the target track address will be written this register.

# - Side Select - 7FFCH

At "0", side 0 will be selected, and at "1", side 1 will be selected

# - Drive Select - 7FFDH

# - IRQ/DRQ Status - 7FFFH

IRQ will be made "0" when the completion of a command has been either concluded or terminated during process.
DRQ will be made "0" when the data write/read are being requested.

# CHAPTER 4

# 4. HB720 Boards

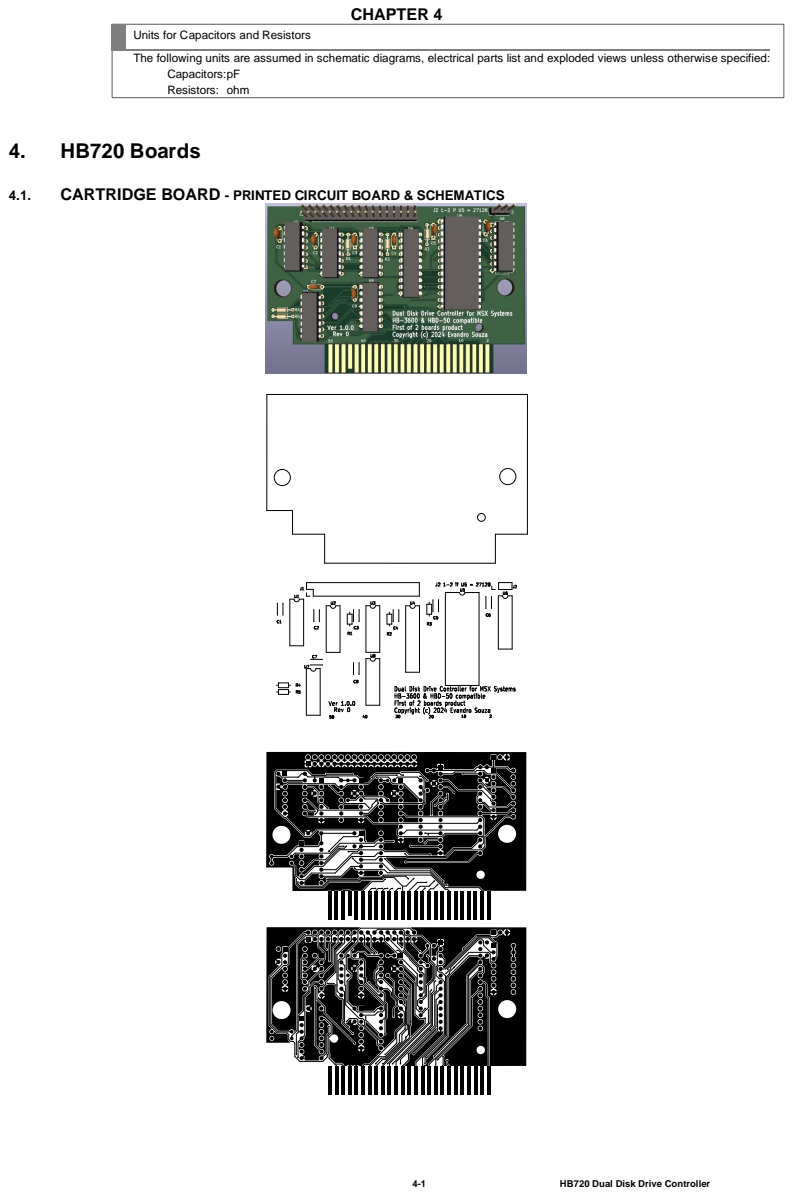
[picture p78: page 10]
HB720 Dual Disk Drive Controller; Capacitors:pF Resistors: ohm

Units for Capacitors and Resistors

The following units are assumed in schematic diagrams, electrical parts list and exploded views unless otherwise specified:

4.1. CARTRIDGE BOARD - PRINTED CIRCUIT BOARD & SCHEMATICS

# CHAPTER 4

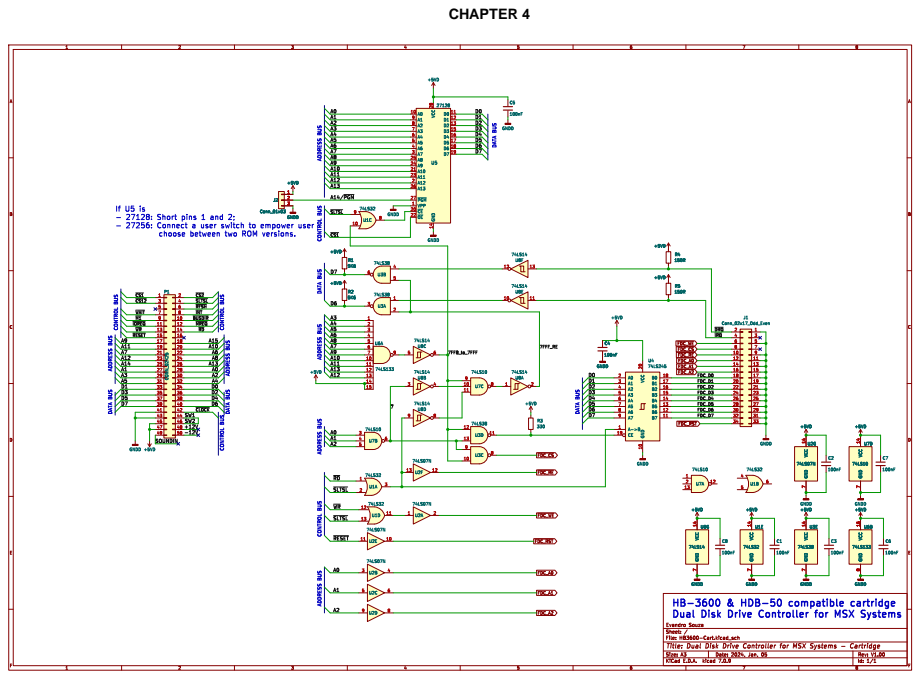
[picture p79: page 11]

# 4.2. FDC Board - PRINTED CIRCUIT BOARD & SCHEMATICS

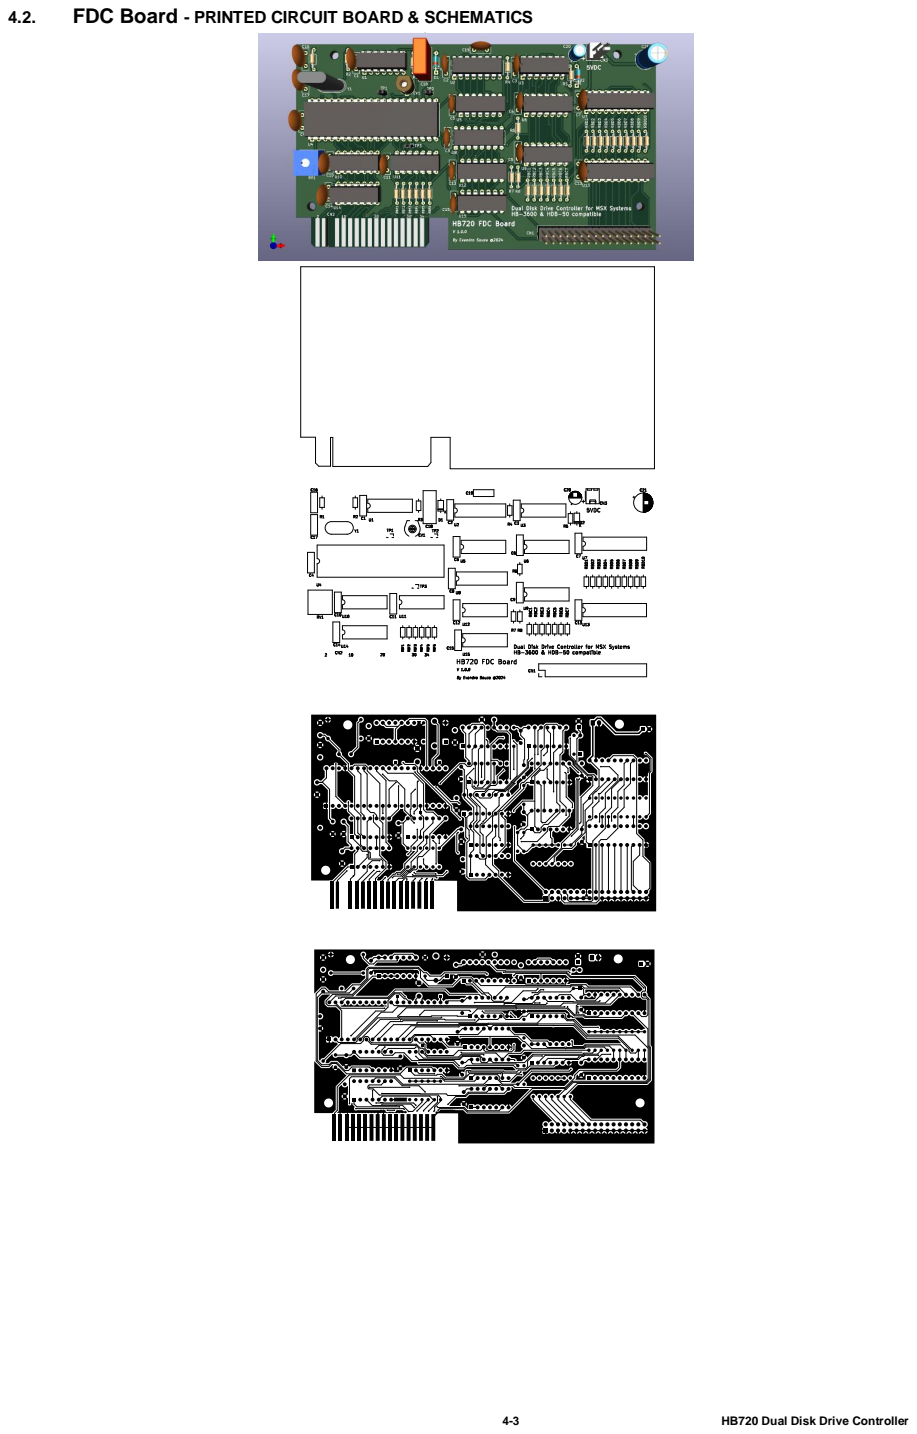
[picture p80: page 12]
HB720 Dual Disk Drive Controller

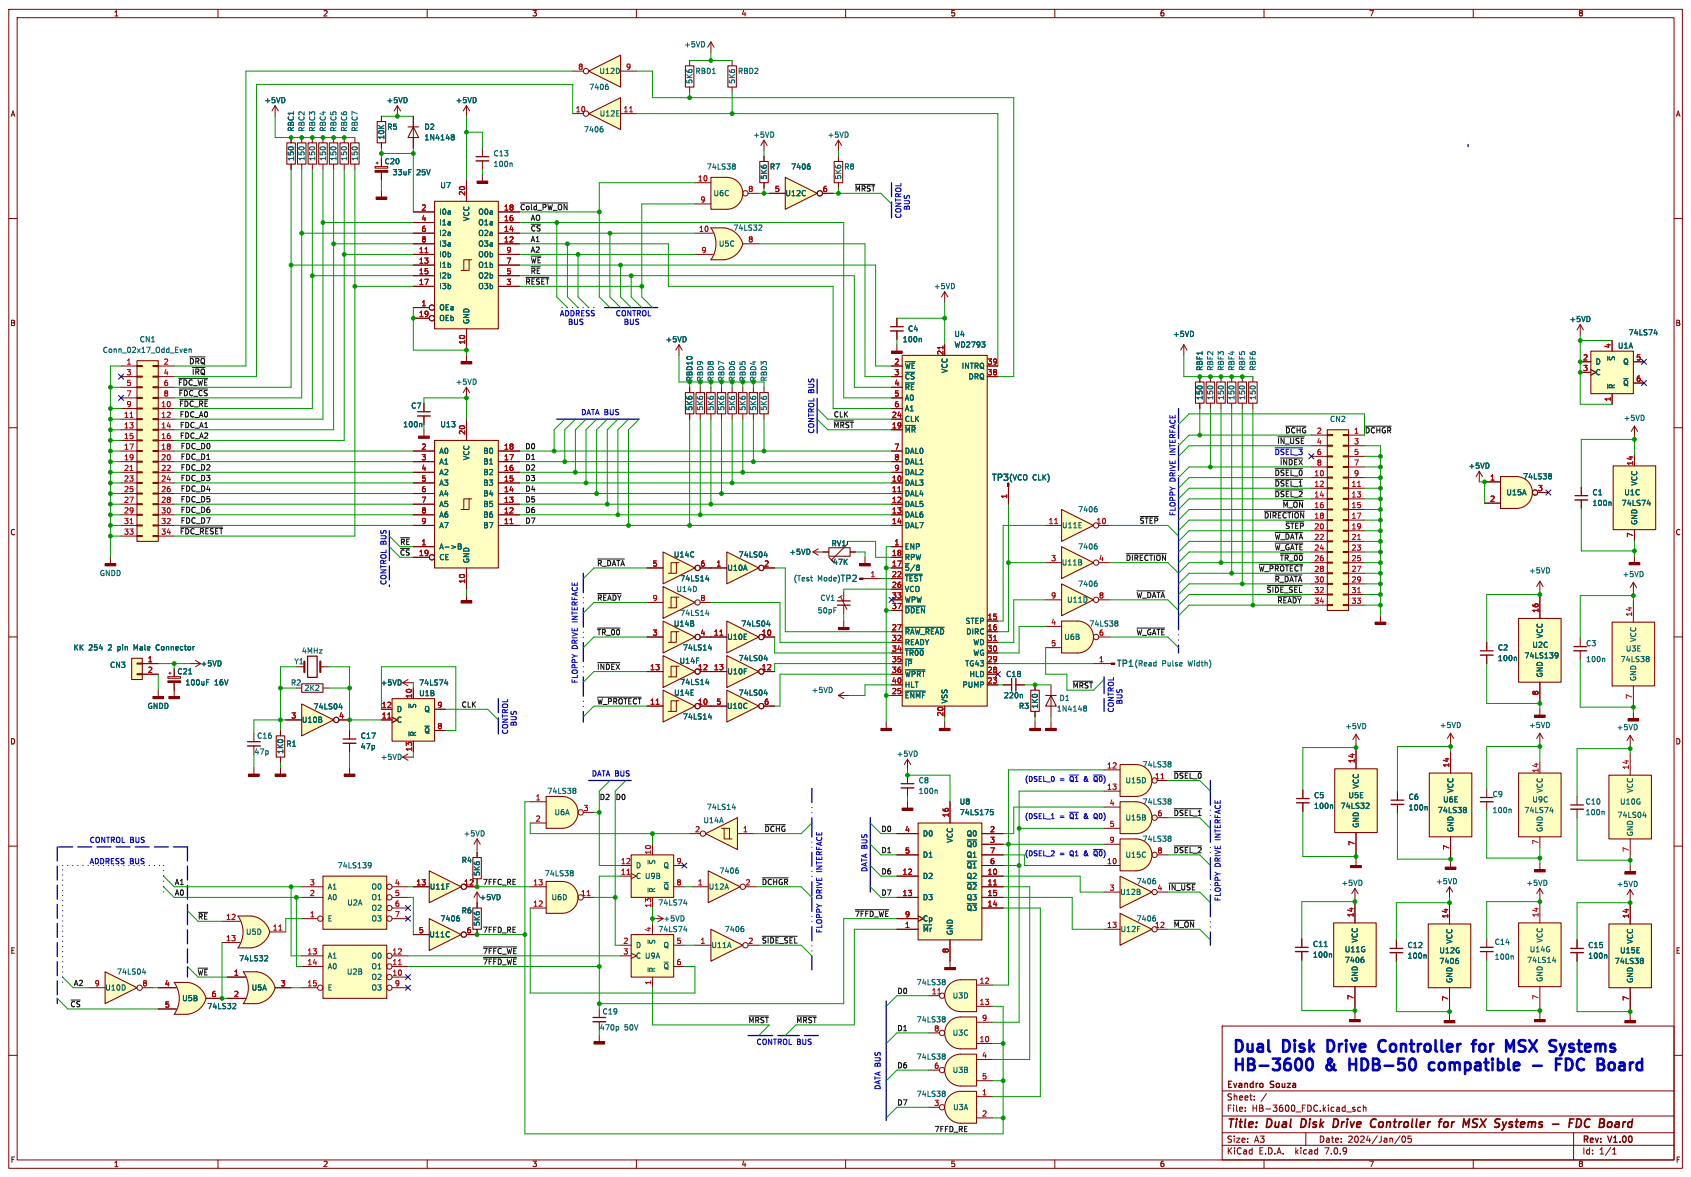
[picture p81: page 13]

5-1 | HB720 Dual Disk Drive Controller

# 5. SEMICONDUCTOR PIN ASSIGNMENTS

MB74LS04 (FUJITSU)
SN74LS04N ^Tl) TTL
INVERTER — TOP VIEW
—

MB74LS14 (FUJITSU)
SN74LS14N (Tl)
TTL SCHMITT TRIGGER INVERTER — TOP VIEW —

M532O6P (MITSUBISHI)
SN74O6N (Tl)
TTL INVERTER BUFFER/DRIVER WITH OPEN-COLLECTOR — TOP VIEW —

SN74O7N (Tl)
TTL BUFFER/DRIVER WITH OPEN-COLLECTOR — TOP VIEW —

SN74LS10N (Tl)
TTL 3-INPUT POSITIVE NAND GATE — TOP VIEW —

0; LOW LEVEL
UHIGH LEVEL

Y = A

HO;LOW LEVEL

1 ; HIGH LEVEL
*;OPEN COLLECTOR

Y = A

0 LOW LEVEL
1 ; HIGH LEVEL
* ; OPEN COLLECTOR

MB74LS32 (FUJITSU)
SN74LS32N (Tl)

TTL 2-INPUT POSITIVE-OR GATE — TOP VIEW —

MB74LS38 (FUJITSU)
SN7438N (Tl)
SN74LS38N (Tl)
TTL 2-INPUT POSITIVE-NAND GATE BUFFER WITH OPEN-COLLECTOR — TOP VIEW —

MB74LS74A (FUJITSU)
SN74LS74AN (Tl)
TTL D-TYPE FLIP FLOP WITH DIRECT SET/RESET — TOP VIEW —

[w] F?] [7;] H [ipl M lei

------- | »V IN
SN7414N ......0.9 1.7 V
SN74LS14N--0.8 1.6V

Y=AB=A+B

A _B Y.

0; LOW LEVEL
_L£ ± 1 ; HIGH LEVEL
1 H l°l * ; OPEN COLLECTOR
INPUTS | OUTPUTS
S | RolC | D | Qn+1 | Qn+1
0 | 1 | x | x | 1 | 0
1 | 0 | X | X | 0 | 1
0 | 0 | X | X | 1 * | 1 *
1 | 1 | | 1 | 1 | 0
1 | 1 | J - | 0 | 0
1 | 1 | 0 | X | On | On
0;L0W LEVEL 1 ;
HIGH LEVEL X;
DON’T CARE 1*;
NONSTABLE


5-2 | HB720 Dual Disk Drive Controller

SN74ALS133N (Tl)

MB74LS139 (FUJITSU)
SN74LS139N (Tl)
TTL 2-T0-4-LINE DECOOER/DEMULTIPLEXER

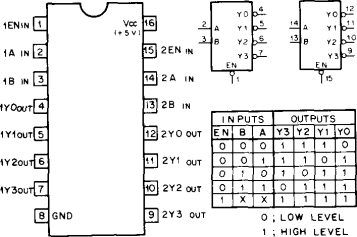
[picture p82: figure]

— TOP VIEW —

MB74LS1 75 (FUJITSU)
SN74LS175N (Tl)
TTL O-TYPE FLIP-FLOP WITH CLEAR — TOP

VIEW —
MB74LS244 (FUJITSU)
SN74LS244N (Tl)
TTL | 3-STATE | SCHMITT | TRIGGER
BUFFER/DRIVER — TOP VIEW —

MB74LS245 (FUJITSU)
SN74LS245N (Tl)
TTL BILATERAL SCHMITT TRIGGER BUS TRANSCEIVERS WITH 3-STATE OUTPUT — TOP VIEW —

0;LOW LEVEL
1 ; HIGH LEVEL x;
DON’T CARE. Hl-Z,
HIGH IMPEDANCE

TTL 13-INPUT NAND GATE


5-3 | HB720 Dual Disk Drive Controller

HN48271 28G-25 (HITACHI) (ACCESS TIME = 250nS) HN4827128G-30 (HITACHI) (ACCESS TIME = 300nS) HN4827128G-45 (HITACHI) (ACCESS TIME = 450nS) N-MOS ERASABLE AND PROGRAMMABLE ROM 128K-BIT <16384x8) — TOP VIEW —

WD2793-02 (WESTERN DIGITAL)
N CHANNEL E/D MOS FLOPPY DISK FORMATTER/CONTROLLER — TOP VIEW —

E

VPP
VO
D
Al 2 E | PGM
A7 | U | | A13
A6 | [5 | | A 8
AS | | | A 9
A4 | | | Al 1
A3 | E | | OE
A2 | | 21] | A10
Al | [I | g | CE

AO E
| | g | D7
DO Ei | 06
DI | 1 | 13 | D5
D2 | E | 13 | D4
E
GNO | <3 | 03

o ;LOW LEVEL
1 ;HIGH LEVEL x
;DON’T CARE

ENP £

'o'
HLT
WE | E | IRQ
CS | E | 38| DRQ
RE | E | 53 ODEN
AO | E | E) WP RT
Al | E | 35| 7P

DAL
O | □ | TROO
DALI E | WPW
0AL2 E | 3 | READY
DAL3 E | 53 WD
DAL4 E | WG
DALS E | 29] TG43
DAL6 E | 28] HLD
DAL7 E | RAW READ

STEP E
g | VCO
DIRC E | g | ENMF
5/8 | E | 24] CLK

RPW E

g | PUMP
MR | E | 22] TEST
E
GND | Vcc | 23
CS | ;CHIP SELECT
DALO-7 JDATA ACCESS LINES DDEN
| iDOUBLE DENSITY
DIRC | ‘.DIRECTION
DRO | ;DATA REQUEST
ENMF | iENABLE MINI-FLOPPY
ENP | J ENABLE PRECOMP
HLD | » HEAD LOAD
HLT | i HEAD LOAD TIMING
IP | ;INDEX PULSE
IRQ | '.'INTERRUPT REQUEST
MR | i MASTER RESET
RE | । READ ENABLE
RPW | ! READ PULSE WIDTH
TG43 | I TRACK GREATER THAN43
TROO | : TRACK 00
VCO | : VOLTAGE-CONTROLLED OSC
WD | t WRITE DATA
WE | i WRITE ENABLE
WG | ’WRITE GATE
WPRT | 1 WRITE PROTECT
WPW | t WRITE PRECOMP WIDTH


AO-13 ; ADDRESS INPUT
CE ; CHIP ENABLE DO-7 ;
DATA
OE I OUTPUT ENABLE PGM
; PROGRAM

CR COMMAND REGISTER
DR ;DATA REGISTER DSR
iOATA SHIFT REGISTER SCR
SECTOR REGISTER TR '.TRACK REGISTER STR '.STATUS
REGISTER
CS | A 1 | AO | RE = 0 | WE = 0
1 | X | X | NON | OAL = HI-Z
0 | 0 | 0 | STR | C R
0 | 0 | 1 | TR | TR
0 | 1 | 0 | SCR | SCR
0 | 1 | 1 | DR | OR

REGISTER SELECTION

0 ;LOW LEVEL
1 I HIGH LEVEL X ; DON’T
CARE Hl-Z; HIGH
HB720 | IMPEDANCE

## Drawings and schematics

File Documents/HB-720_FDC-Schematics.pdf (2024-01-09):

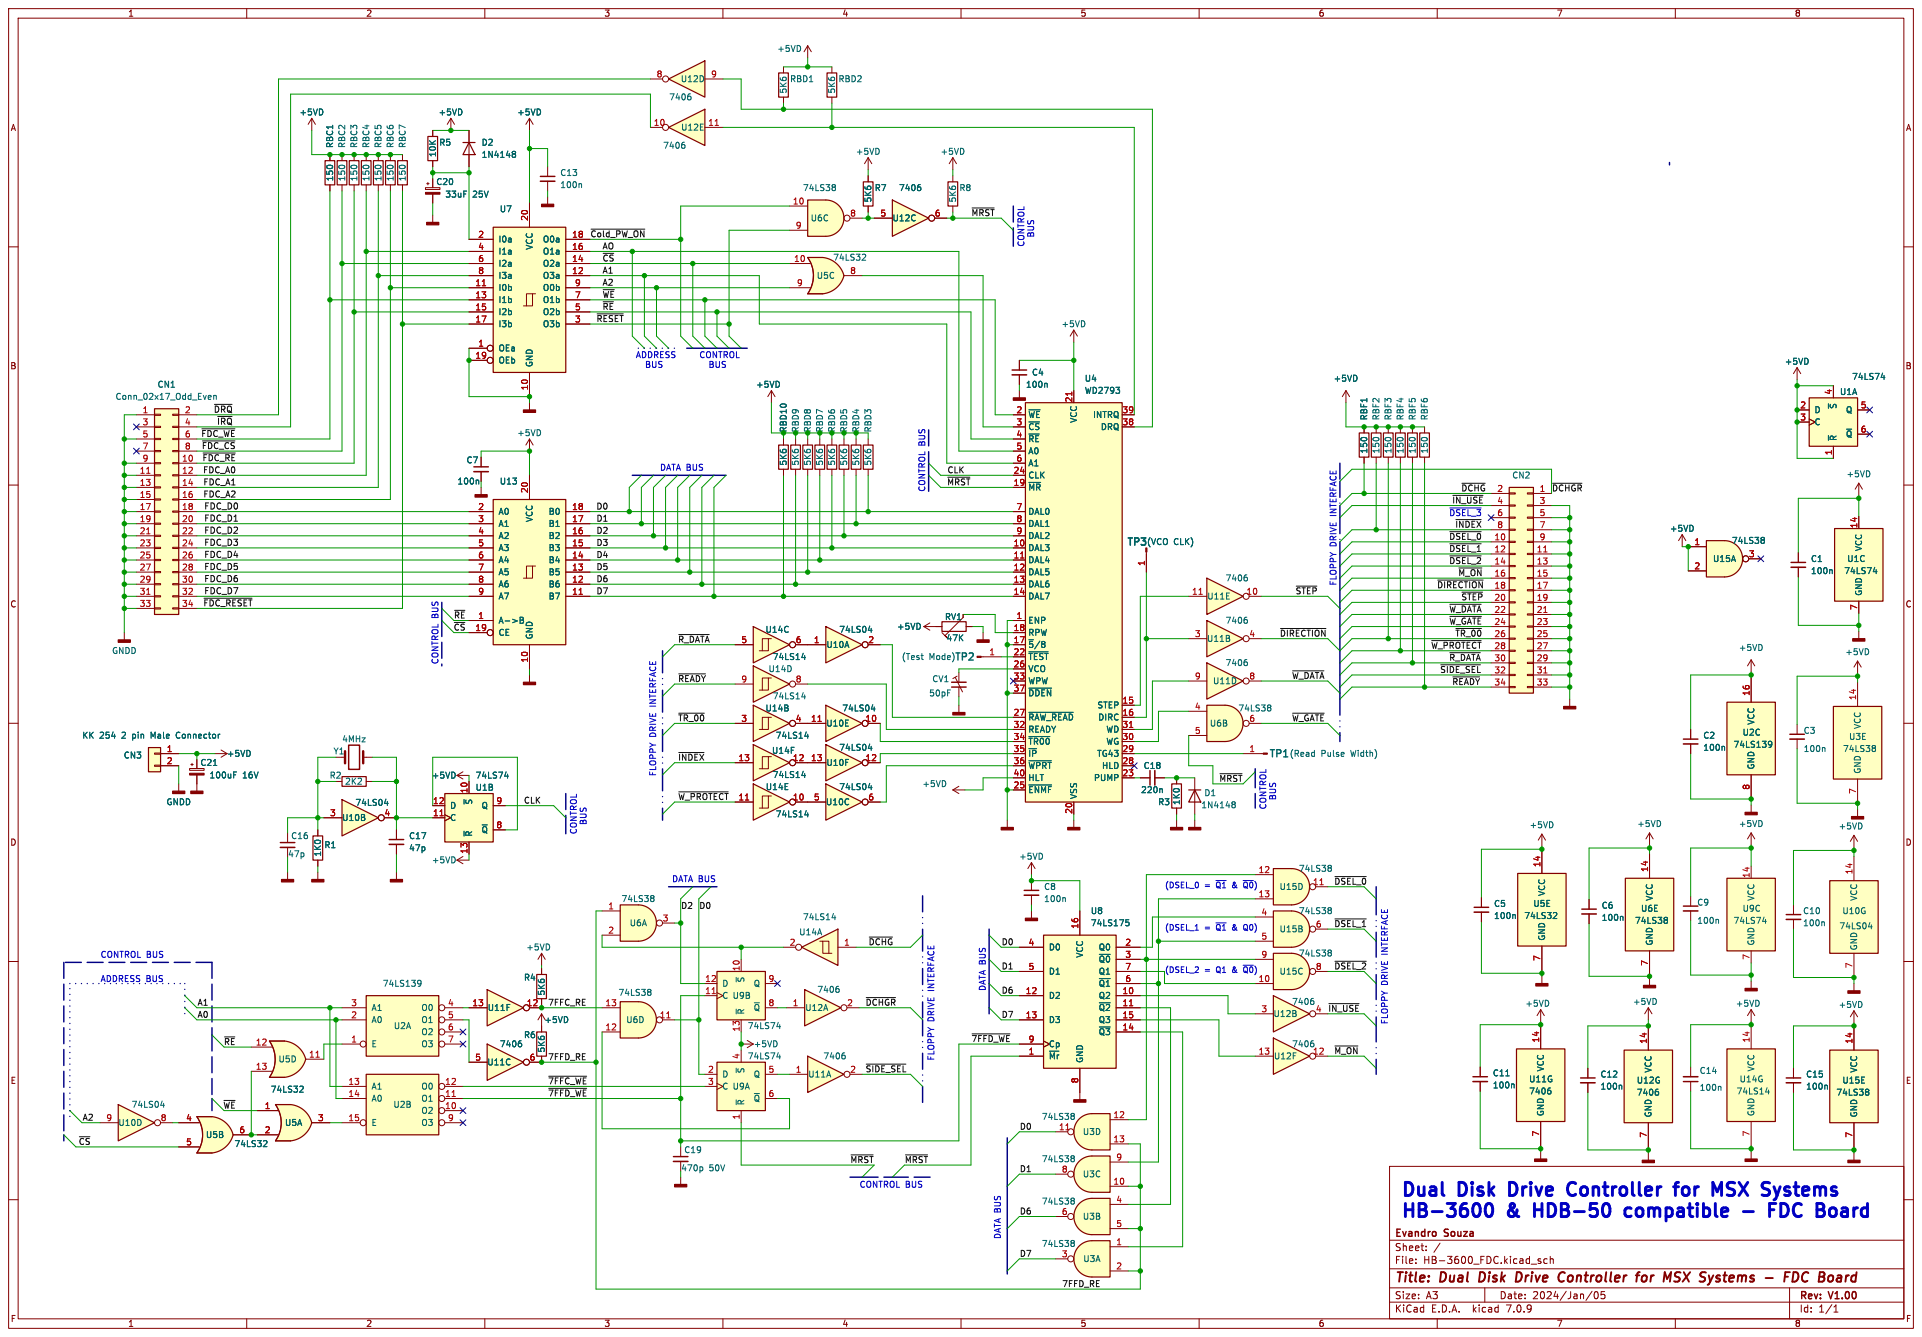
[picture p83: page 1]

Id: 1/1 Title: Dual Disk Drive Controller for MSX Systems - FDC Board

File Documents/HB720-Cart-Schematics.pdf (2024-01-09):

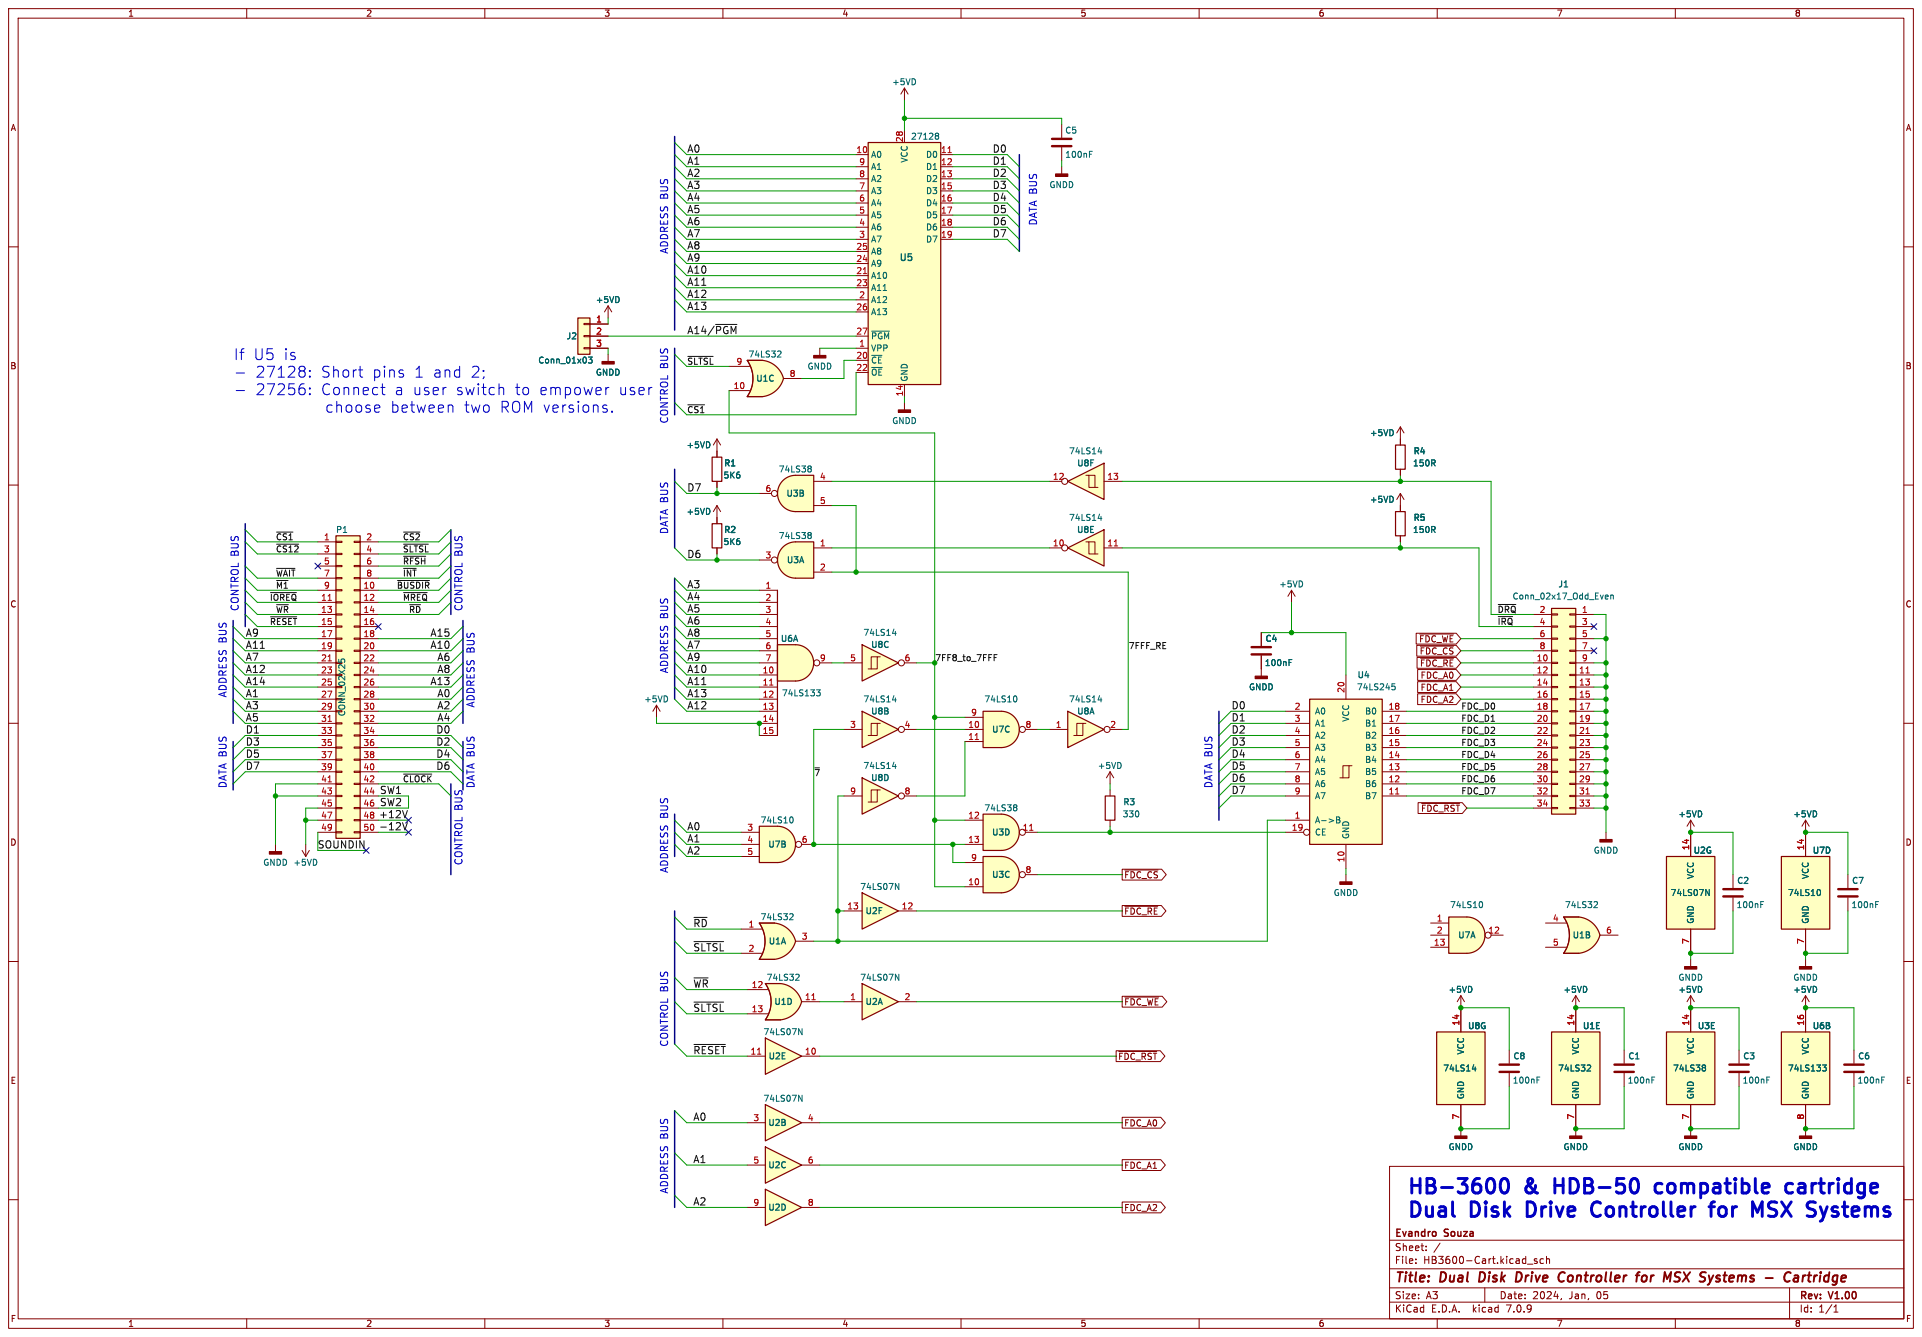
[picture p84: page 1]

- 27128: Short pins 1 and 2; - 27256: Connect a user switch to empower user

7 GNDD GNDD GNDD GNDD

Id: 1/1 Title: Dual Disk Drive Controller for MSX Systems - Cartridge

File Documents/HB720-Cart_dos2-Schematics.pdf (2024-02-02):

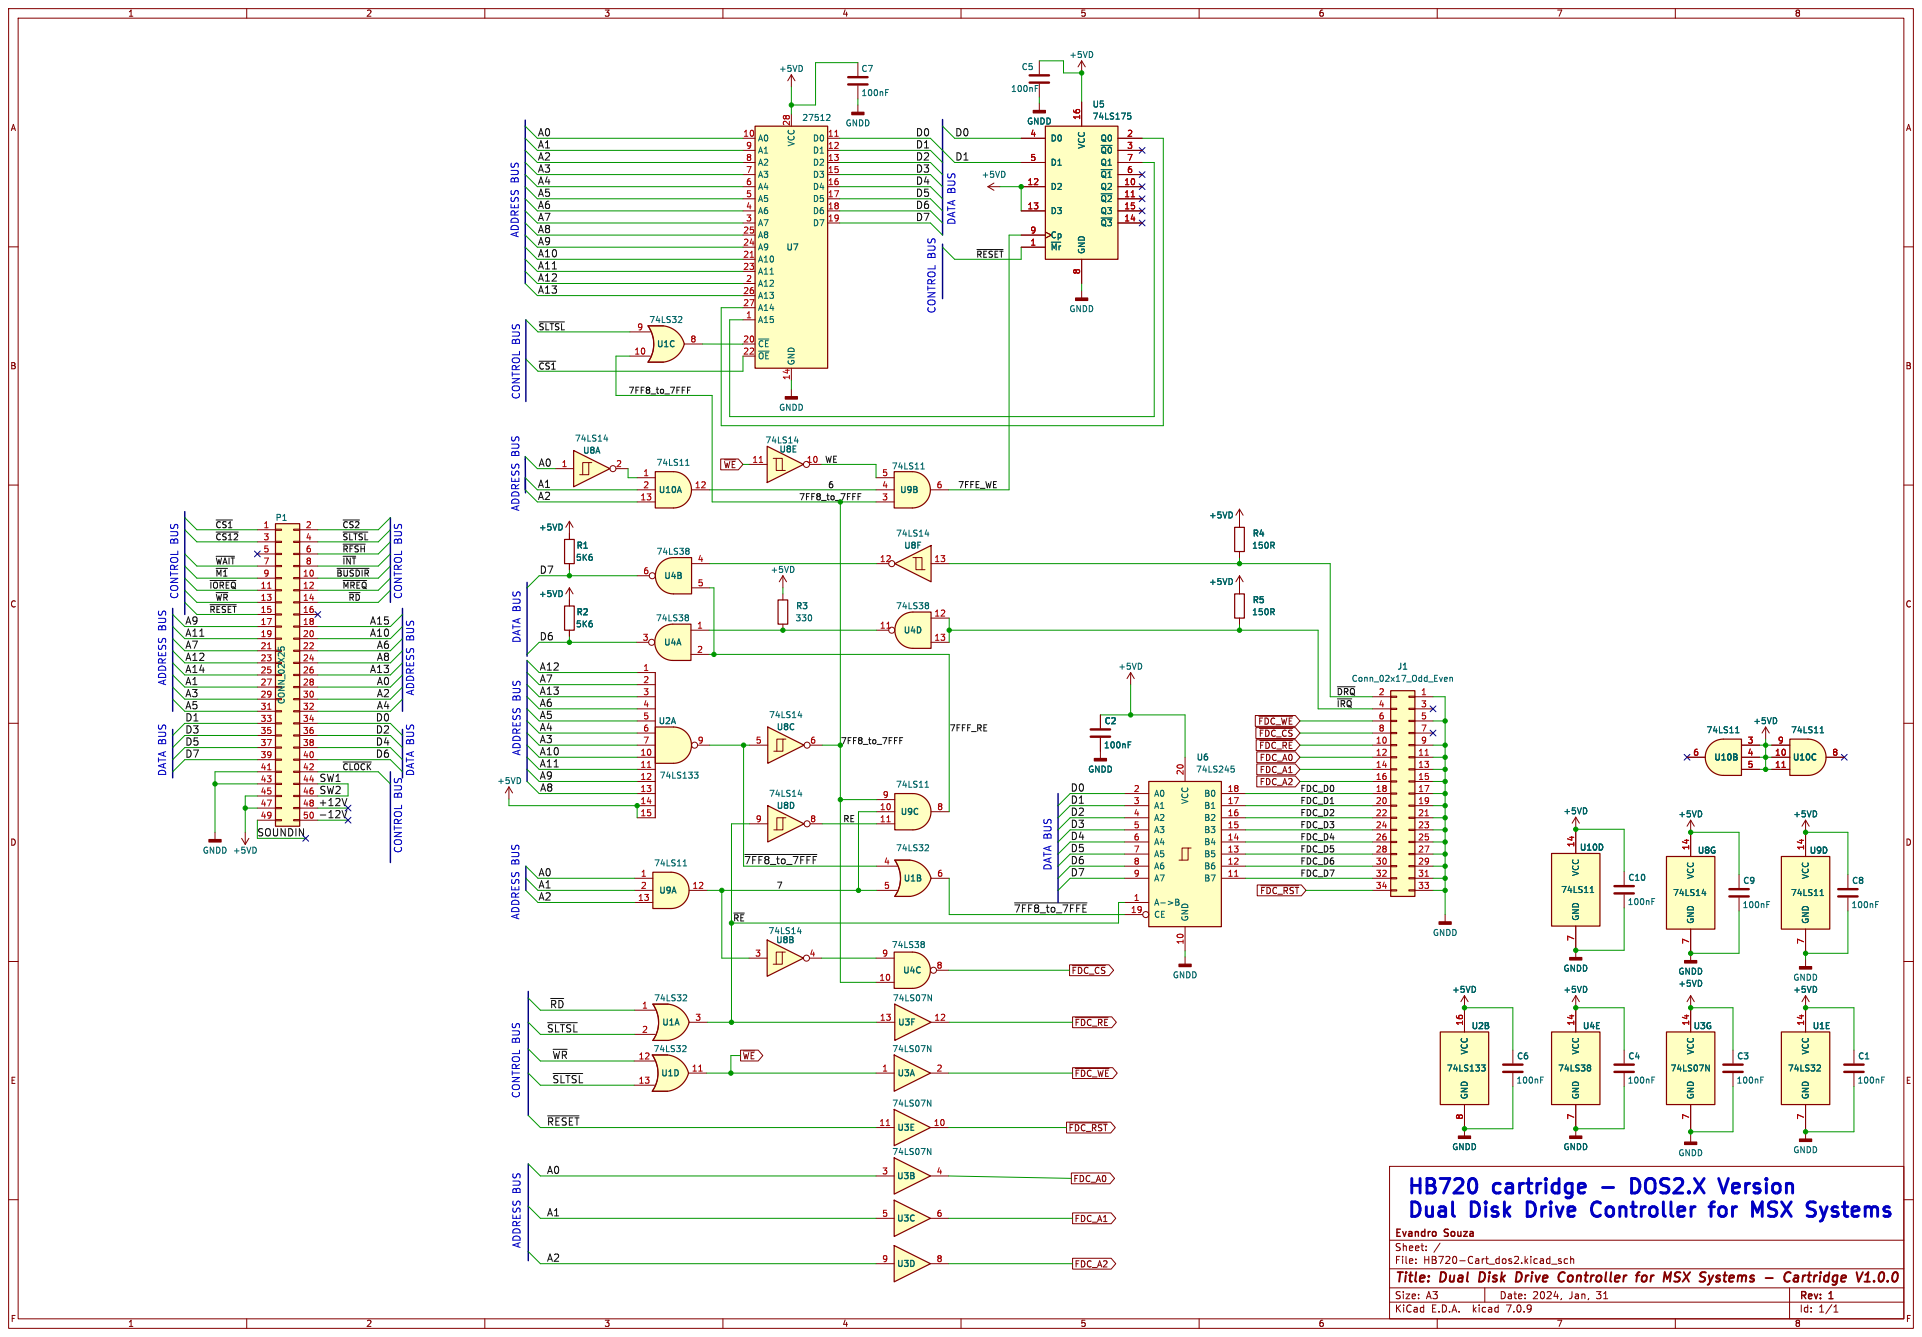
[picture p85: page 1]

Id: 1/1 Title: Dual Disk Drive Controller for MSX Systems - Cartridge V1.0.0

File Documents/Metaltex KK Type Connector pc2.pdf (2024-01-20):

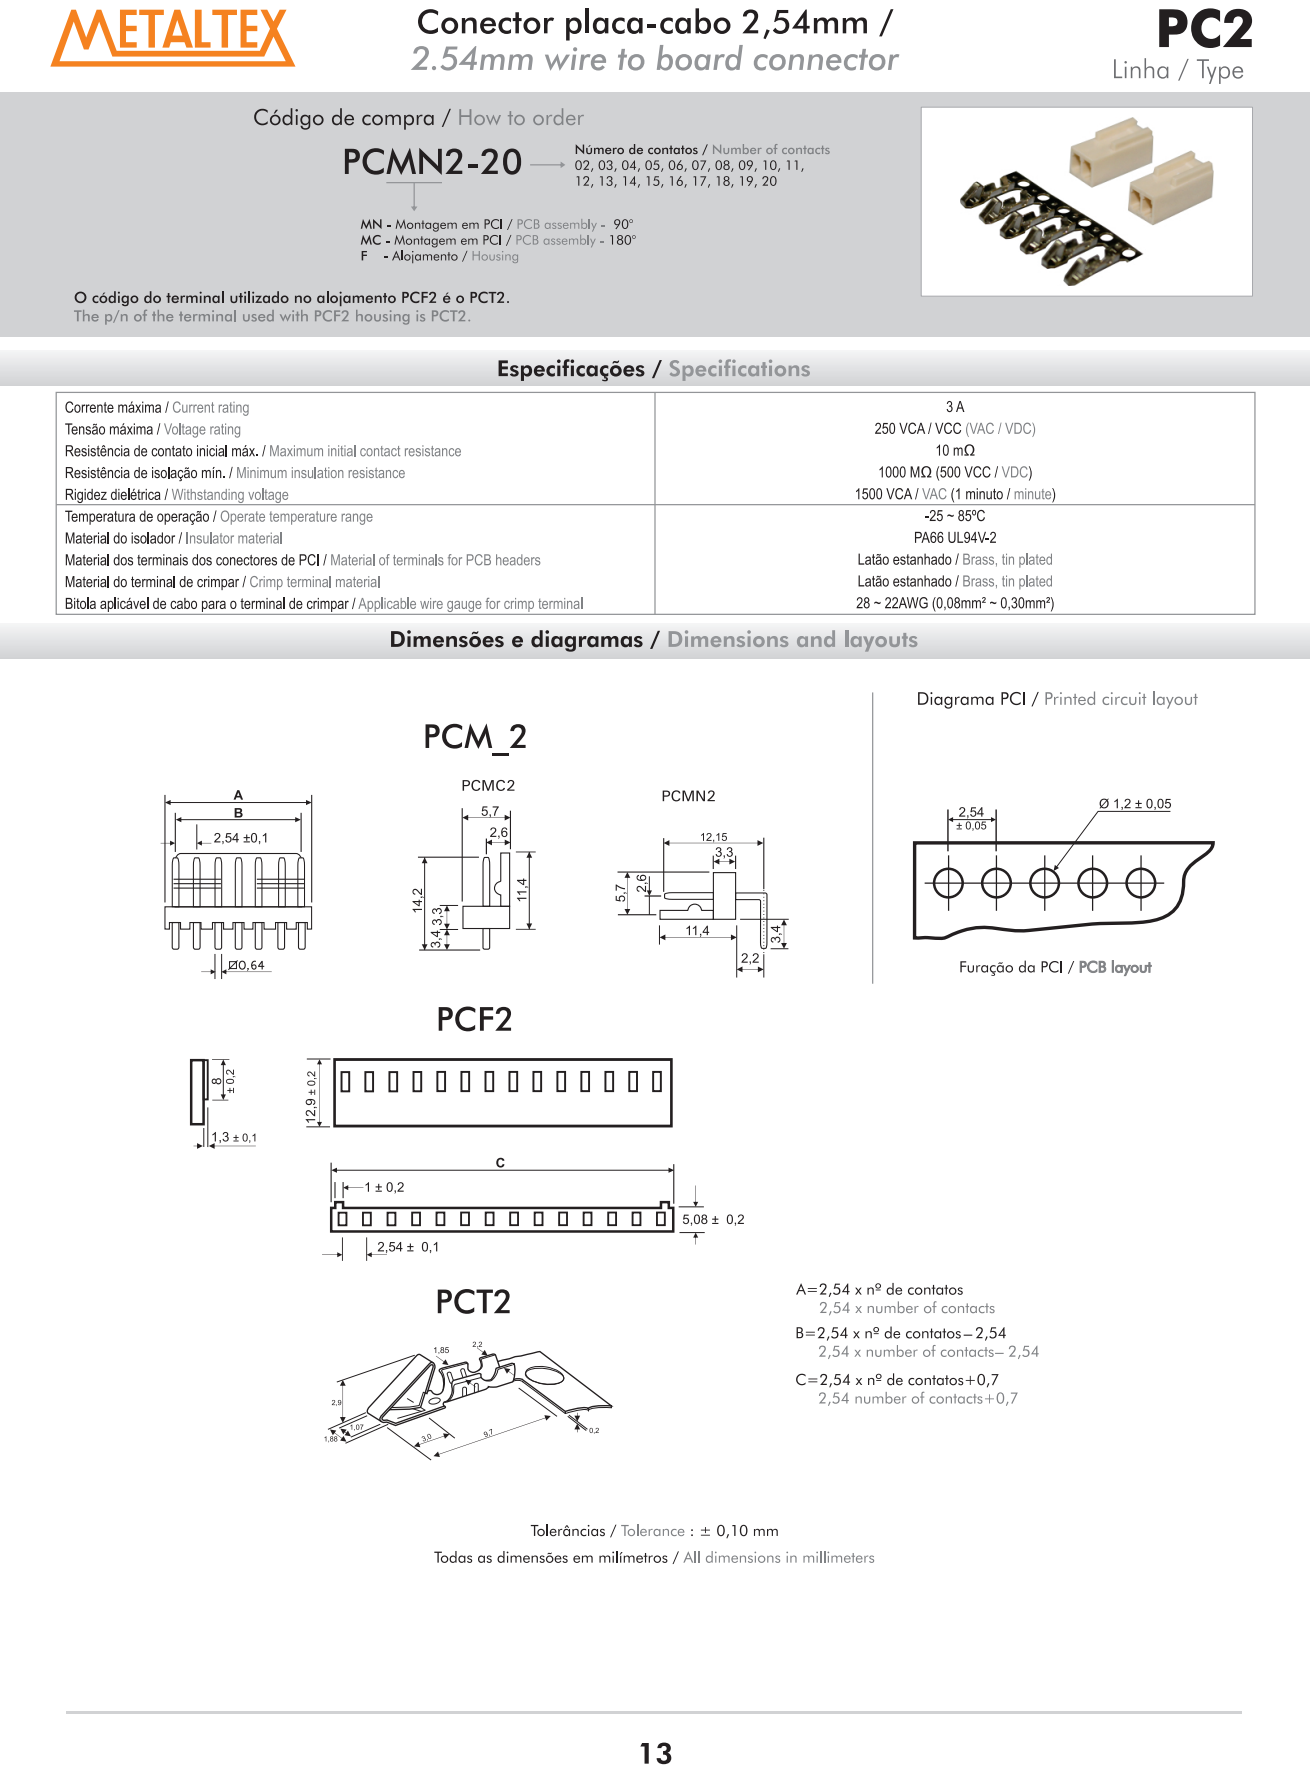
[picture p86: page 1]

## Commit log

2024-01-10 Gerber files - Initil uploads
    Aplicable to both boards: Cartridge and FDC.
    [HB720-Cart-B_Cu.gbr, HB720-Cart-B_Fab.gbr, HB720-Cart-B_Mask.gbr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]
2024-01-10 Initial upload
    Applicable to both boards: Cartridge and FDC.
    [HB720-Cart-B_Cu.gbr, HB720-Cart-B_Fab.gbr, HB720-Cart-B_Mask.gbr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]
2024-01-18 Add files via upload
    Rename file (Add the word Schematics).
2024-01-20 Gerber files upload
    Initial upload of the gerber files of the logical boards.
    [HB-720_FDC-B_Adhesive.gbr, HB-720_FDC-B_Cu.gbr, HB-720_FDC-B_Mask.gbr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]
2024-01-21 Advanced topic upload
    This file is an advanced reference not only to software developers, but is a reference to hardware designers too. I just concluded the translation from japanese to english, with help of yandex transl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
    I attached here the original file I got, partially translated, as reference.
    Thank you very much, HRA, the original writer of this remarkable document!
